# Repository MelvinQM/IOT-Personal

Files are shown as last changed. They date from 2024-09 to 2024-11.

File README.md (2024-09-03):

# IoT Start Project

This is your IoT Gitlab project. You can use it to store your code and documentation. 

## Getting Started

This project contains a setup using Docker. This will help you setup all the necessary tools to start developing your IoT project.
Before you run the docker-compose command, make sure you have to make changes to the configuration. You can find these in
the `.env` file.

Now, to install and start your project; run the following command in the root of your project:

```bash
docker-compose up -d
```

If everything runs correctly, you should be able to visit your website at [http://localhost/](http://localhost/).

## Structure

There is a specific structure that you should follow when developing your project. This will help you to keep your project organized and easy to understand.

**Documentation**

All the documentation of your project should be placed in the `docs/` folder. This will be used for your portfolio-website.

```bash
├── docs/
```

**Embedded**

Everything you need to run your embedded application should be placed in the `embedded/` folder. This includes the source code like .ino-files from Arduino.

```bash
├── embedded/
```

**Web**

Everything you need to run your web application should be placed in the `web/` folder. This includes the source code like PHP, HTML, CSS, Javascript and images.

```bash
├── web/
```

You can visit your website by going to [http://localhost/](http://localhost/) in your browser. And you can find your IoT dashboard at [http://localhost/dashboard](http://localhost/dashboard).

## Database details

The database is a MySQL database using MariaDB. You can connect to it using the following details:

| Parameter | Value |
| --- | --- |
| Host | `mariadb` (from PHP) `localhost` (from your laptop) |
| Port | `3306` |
| Username | `root` |
| Password | You can find this in your .env-file. |
| Database | You need to create the database yourself. |

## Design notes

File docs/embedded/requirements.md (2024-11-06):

# Requirements

## Contents
1. **[Embedded Requirements](#1-embedded-requirements)**
2. **[HTTP Client (EMBRQ#01)](#2-http-client-embrq01)**
3. **[HTTP Server (EMBRQ#02)](#3-http-server-embrq02)**
4. **[Inputs (EMBRQ#03)](#4-inputs-embrq03)**
5. **[Outputs (EMBRQ#04)](#5-outputs-embrq04)**
6. **[WiFiManager (EMBRQ#05)](#6-wifimanager-embrq05)**

## 1. Embedded Requirements
One of the given assignments for the minor IoT was to create an Embedde device. This device has to fulfill these 5 embedded requirements (EMBRQ):

| Requirement ID | Requirement | MoSCoW | Compliant |
|---|---|---|---|
| EMBRQ#01 | The embedded device acts as a client and sends measured sensor data to the application backend over HTTP or HTTPS. | MUST | YES |
| EMBRQ#02 | The embedded device also acts as a server and receives status messages from the application backend over HTTP or HTTPS. | MUST | YES |
| EMBRQ#03 | The embedded device contains at least two types of input sensors (e.g., LDR, buttons, joystick, capacitive touch, etc.). | MUST | YES |
| EMBRQ#04 | The embedded device contains at least two types of visual and/or sensory outputs (e.g., LED, LED Matrix, 7-segment display, motor, servo, actuator, LCD-screen, buzzer, etc.). | MUST | YES |
| EMBRQ#05 | The embedded device uses the WiFiManager for configuration of SSID and password (PWD) for connecting to the network. | MUST | YES |

## 2. Accomplishments

### 2.1 HTTP Client (EMBRQ#01)
[Code Documentation](code#221-api-connection-through-wifimanager)

To fulfill the requirement of having the Embedded device serve as an HTTP client a connection with the API was established. The class defined in the Game Console `Connections.cpp` has functionality to `POST`, `PATCH` and `GET` various data. 

Methods Utilized in `Connections.cpp`:

- `fetchPlayers()`: Sends a GET request to retrieve a list of players from the API. This method returns player data that can be used to verify player existence or retrieve player statistics.
- `getSessionById()`: Sends a GET request with a specific session ID to retrieve the session details. The response includes session information, such as the session ID, associated player ID, and any other relevant session data. This method is crucial for polling until a session is associated with a player.
- `getHighscores()`: Sends a GET request to fetch the list of high scores. This method retrieves the top scores across all sessions and players, displaying leaderboard data on the game console's screen.
- `createScore()`: Sends a POST request to submit a new score to the API. This method takes the player’s score and session ID as inputs, creating a score record in the database for tracking gameplay performance.
- `createSession()`: Sends a POST request to start a new session for the game. The API responds with a session ID, which is polled until the game can confirm a valid session setup.
- `endSession()`: Sends a PATCH request to mark a session as ended. This method updates the session status, ensuring no further game actions can be recorded for that session.

createPlayer(): Sends a POST request to add a new player to the database. This method is called when a new player registers for the game, ensuring that the player data is stored for future sessions and scores.

### 2.2 HTTP Server (EMBRQ#02)
[Code Documentation](code#221-api-connection-through-wifimanager)

The requirement is achieved through continuous polling mechanisms for session and player creation.

**Session Creation**:
The device repeatedly invokes createSession() until a valid session ID is returned. This polling mechanism ensures that the game initializes with a unique session for each player.

**Session and Player Binding**:
After obtaining a session ID, the game console polls getSessionById() until the session object contains a player_id. This ensures that the game session only starts when a player has been connected through the frontend form.

Methods Utilized in `Connections.cpp`:

- `createSession()`: Initializes a new game session by sending a POST request to the API. This method is polled until a session ID is retrieved.
- `getSessionById()`: Retrieves session details, checking if a player_id has been linked to the session. Polling continues until this association is confirmed.

### 2.3 Inputs (EMBRQ#03)
To fullfill the requirement of having at least two types of input sensors (e.g. LDR, buttons, joystick, capacitive touch, etc.). I established functionality for various inputs:

- Gyroscope (MPU6050): For the use of player movement controls.
- Joystick: For the use of player movement controls.
- Button: For the use of player trigger/fire controls.

[MPU6050 code](code#23-gyroscope)

[Joystick code](code#24-joystick)

[Button code](code#25-button)

### 2.4 Outputs (EMBRQ#04)
To fullfill the requirement of having at least two types of visual and/or sensory outputs (e.g. LED, LED Matrix, 7-segment display, motor, servo, actuator, LCD-screen, etc.). I established functionality for various outputs:

- Display: For the use of a all game visuals and gameplay.
- RGB LED indicator: For the use of notifying the user and developers of the console state.
- Vibration Motor/Rumble Pack: For the use in the controller for feedback upon firing.

[Display code](code#27-sprite-rendering)

[RGB LED code](code#28-rgb-led)

[Vibration Motor code](code#26-vibration-motor)

### 2.5 WifiManager (EMBRQ#05)
[Code Documentation](code#221-api-connection-through-wifimanager)

To fulfull the requirement of having a connection to wifi through the use of WiFiManager in favor of just using `WiFi.begin()`. The use of the library WiFiManager was added. Through the use of its autoconnect feature the device will now connect automatically to any network that it remembers. If no network could be found instead of the device not functioning at all instead it will open a portal on its own accesspoint that you can join through your phone or computer. On this portal you can then add the accesspoint of your choosing.

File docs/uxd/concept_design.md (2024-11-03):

# Concept & Design

## Contents
- **[1. Concept](#1-concept)**
    - **[1.1 User Needs](#11-user-needs)**
    - **[1.2 Product Requirements](#12-product-requirements)**
    - **[1.3 Controller Concepts](#13-controller-concepts)**
    - **[1.4 Console Concepts](#14-console-concepts)**
- **[2. Design](#2-design)**
    - **[2.1 Software Decisions](#21-software-decisions)**
    - **[2.2 Controller Prototypes](#22-controller-prototyping)**
    - **[2.3 Console Prototypes](#23-console-prototyping)**

## 1. Concept
The concept for my project is to make a game similair to Duck Hunt. Where the player will be provided a controller and a display. Instead of using the traditional way I will be trying to put my own spin on it. The traditional way is by using an optical sensor in the gun/controller that when pressed will see if it is pointing at a portion of the screen that's white. This is made possible by making the screen go dark except for the duck's hitbox when pressing the trigger. The moment the screen flickers and the sensor sees a white spot on the screen it has hit a duck. 
<div align="center">
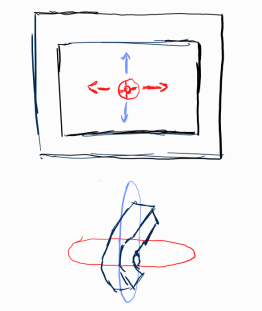
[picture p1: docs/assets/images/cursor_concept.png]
  
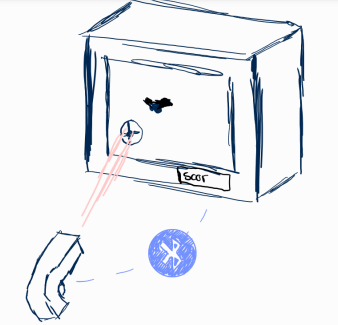
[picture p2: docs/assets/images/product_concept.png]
productconcept
  
</div>

I wanted to put my own spin on it. The controller will have a gyroscope in it allowing it to serve as a motion controller. Similair to the Wii but not exactly as the wii uses a different technique. I wish to emulate the ease of use of the Wii controller but using a different technique.

Additionally the controller will be wireless and communicate with the display through an UDP connection. This will allow the controller to tell the display where to move the cursor.

### 1.1 User Needs
- **Inclusive Age Range**: The system should cater to users of all ages, from retro game enjoyers of old to young kids. This allows more people to enjoy the product and increase the amount of possible users.
- **Ease of Use**: The system must be simple to operate for users of different experience levels. Allowing an ease of access will allow more people to have fun playing the game which is the most important goal.
- **Fun Factor**: The primary goal is to ensure that the gaming experience is enjoyable for everyone. If the game is fun to play more people will be interested in attempting to play the game.
- **Non-Violent Design**: The controller design should avoid looking violent. It must not resemble a traditional gun. Since guns have a negative conotation it is essential to keep away from these kind of topics.
- **Comfortable Grip**: The handle of the controller must be appropriately sized to accommodate users of all ages and hand sizes. Allowing more people to be able to hold the controller allows for more possible players.

### 1.2 Product requirements
1. Setup Time
    - **Specific**: Users must be able to set up the game console with clear, step-by-step instructions.
    - **Measurable**: Setup should take no longer than 10 minutes from off to operational state.
    - **Achievable**: Instructions will include visual aids and step-by-step instructions.
    - **Relevant**: This ensures user satisfaction and a positive first experience.
    - **Time-bound**: The setup process should be tested and validated within the ten weeks of development.

2. Controller Design
    - **Specific**: The controller design must be non-violent and visually appealing to a broad demographic.
    - **Measurable**: Conduct surveys with at least 5 potential users to get opinions on appeal and ensure it resonates with all ages.
    - **Achievable**: There will be multiple iterations on concepts based on feedback within the 10 week development time.
    - **Relevant**: This is crucial for players across age groups.
    - **Time-bound**: Final design will be completed within 10 weeks.

3. Ergonomic Comfort
    - **Specific**: The wireless controller should be easy to hold for both children and adults.
    - **Measurable**: User testing with a sample size of at least 5 individuals across different age groups to assess comfort levels on a 1-10 scale.
    - **Achievable**: Feedback will be collected and incorporated into the design in two iterations over a four-month period.
    - **Relevant**: Comfort is important for user satisfaction and prolonged playtime.
    - **Time-bound**: Assessments will be conducted within the initial 10 weeks of development.

4. WiFi Connection Stability
    - **Specific**: The controller must maintain a stable connection to the display.
    - **Measurable**: The connection must not drop within a 10-meter range during continuous gameplay for at least 95% of the time.
    - **Achievable**: Testing in various environments to ensure reliability.
    - **Relevant**: A stable connection is essential for a smooth gaming experience.
    - **Time-bound**: Connection stability testing should be completed by the end of the development within 10 weeks.

### 1.3 Controller concepts
The controller is one of the most important elements of this entire projects. Having a solid concept is essential for the project to feel complete.
Below some concepts can be seen.
<div align="center">
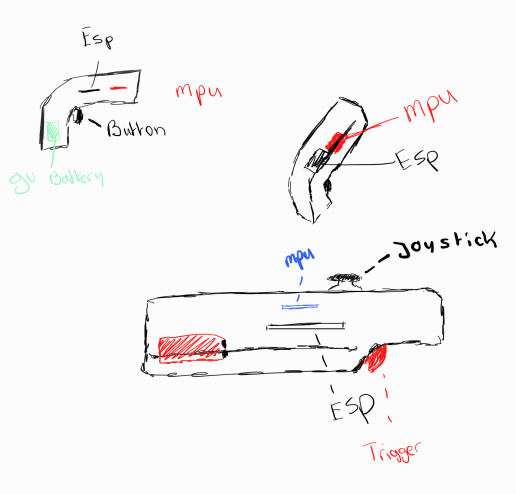
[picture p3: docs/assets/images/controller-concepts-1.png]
  
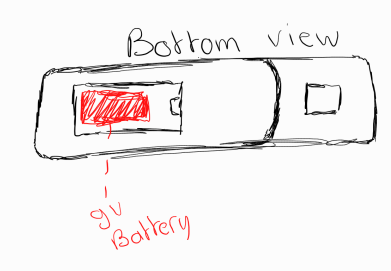
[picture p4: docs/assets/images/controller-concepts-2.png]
  
</div>
<br>
<div style="display: flex; align-items: center;">
  <div style="flex: 1;">
    An additional idea is to allow the controller to be plugged into an attachment to give it more of a gun feel. This allows the controller to be more multi purpose incase of additional games, but still allow it to be fitting for the main game being worked on.
  </div>
  <div style="flex: 1; text-align: right;">
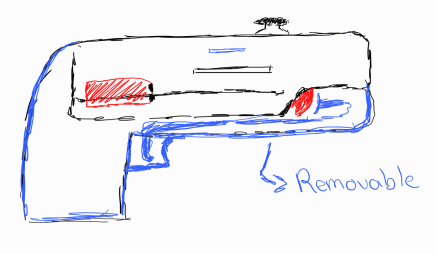
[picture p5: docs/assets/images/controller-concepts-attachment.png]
    
  </div>
</div>
<br>

### 1.4 Console concepts

One of the inspirations for designing the console was from looking at existing 3d models. I came across the following model which seemed like a good fit. [Link]("https://cults3d.com/en/3d-model/gadget/fix-it-felix-jr-cabinet-with-lithophane")
<div align="center">
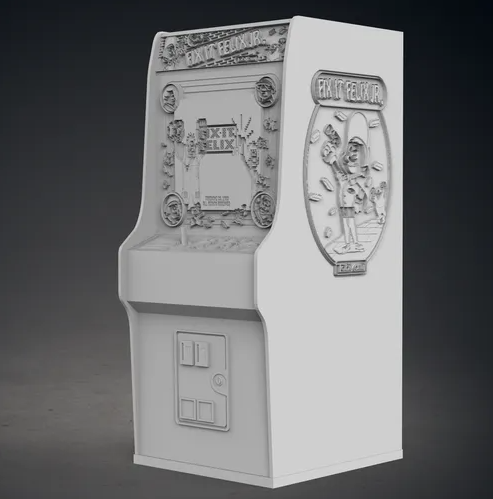
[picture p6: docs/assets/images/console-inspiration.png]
console-inspiration
  
</div>

The console is modeled after a classic arcade cabinet. This cabinet is modeled around the ESP32 display more about this display can be found in the [Embedded Technical Documentation](../embedded/technical_documentation.md#431-esp32-2432s024-esp-display)

### 1.5 Materials
For the purpose of designing and manufacturing a controller and console. The most important factor was being able to make a creative and functional product. This is why a 3D printed design was the most logical option. The controller can be made to have any kind of shape using 3D printing while techniques such as laser cutting would be a lot harder to make work for this purpose. 

## 2. Design

### 2.1 Software decisions

#### 2.1.1 Fusion360
- **Purpose:** Fusion360 is a cloud-based 3D CAD, CAM, and CAE tool for product design and manufacturing, enabling users to create and simulate complex models.
- **Decision for Choosing:** Chosen for its vast amount of features and prior experiences with this program.

#### 2.1.2 Fritzing
- **Purpose:** an open-source software that allows users to design and document electronic circuits, providing a platform for creating schematic diagrams and PCB layouts.
- **Decision for Choosing:** Selected for its user-friendly interface and accessibility for beginners in electronics. This software might be replaced to Fusion Electronics if designing a PCB is in the future plans as I've used Fusion for this in the past.

#### 2.1.3 Aseprite
- **Purpose:** Aseprite is a pixel art program that allows users to create 2D graphics and animations, focusing on pixel art.
- **Decision for Choosing:** A program was required to make low pixel count graphics that low memory for storing on an embedded device.

#### 2.1.4 Bambu Studio
- **Purpose:** Bambu studio is the slicer for the Bambu X1 Carbon 3d printer used in this project.
- **Decision for Choosing:** Bambu studio is the best way to interface with the X1C printer as it is the company's own 3D printing slicer specifically made to use for their printers.

### 2.2 Controller Prototyping
#### 2.2.1 Basic shape
To create the basic shape of the controller a fusion360 tutorial was used. Although this tutorial was in spanish I muted the audio and was still able to follow along quite nicely using the automatically generated subtitles. [Wii controller fusion tutorial](https://www.youtube.com/watch?v=6r9C27qcxtE&ab_channel=LuisAmaya)

This model was to create a basic shape for the controller. 
<div align="center">
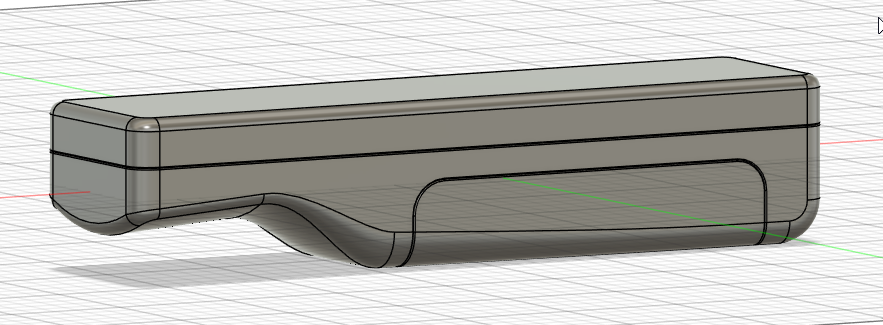
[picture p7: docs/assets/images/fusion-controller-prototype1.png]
fusion-controller-prototype
  
</div>
I then moved around all components around to see if everything would fit. *(This did not include the trigger yet so the spacing might not be correct here)*
<div align="center">
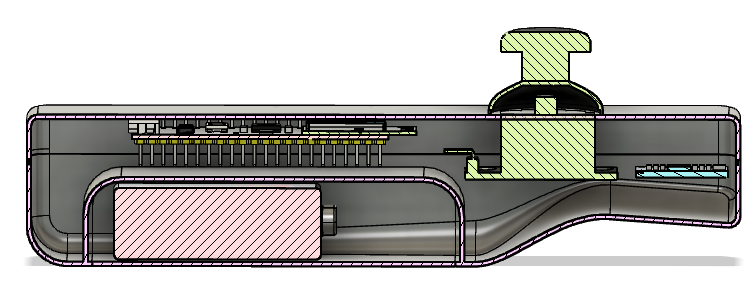
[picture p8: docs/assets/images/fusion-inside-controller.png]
inside-controller
  
</div>

#### 2.2.2 Trigger mechanism

<div style="display: flex; align-items: center;">
  <div style="flex: 1;">
    One of the most important elements of the design was the trigger button. I opened up a wii controller to see how this was handled. I noticed that the button was loose and was connected using a T join see picture below.
  </div>
  <div style="flex: 1; text-align: right;">
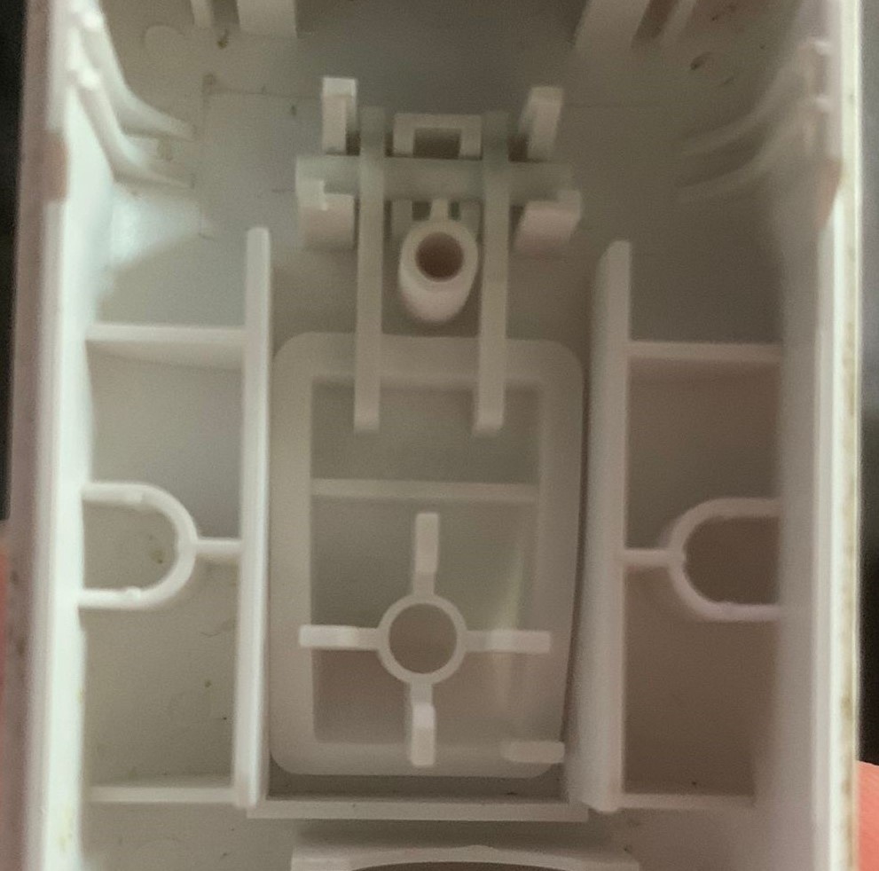
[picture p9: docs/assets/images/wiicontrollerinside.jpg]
wiicontrollerinside
    
  </div>
</div>
<br>
<div style="display: flex; align-items: center;">
  <div style="flex: 1;">
    This joint allows the button to move up and down to press a button. I worked on making a system similair to this. I changed the button to have a sharper edge to allow for easier shooting. The wii controller has a softer edge which could lead to your finger sliding off easier when rapid firing.
  </div>
  <div style="flex: 1; text-align: right;">
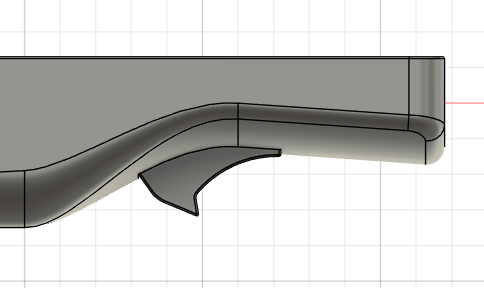
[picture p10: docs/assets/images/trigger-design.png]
trigger-design
    
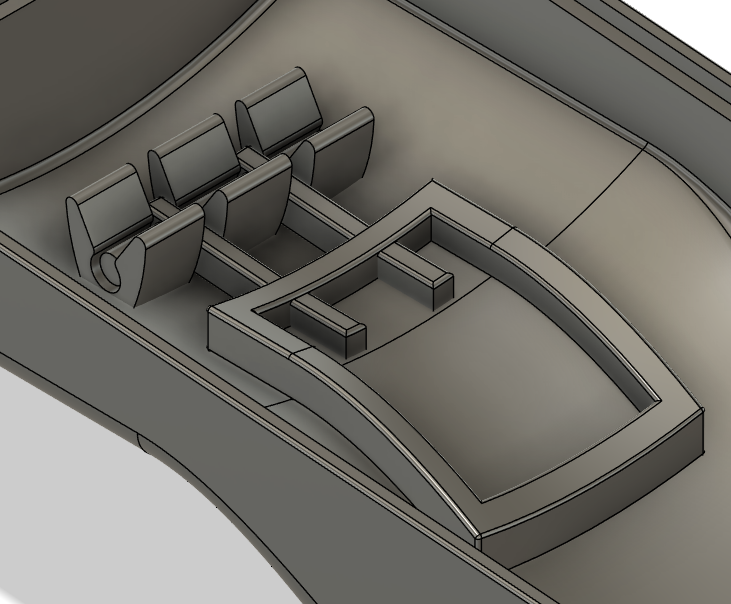
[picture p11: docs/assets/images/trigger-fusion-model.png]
trigger-fusion-model
    
  </div>
</div>
<br>
<div style="display: flex; align-items: center;">
  <div style="flex: 1;">
    After testing with this design through a few iterations a satisfying result was created to allow the trigger to press a switch. 
  </div>
  <div style="flex: 1; text-align: right;">
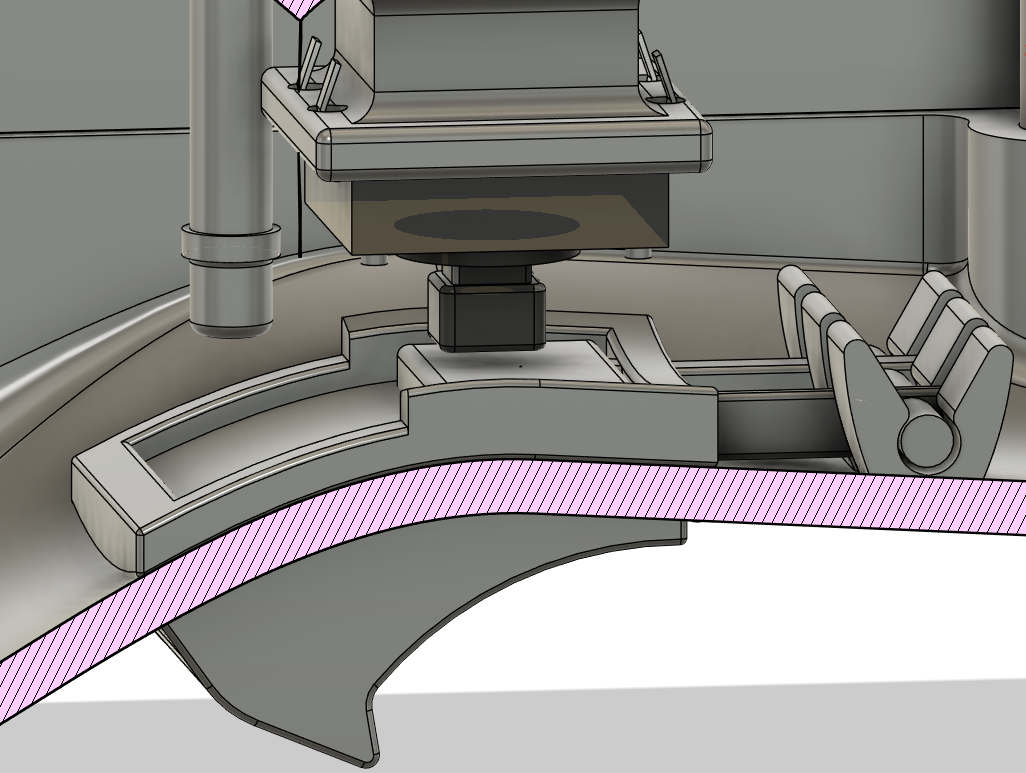
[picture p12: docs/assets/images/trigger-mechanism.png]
trigger-mechanism
    
  </div>
</div>

[Trigger prints can be found here](create_test.md#222-trigger-mechanism)

#### 2.2.3 Joystick Holder
The controller will also have a joystick on the top. To fasten this component a very simple push fit mechanism was used.
<div style="display: flex; justify-content: center; align-items: center;">
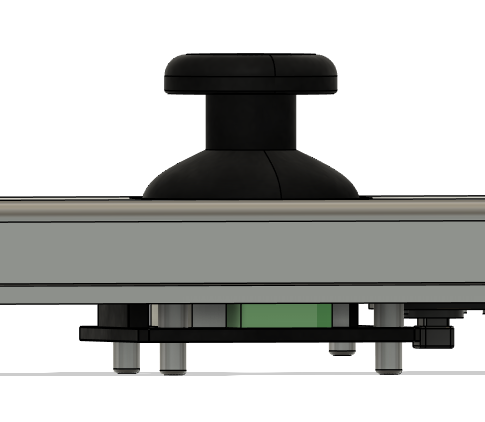
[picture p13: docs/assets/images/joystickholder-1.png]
joystickholder-1
  
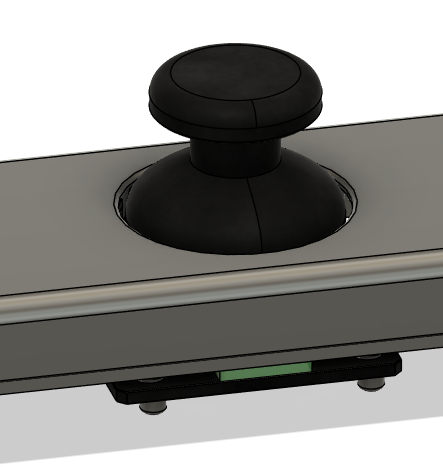
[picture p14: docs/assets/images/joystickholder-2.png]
joystickholder-2
  
</div>

#### 2.2.4 Vibration Motor Holder
The vibration motor had an interesting requirement. The vibrating part had to be against a wall of the print to allow the vibrations to better travel through the plastic and to the player holding it. For that reason the motor was placed at the back facing a wall. The motor is fastened using a slide push fit mechanism.
<div style="display: flex; justify-content: center; align-items: center;">
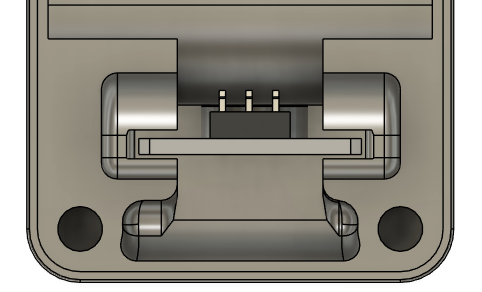
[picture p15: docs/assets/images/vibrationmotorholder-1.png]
  
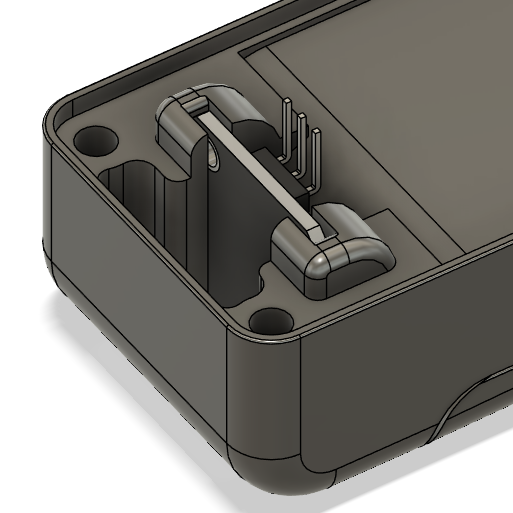
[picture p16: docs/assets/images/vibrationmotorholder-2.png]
  
</div>

#### 2.2.5 MPU6050 Holder
<div style="display: flex; align-items: center;">
  <div style="flex: 1;">
    The holder for the MPU6050 was fixed to the top half of the controller and is fairly simple. The MPU has 2 holes meant for screwing it into constructions since the design did not allow for screws unless the print would be made significantly larger. This is why simple push fit "nubs" were used.
  </div>
  <div style="flex: 1; text-align: right;">
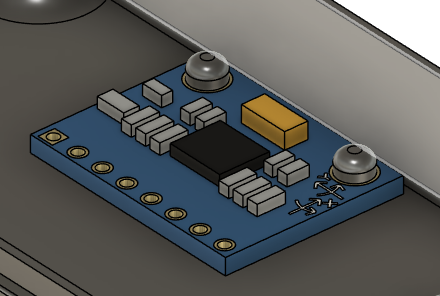
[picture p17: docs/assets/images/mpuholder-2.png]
mpuholder-2
    
  </div>
</div>

#### 2.2.6 DC-DC Converter Holder

<div style="display: flex; align-items: center;">
  <div style="flex: 1;">
    The DC-DC converter is fastened the same way the MPU is. This similarily is fastened to the top half of the controller. Considerations were made to ensure the input of this converter was facing towards the battery cables to reduce the distance between them.
  </div>
  <div style="flex: 1; text-align: right; margin-left: 4px;">
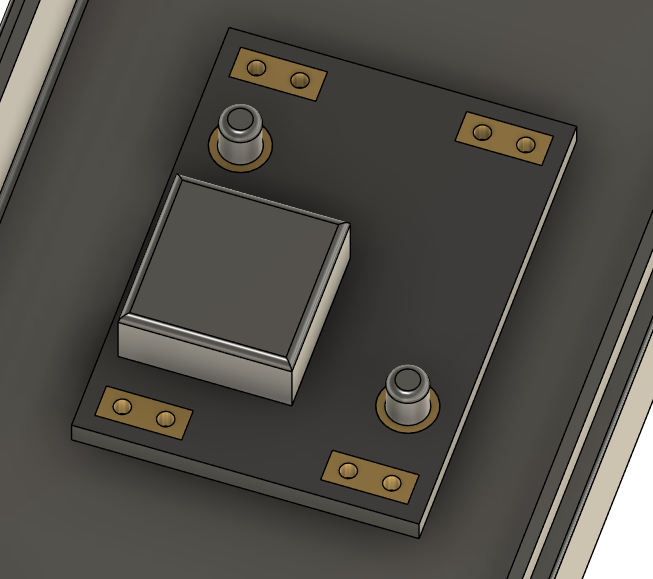
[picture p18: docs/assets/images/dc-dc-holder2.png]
dc-dc-holder2
    
  </div>
</div>

#### 2.2.7 Battery Holder

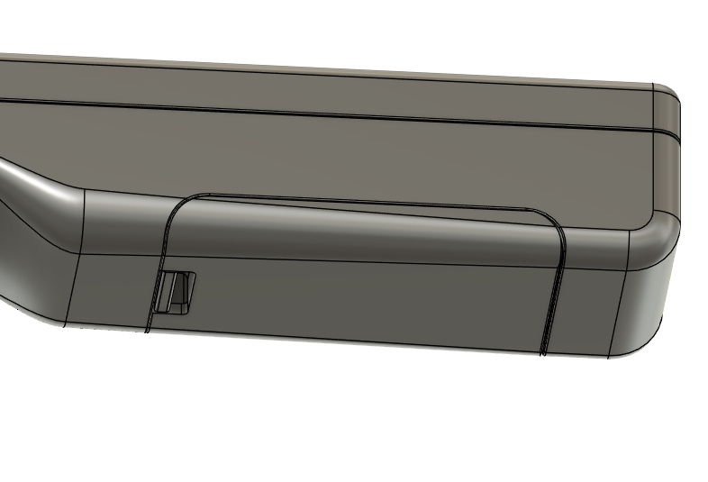
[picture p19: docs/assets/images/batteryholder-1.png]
batteryholder-1


<div style="display: flex; align-items: center;">
  <div style="flex: 1;">
    To hold in a battery in the battery compartment, a battery lid mechanism was designed. By looking at the Wii controller as inspiration a similair mechanism was designed. This mechanism is also used in many television remotes. The basic idea is to use 2 nubs at the back to fast the lid into position first then to close it the front lid bends slightly to fit into place. Once into place it can be removed by bending this same front lid back and then pull it out.
  </div>
  <div style="flex: 1; text-align: right;">
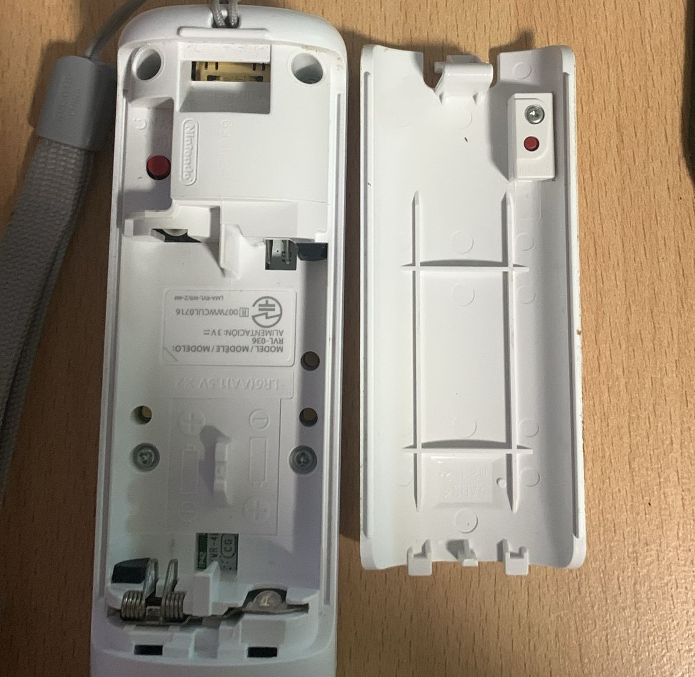
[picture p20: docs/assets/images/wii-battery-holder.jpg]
wii-battery-holder
    
  </div>
</div>
<br>
<div style="display: flex; align-items: center;">
  <div style="flex: 1;">
    It allows for a small latch that can be openend with the use of a finger nail or a flat head screw driver or something similair. (The plastic used PLA was quite tough and doesn't bend like the traditional remote material. Using a screwdriver is reccomended because of this.)
  </div>
  <div style="flex: 1; text-align: right;">
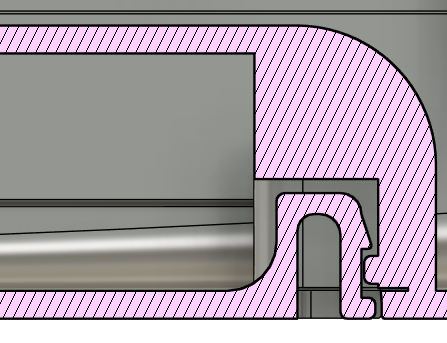
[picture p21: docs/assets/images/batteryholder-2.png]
batteryholder-2
    
  </div>
</div>
<br>
<div style="display: flex; align-items: center;">
  <div style="flex: 1;">
    The battery holder is fit into place using three mechanisms the latch in the front specified earlier. 2 nubs on the back to fit the lid into position.
    And a railing on the side to make sure the battery lid is positioned correctly and doesn't shift.
  </div>
  <div style="flex: 1; text-align: right;">
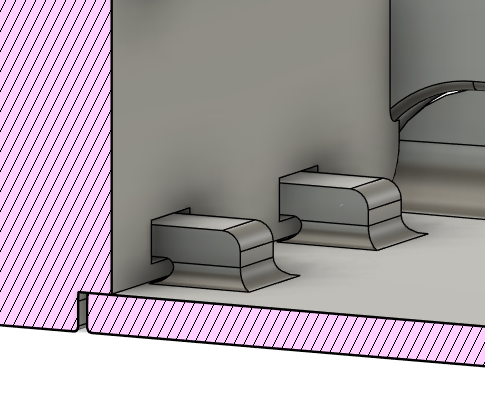
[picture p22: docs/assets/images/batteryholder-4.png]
batteryholder-4
    
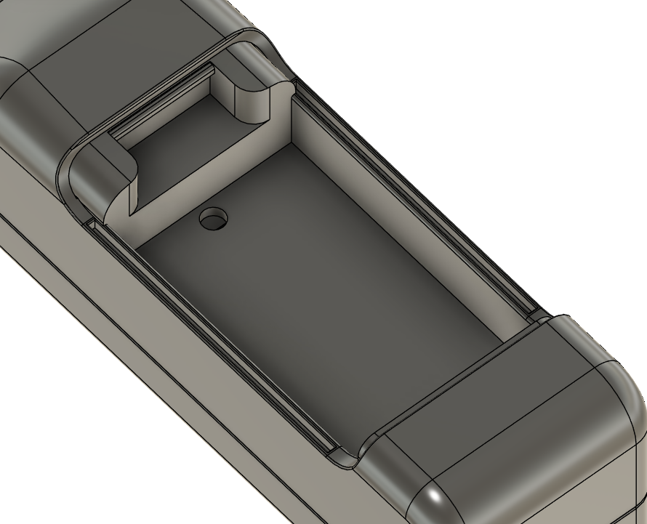
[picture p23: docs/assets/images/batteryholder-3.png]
batteryholder-3
    
  </div>
</div>

#### 2.2.8 Current Controller Design
<div style="display: flex; flex-direction: column;justify-content: center; align-items: center;">
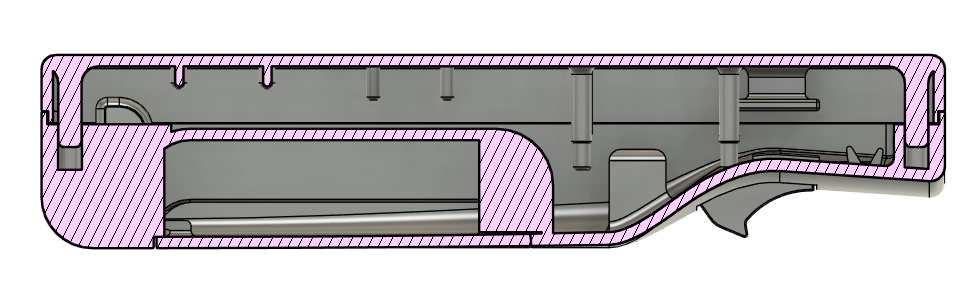
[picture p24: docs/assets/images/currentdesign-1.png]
currentdesign-1
  
  currentdesign-2
</div>

#### 2.2.9 Prototype Breadboard Controller Design
To perform functionality testing the motion controller design above isn't quite optimal. As all the components take up quite a bit of space with wiring reliably testing with components can be quite the challenge. That's why the following controller design was made. It is designed to be a simpler version which can be easily open and closed. By allowing a breadboard to fit experimenting is quite a bit easier.

<div style="display: flex;">
  breadboard-controller-design-1
  breadboard-controller-design-2
</div>

The top and bottom are fitted using 4 push fit holes on the 4 corners and by using the same design for the joystick holder used for the previous motion controller 

### 2.3 Console Prototyping
I started off modeling the chosen display in Fusion360 with accurate measurements to make it easier to design a container around it.
<div align="center">
  espdisplaymodel
</div>

#### 2.3.1 Basic shape
<div style="display: flex; align-items: center;">
  <div style="flex: 1;">
    The basic shape of the console was created using the previous mentioned model as reference. The display has been tilted 10 degrees to allow for easier viewing from a top angle as the console will be quite small.
  </div>
  <div style="flex: 1; text-align: right;">
    consolemodel-1
  </div>
</div>

#### 2.3.2 RGB Led
<div style="display: flex; align-items: center;">
  <div style="flex: 1;">
    To allow the RGB led which is used as an indicator light to provide the user or developer to see the status of the system. A hole was made to allow the light to shine through the enclosure.
  </div>
  <div style="flex: 1; text-align: right;">
    consolemodel-2
  </div>
</div>

#### 2.3.3 USB-C 
<div style="display: flex; align-items: center;">
  <div style="flex: 1;">
    To power the system the use of a usb-c cable is required. To allow for a seamless way to plug this cable in a hole was added with enough tolerance to fit most usb-c cables.
  </div>
  <div style="flex: 1; text-align: right;">
    consolemodel-3
  </div>
</div>

#### 2.3.4 Enclosure assembly
<div style="display: flex; align-items: center;">
  <div style="flex: 1;">
    The enclosure is divided in two halfs. These halves connect through the use of 4 push fit nubs. By allowing for a small amount of tolerance these will allow for opening and closing of the console.
  </div>
  <div style="flex: 1; text-align: right;">
    
    
  </div>
</div>

#### 2.3.5 Banner
<div style="display: flex; align-items: center;">
  <div style="flex: 1;">
    To add some final bit of creativity to the console I added these banners. The banners are printed on its own and slides into the console. This also allows for modularity with the banners to hotswap if needed for example if a new game is able to created one day.
  </div>
  <div style="flex: 1; text-align: right;">
    
  </div>
</div>

#### 2.2.8 Current Console Design
<div style="display: flex; justify-content: center; align-items: center;">
  currentdesign-console-1
  currentdesign-consolen-2
  currentdesign-console-3
</div>

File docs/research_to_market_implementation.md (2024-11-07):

# Implementations & Results

From researching various methods for communicating between an ESP32 Controller and a ESP32 Display various implementations were achieved. Some of these implementations can be found in the [research](research_to_market#4-implementations-and-results) itself.

The main implementation drawn from the research is that using ESP-NOW works quite well for this project. You can also find more about this implementation in the [Code](/embedded/code#222-esp-now) documentation.

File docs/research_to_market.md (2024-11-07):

# Research to market

- **[1. Introduction](#1-intro)**
- **[2. Research Question](#2-research-question)**
- **[3. Research Method](#3-research-method)**
- **[4. Implementations and Results](#4-implementations-and-results)**
- **[5. Conclusion](#5-conclusion)**
- **[6. Recommendations](#6-recommendations)**
- **[7. References](#7-references)**

## 1. Intro
During my Minor in Internet of Things I was tasked with making an IoT device. There were some "blueprints" that I could choose from. I ended up choosing the game console blueprint. This blueprint involved creating an Embedded device which would serve as the game. This device needed to connect to an API which handled storing data from sensors and possibly from the game itself into a database. This data has to than be shown on a frontend website. This was the bare minimum required for the project. 

One of my first ideas was to make some sort of motion controller. This idea seemed like a fun project as I could easily introduce new games and functionalities to the controller later on. This controller primarily revolves around a trigger/button that could invoke a reaction on screen and a gyroscope to handle the movement of a digital cursor on screen. The basic idea of having a controllers gyroscopic angles being able to control a cursor on screen is a very expandable idea and made for a perfect route to take my project. The game that fits this gameplay the best is Duck Hunt.

## 2. Research question
A question that arose during the development was how to ensure the communication between the controller and the console. This was crucical for the game's feel and reliability. The following question arose from this thought:

**What is the best method for establishing efficient and reliable communication between an ESP32 display and an ESP32-S3 controller to enable smooth data transmission for a motion-controlled game?**

Subquestions:

- What are some techniques used in existing controllers?
- What techniques are available for wireless communication between two ESP32 devices?
- How can these techniques be implemented in an Arduino environment?

## 3 Research method
To answer the questions a few research methods will be used:

- Literature Review: Investigated existing motion controllers and communication methods.
- Experimental Testing: Conducted trials with different techniques to determine which was best suited for the project.
- Prototype Development: Developed a prototype for each communication method, documenting successes and challenges.

## 4. Implementations and results
### 4.1 Existing motion controllers on the market.
In hopes to answer the sub question "What are some techniques used in existing controllers?" I looked into some products that already exists.
<div style="display: flex; align-items: center;">
    <div style="flex: 1;">
        duckhuntbox
    </div>
    <div style="flex: 1;">
        <h4>Duck Hunt Light Gun</h4>
        <p>Duck hunt was a game for the NES which made use of a so called light gun to shoot flying by ducks on screen. The game was released back in April of 1984 in Japan and later in October 1985 in America. Duck hunt's gameplay involved shooting ducks and clay pigeons. The player got 3 attempts per round to get a certain number of hits or get a gameover. </p>
        <p><span style="font-weight: bold;">Technical Details:</span>The game worked by leveraging the CRT tv technology of the time. The gun consists of a trigger and a photodiode(light sensor). When the trigger is pressed the screen will go black for one frame except for the duck. The duck would light up white causing the light sensor "if aimed correctly" to sense the duck and register it as a hit.</p>
        <p style="font-weight: bold;">Keypoints: Screen flicker, Light sensor</p>
    </div>
</div>

<br>
<hr>

<div style="display: flex; align-items: center;">
  <div style="display: flex; flex-direction: column; justify-content: center; align-items: left; width: 50%;">
      wii-controller
      wiimotionplus
  </div>
  <div style="flex: 1;">
    <h4>Wii Motion Controller</h4>
    <p>The wii motion controller is the signature controller for the Nintendo Wii which released worldwide in 2006. The Wii controller was used for motion control games such as Wii Sports and other wii games. It allowed a digital cursor to be shown on screen based on the angle you pointed the controller at a sensor bar. It also allowed for motion controls such as registering movements such as; shaking, swinging and more.</p>
    <p><span style="font-weight: bold;">Technical Details:</span> Using 2 different systems make motion controls possible; the linear accelerometer and infrared sensor. The linear accelerometer measures the acceleration of gravity when tilted it doesnt receive the full force of gravity onto the sensor allowing to measure the tilt of the controller. It does this in 3 axis to sense the orientation of the wii remote. Later in the lifespan of the Wii the wii motion plus was introduced. This was an optional addition that cold be plugged into the wii controller. This device has a gyroscope that accomplishes a similair result as the accelerometer that is more accurate. The position of the controller relative to the screen is done using the infrared sensors. The Wii is fitted with a infrared light source known at the sensor bar. This bar has 5 infrared lights on both sides. Measuring the position of the two sources on the sensor allows the controller to be able to determine the angle the light is coming from. All of this data would then be transfered to the console through the use of Bluetooth. </p>
    <p style="font-weight: bold;">Keypoints: Accelerometer, Gyroscope, Infrared Sensor, Bluetooth</p>
  </div>
</div>

### 4.2 Techniques for wireless communication between two ESP32 devices.
In hopes to answer the sub question "What techniques are available for wireless communication between two ESP32 devices?" I looked into some products that already exists.
#### 4.2.1 Bluetooth (BLE)
BLE is suited for data transfers that are more bursty and don't require high bandwith. The range of Bluetooth varies on the configuration used. From a few meters to over a kilometer. Using the FEC (Forward Error Correction) the range of a kilometer is made possible. Something to keep in mind is that range and data throughput are not mutually exclusive. For example if you go for a higher range you are reducing the max data throughput.

##### 4.2.1.1 Peripherals and Centrals
A peripheral is the device that sents out "advertisement" data to other devices to discover it. Central is the device that discovers "advertisements" and if the advertisement allows it connects to it.

##### 4.2.1.2 Advertisements and Scanning
When a peripheral sends data called advertisement packets for other devices to discover it. This could lead to discovery or simply just to let the other device read the advertisement data. The central is continously scanning advertisement channels for new advertisement packets from other devices. Some advertisement packets allow connections some are only meant to send out advertisement data.

You can expect to receive the following data from an advertisement packet (Not in all cases):

- Device name
- TX Power level (Transmit power standard BLE: 0dBm)
- Service supported by device
- Appearance ID (Identifies the type of device)

##### 4.2.1.3 Connection
To connect a device to a BLE device a few things need to happen:

- Peripheral starts advertising
- Central scanning for advertisements
- Central needs to send a connection request
- Peripheral responds
- Connection established!

##### 4.2.1.4 Services and Characteristics (Attributes)
How a BLE device organizes and structures the data that it exposes to other devices to discover it. A characteristic represents a piece of information or data that a BLE device wants to expose to other devices. An example of this is sensor data. Another example is a characteristic for allowing another device to control the behaviour of the BLE device.

A service is a grouping of one or more characteristics. Example of this having environmental data like air quality humidity and temperature all represented by a characteristic but grouped into one service called "Environmental Service".

#### 4.2.2 UDP & TCP
Another way of sending data between two ESP32's is by using a wifi connection. Through the use of of wifi many options are available the once looked at were UDP & TCP.

##### 4.2.2.1 UDP
Like all networking protocols UDP is a standaridzed method for transferring data between two devices in a network. UDP is comparatively a lot simpler than most protocols it sends packets (data) directly to the target device without needing a connection. The packets can arrive at a high speed but since there is no connection between the devices you are limited to a one way communication method using UDP. UDP is most used in time sensitive technologies where losing some packets is better than having to wait for the data to arrive. Some common uses for UDP consist of Video streaming, and VoIP (voice over ip) which is a internet based telephone service.

##### 4.2.2.2 TCP
Another way of sending data through a wifi connection is through the use of  TCP or Transmission Control Protocol. TCP together with another protocol namely IP internet protocol is able to send data to a sender while keeping a conneciton between the sender and receiver. The TCP/IP relationship is like sending someone a message that is written on a puzzel through the mail. The puzzle is broken into pieces and each piece then travels through a different route, some of which take longer than others. When the puzzel arrives after traveling through all these routes the packets might be out of order. TCP is then responsible for assembling the puzzle on the other side it will then make sure the order is correct, if there are any missing packets that they get resent and it lets the sender know the puzzle was received. The TCP connection cosists from the moment the first packet is sent to after the final piece is sent.

##### 4.2.2.3 UDP v TCP
The difference between UDP and TCP lies primarily in the handshake the TCP has to do. UDP packets are sent continuously without the need of this. UDP is faster but less reliable because of this. The speed of UDP also has some tradeoffs if a packet is lost in transit it will not be re-sent so for example for messages that are critical to be received this created some risk of losing that data. In the case of the data being crucial the use of TCP would be preferred.

<div align="center">
  TCPvUDP
</div>

#### 4.2.3 ESP-NOW
##### 4.2.3.1 What is it?
ESP-NOW is a communication protocol based on the data-link layer. This reduces the layers of the OSI model from 5 to only one. This allow for data to be transmitted through through the network, transport, session, presentation, and the application layer. There is also no need for packet headers or unpackers on each layer. All of this allows for a quick response reducing the delay caused by packet loss on busy networks.

<div align="center">
  TCPvUDP
</div>

##### 4.2.3.2 Limitations

Althought ESP-NOW sounds perfect for the situation at hand it is important to also look at the limitations provided with using this protocol.

- **Limited Range**: The range is stated by Espressif to reach around **220 meters** under ideal conditions. However, the actual range can vary based on various interferences..
- **Interference**: ESP-NOW operates in the **2.4 GHz band**. This can cause it to experience interferences from other wireless devices and Wi-Fi networks.
- **No Message Acknowledgment**: There is no built-in acknowledgment mechanisms for confirming message delivery. If message reliability is essential, custom acknowledgements will have to be implemented.
- **Limited Data Payload**: ESP-NOW is optimized for small data transmissions, with a **maximum payload of around 250 bytes**. For applications that need high-bandwidth data transfer or larger file exchanges, services like **Arduino Cloud** might be better suited.
- **No Network Infrastructure**: ESP-NOW supports **point-to-point** and **point-to-multipoint** communication but lacks the infrastructure for building complex network topologies. If your application requires a multi-device network or Internet connectivity, consider using additional networking solutions alongside ESP-NOW.
- **Security Considerations**: While ESP-NOW offers basic data security and privacy, it is not as secure as protocols like **HTTPS** or **MQTT** with strong encryption. For projects involving sensitive data, custom security measures will need to be developed to guard against data eavesdropping and unauthorized access.
- **Compatibility**: ESP-NOW is primarily designed for **ESP8266** and **ESP32** microcontrollers. While it can be used with other ESP32-based devices, compatibility with non-ESP platforms may vary.

### 4.3 Implementing techniques in an Arduino environment
In hopes to answer the sub question "How can these techniques be implemented in an Arduino environment?" I looked into some products that already exists.
#### 4.3.1 Bluetooth
To implement a bluetooth connection on the project first off a library to manage all the bluetooth connection was used. The library that can be used for this is is the BLE library that's in the arduino core for esp32 devices. This library allows for both client and server functionality. A bluetooth server is established on the console which a bluetooth client can connect to. This client would be in this case the controller. The controller then sends data through a characteristic allowing for data transmission.

This method seemed to work well at first but quickly issues arose when trying to use it together with a Wifi connecting. The console's screen refused to turn on when both bluetooth and wifi were running at the same time. A workaround should exist allowing for the antenna used to be shared between wifi and bluetooth but further research is required to get this functioning. The code used for this implementation can be found in `embedded/ESP32-Controller/Deprecated` for the client code and `embedded/ESP32-Display-Board/Deprecated` for the server code.

#### 4.3.2 UDP
The client code for this can be found in `embedded/ESP32-Controller/include/udp_connection.h` and `embedded/ESP32-Controller/src/udp_connection.cpp`. The server code can be found in `embedded/ESP32-Display-Board/include/connections.h` and `embedded/ESP32-Display-Board/src/connections.cpp`. The UDP method can be implemented through the use of the arduino core `Wifi.h` header and the `WiFiUdp.h` header. The console established a SoftAP which is an accesspoint with a static ip allowing for the controller to be able to connect to it without having to change any settings. The connection is able to be succesfully established the console will listen for UDP packets using. This listener listens in a fixed rate continuously. 

The controller upon connecting to the SoftAP will start sending packets containing the controller data to the console. This works decently well with some delay. A big problem that does arrise is that when sending a message such as a button click this message can get lost in the high traffic of the joystick and gyroscope data which needs to be sent at a high frequency.

#### 4.3.3 ESP-NOW
Setting up ESP-NOW is possible through the use of the `esp_now.h` header. A ESP-NOW connection is setup by storing the MAC address of the device on the sender's side of the project. This allowst the sender to find the server and send it data. 

Through testing the ESP-NOW connection is a lot more stable than the UDP connection from earlier.

## 5. Conclusion
This research explored communication methods for a motion-controlled game using ESP32 devices. Various wireless communication options, including BLE, Wi-Fi (UDP/TCP), and ESP-NOW, were considered. While BLE and Wi-Fi are common in existing motion controllers, ESP-NOW emerged as the most promising for this project due to its low latency, efficiency, and minimal overhead.

Despite challenges like range and lack of message acknowledgment, ESP-NOW offers the best balance for the game’s requirements. Future work will focus on optimizing its use and managing interference to improve communication reliability.

## 6. Reccomendations
Future research could focus on optimizing the ESP-NOW architecture even further. Several improvements can still be researched. Subjects like auto pairing and message acknowledgement.

## 7. References
1. Simon Whistler. *How the Gun on the Original Duck Hunt Worked*. Channel: Today I Found Out, Year. [Link](https://www.youtube.com/watch?v=cu83tZIAzlA&t=72s&ab_channel=TodayIFoundOut).
2. TheChiptide. *How did the Wii Remote Actually Work?*. Channel: TheChipTide. [Link](https://www.youtube.com/watch?v=WZUibjOXMqI&ab_channel=TheChiptide).
3. Wikipedia contributors. *Duck Hunt*. Wikipedia, [Link](https://en.wikipedia.org/wiki/Duck_Hunt).
4. Wikipedia contributors. *Wii controller*. Wikipedia, [Link](https://en.wikipedia.org/wiki/Wii_Remote).
5. Cloudflare. *What is UDP?* [Link](https://www.cloudflare.com/learning/ddos/glossary/user-datagram-protocol-udp/)
6. Cloudflare. *What is TCP/IP?* [Link](https://www.cloudflare.com/learning/ddos/glossary/tcp-ip/)
7. NovelBits. *Master BLE Basics in Just 10 Minutes: The Ultimate Guide!* [Link](https://www.youtube.com/watch?v=JSQhRyTKnW4&ab_channel=NovelBits)
8. Espressif. *ESP-NOW* [Link](https://www.espressif.com/en/solutions/low-power-solutions/esp-now#:~:text=ESP%2DNOW%20is%20a%20wireless,ESP32%2DC%20series%20of%20SoCs.)
9. Arduino. *Device to Device Communication with ESP-NOW* [Link](https://docs.arduino.cc/tutorials/nano-esp32/esp-now/)
10. Espressif. *arduino-esp32*. GitHub [Link](https://github.com/espressif/arduino-esp32/tree/master/libraries/BLE)

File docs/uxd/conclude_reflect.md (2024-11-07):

# Conclude & Reflect

## 1. Product Evaluation Report

### 1.1 **Usability Assessment**

- **Product Usability**: The product is functional for the intended use, meeting most of the selected requirements defined in [Product Requirements](../concept_design#12-product-requirements). The controller and console work as expected, with reliable data transmission between the controller and the console. The interface is intuitive, allowing players to quickly engage with the game, with minimal setup needed. These results were gathered through the use of [User Tests](../create_test#1-user-testing)
- **Aesthetic and Durability Assessment**: The product appears well-designed and durable, showing potential for extended use without significant wear. The controller has a comfortable design with sufficient feedback from buttons and joystick, and the console offers clear visuals. Design considerations were made for user experience, with attention to aesthetics and robustness. The materials used for the housing are solid, though further testing on impact resistance is recommended.

### 1.2 **Visual Documentation**

**Controller**:

<div align="center">
    game-controller-1
    game-controller-2
</div>

<div align="center">
    game-controller-3
    game-controller-4
</div>

**Controller Breadboard Variant**:
<div align="center">
    breadboard-controller-conclude-1
    breadboard-controller-conclude-2
</div>

**Console**:

<div align="center">
    game-console-1
    game-console-2
</div>

**Gameplay**:

<div align="center">
    <video src="/../assets/videos/gameplay.mp4" controls alt="game-console-1">
</div>

### 1.3 **Requirements Reflection and Recommendations**
The following requirements were thought of at the start of the designing process:

1. Users must be able to set up the game console with clear, step-by-step instructions.
2. The controller design must be non-violent and visually appealing to a broad demographic.
3. The wireless controller should be easy to hold for both children and adults.
4. The controller must maintain a stable connection to the display.

All requirements were met some of these were tested through the use of [User Tests](../create_test#1-user-testing). WHile the connectivity requirement was researched through the [research to market](/../research_to_market) and experimentation. 

The only requirement which was met but also not met is "The wireless controller should be easy to hold for both children and adults.". The reason this requirement is hard to gauge is because the Wii like Controller was designed to be for this purpose but the final breadboard controller that is used at this moment was not designed with this in mind.

### 1.4 **Failure Documentation**
There were a ton of failures that were not documented but here are some that could be documented with visuals:

**Motion Controller Housing**:

**Objective**: Initial design used walls that were 1mm thick, which proved too fragile. Increasing the thickness to 2mm provided better durability.

**Issue**: The thin walls of the housing were not durable enough, leading to it feeling quite fragile.

**Solution Attempt**: The housing was redesigned with 2mm-thick walls for added strength. The layout of the internal components was adjusted to distribute stress more evenly.

**Future Approach**: If future 3D print design considerations will be done before hand on the outside wall.

**Visuals**: 
<div align="center">
    basic-shape          
</div>

**Trigger mechanism**:

**Objective**: Initial print of the trigger had the T-Shape joint printed using 0.2 mm layer height.

**Issue**: This print had a T-Shape where the cylinder meant to hold onto the holder was not round causing it to be hard to work with.

**Solution Attempt**: The layer height was changed to 0.1 mm allowing for a more detailed circle.

**Future Approach**: For future prints the layer height will be in consideration before printing to prevent such mistakes.

**Visuals**: 
<div align="center">
    basic-shape          
</div>

**Battery Lid Clip**:

**Objective**: The objective was to print a batterylid which would be able to push into the controller and have a small clip bend to fit the lid into place. 

**Issue**: The clip used was too weak and would break if the lid was attempted to be put into the controller, also the railings on the lid which would fit into 2 slots on the controller did not fit.

**Solution Attempt**: The slots on the controller were enlarged a lot since they were only used for placement and not as a push fit. And the battery clip was made thicker and was made to curve less allowing it to be more resistent to snapping when bending.

**Future Approach**: For future prints research should be done to see if there is a better 3D print filament to use for a situation where the material needs to bend slightly as PLA was kind of hard to work with. The battery lid now does work but you cannot open it easily with your finger nail like you would a tv controller. By using a flathead screwdriver it is easy removed but this kind of defeats the purpose.

**Visuals**: 
<div align="center">
    batterylid          
</div>

**Controller Assembly**:

**Objective**: The final design of the controller was done. It was now time to solder all components together and fit them in the controller.

**Issue**: Due to the lack of flexibiliy in the available wires this became quite a problem. Although carefull considerations was done to allow for enough room for components and still have room for wires. The room left for the wires was not nearly enough. 

**Solution Attempt**: Attempts were made to print the controller bigger but it quickly seemed like this wouldn't be so easy as some components were height dependent  and some components like the button didn't have enough room even with a higher lid. The final solution was to remake the whole controller and make a new one. This is where the Breadboard controller comes in. 

**Future Approach**: Although the breadboard controller fullfills the requirements of being a controller for the game. It is not the design that was preferable both based on size and looks. If more time presents itself a PCB would make a great addition as there is plenty of room to add this in the controller. This would also simplify some mechanics such as the button mechanism. A button could soldered to the bottom of the pcb instead of having to make a mechanism to hover the bottom above the trigger.

**Visuals**: 
<div align="center">
    basic-shape          
</div>

## 2. Conclusion
The development of the game console and controller has mostly met the set goals, providing an easy-to-use, reliable system. User tests confirmed the product works well with minimal setup. However, the breadboard controller, while functional, is not optimal in terms of ergonomics and cosmetic design. Future work in getting the original Wii like design working with the use of a PCB is preferred over using the breadboard controller.

Some challenges, such as issues with the housing, trigger mechanism, and battery lid clip, were addressed through design changes. These lessons will help improve future versions.

Overall, the work on this project was very informative and usefull.

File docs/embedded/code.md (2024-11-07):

# Embedded code

## Contents
- **[1. Project Structure](#1-project-structure)**
    - **[1.1 Code conventions](#11-code-conventions)**
    - **[1.2 Platform.io](#12-platformio)**
    - **[1.3 Used Libraries](#13-used-libraries)**
- **[2. Features](#2-features)**
    - **[2.1 Game State Machine](#21-game-statemachine)**
    - **[2.2 Communication](#22-communication)**
    - **[2.3 Gyroscope](#22-gyroscope)**
    - **[2.4 Joystick](#24-joystick)**
    - **[2.5 Button](#25-button)**
    - **[2.6 Vibration Motor](#26-vibration-motor)**
    - **[2.7 Sprite Rendering](#27-sprite-rendering)**
    - **[2.8 RGB LED](#28-rgb-led)**

## 1. Project Structure
### 1.1 Code conventions
The project is written in C++ and to format this code the use of the standard Arduino/C++ conventions were used. These conventions were used to ensure the readability and maintainability of the code. Another benefit is that most libraries follow this format so the code can be consistent.

These conventions consist of most importantly but not exclusively:

- Classes are written in `Camelcase`.
- The use of **guards** in header files is **mandatory** to prevent multiple inclusions.
- Functions and variable names are written using `camelCase`.
- Filenames should be `lowercase` and can include `dashes` or `underscores`.
- Variables declared as a const, and whose value is fixed for the duration of the program, are named with a leading "k" followed by mixed case `kUpdateSpeed` *(not mandatory)*.
- Constants defined using `#define` are written in `SCREAMING_SNAKE_CASE`.

### 1.2 Platform.io
The development environment for this project will be PlatformIO, a platform for embedded systems development. Integrated into Visual Studio Code, it simplifies building, uploading, and monitoring/debugging microcontrollers. PlatformIO supports various board types, including for example the ESP32-S3 and standard ESP32, and provides package management for libraries. The most important benefit of using Platform.io is that I found it easier to work in Object oriented program which arduino doesn't support by default.

### 1.3 Used libraries
|**Library** | **Description** | **Version** |**Environment**|**Creator** | **Link** |
|---|---|---|---|---|---|
|**Arduino** |The Core framework for Arduino projects. |arduino-esp32|All |Arduino |[GitHub](https://github.com/espressif/arduino-esp32) |
|**ArduinoJSON**|Library allowing for easy JSON parsing and creation. |7.2.0 |All |blanchon |[GitHub](https://github.com/bblanchon/ArduinoJson) |
|**WiFiManager**|WiFi Configuration manager with a configuration portal.|2.0.17 |Display |tzapu |[GitHub](https://github.com/tzapu/WiFiManager) |
|**XPT2046** |*Optional* library to use touchscreen functionalities. |0.0.0 |Display |paulstoffregen |[GitHub](https://github.com/PaulStoffregen/XPT2046_Touchscreen)|
|**MPU6050** |MPU-6050 6-axis accelerometer/gyroscope Library. |1.3.1 |Controller |Electronic Cats|[GitHub](https://github.com/ElectronicCats/mpu6050)  |
|**I2Cdev** |I2C device library used in MPU6050 lib |0.0.0 |Controller |jrowberg |[GitHub](https://github.com/jrowberg/i2cdevlib) |

## 2. Features
Features means the diverse capabilities of the system some topics will go over the implementation on both the console and controller while other topics are device specific. This is specified at the start of each topic.

### 2.1. Game statemachine
***--Display logic--***

[game_controller.cpp](https://gitlab.fdmci.hva.nl/IoT/2024-2025-semester-1/individual-project/nuufoowaamee68/-/blob/main/embedded/ESP32-Display-Board/src/game_controller.cpp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)
[game_controller.h](https://gitlab.fdmci.hva.nl/IoT/2024-2025-semester-1/individual-project/nuufoowaamee68/-/blob/main/embedded/ESP32-Display-Board/include/game_controller.h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)

The game that will be run on the game console. Makes use of the following state diagram as a reference for the code structure:
<div align="center">
  game-statemachine.drawio
</div>
As seen in the diagram the game can only go the next state and no differing routes are possible according to this design.

The state is saved by creating an instance of the enum GameState as seen below it starts in the Intro state.
```cpp
enum GameState
{
    Intro,
    Playing,
    EndGame,
    ShowingHighScores,
};
GameState state = Intro;
```

### 2.2 Communication

Controller: [connections.cpp](https://gitlab.fdmci.hva.nl/IoT/2024-2025-semester-1/individual-project/nuufoowaamee68/-/blob/main/embedded/ESP32-Controller/src/connections.cpp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)
Controller: [connections.h](https://gitlab.fdmci.hva.nl/IoT/2024-2025-semester-1/individual-project/nuufoowaamee68/-/blob/main/embedded/ESP32-Controller/include/connections.h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)

Console: [connections.cpp](https://gitlab.fdmci.hva.nl/IoT/2024-2025-semester-1/individual-project/nuufoowaamee68/-/blob/main/embedded/ESP32-Display-Board/src/Connections.cpp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)
Console: [connections.h](https://gitlab.fdmci.hva.nl/IoT/2024-2025-semester-1/individual-project/nuufoowaamee68/-/blob/main/embedded/ESP32-Display-Board/include/Connections.h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)

The `Connections` class provides an interface for initializing and managing the connection for both the controller and console.
The communication between the controller console and the api is handled through WiFi. The connection from the console to the API is handled through a WiFi connection and the connection between the console and the controller is handled through the use of an Access Point and a ESP-NOW connection.

#### 2.2.1 API Connection through WiFiManager
***--Display logic--***

Using the library WiFiManager setting up a connection to a Access Point is relatively simple. 
By calling:
```cpp 
wm.autoConnect(kWifiManagerPortalName, kWifiManagerPortalPassword);
```
The system will first try to connect to any wifi connections already saved in memory. If no connection was found a portal will open. To connect to this portal you will have to connect to the hotspot created named based on `kWifiManagerPortalName`. To connect to this portal you will also need to insert `kWifiManagerPortalPassword`. In this portal you can then select the WiFi accespoint the device should connect to.

Api calls can be made by using the `makeApiCall()` function of the `connections` class.

Various methods are available to perform api calls:

- `fetchPlayers()`: Sends a GET request to retrieve a list of players from the API. This method returns player JSON data that can be used to verify player existence or retrieve player statistics.
- `getSessionById()`: Sends a GET request with a specific session ID to retrieve the session details. The response includes session information, such as the session ID, associated player ID, and any other relevant session data. This method is crucial for polling until a session is associated with a player.
- `getHighscores()`: Sends a GET request to fetch the JSON list of high scores. This method retrieves the top 10 scores across all sessions and players as a JsonDocument.
- `createScore()`: Sends a POST request to submit a new score to the API. This method takes the player’s score and session id as parameters to make this call.
- `createSession()`: Sends a POST request to start a new session for the game. The API responds with a session ID which is returned by the function.
- `endSession()`: Sends a PATCH request to mark a session as ended. This method updates the session status, ensuring no further game actions can be recorded for that session.

#### 2.2.2 ESP-NOW
***--Display and Controller logic--***

***Server Side (Console)***:

The **server side** (console) handles communication with other ESP32 devices over **ESP-NOW**. It initializes the ESP-NOW protocol, registers a peer device, and processes incoming data.

*Initialization*:

- **Wi-Fi Mode**: Set the controller to **Station mode (WIFI_AP_STA)** to send data over ESP-NOW but also be able to connect to a wifi access point.
- **Channel Setting**: Use `esp_wifi_set_channel` to set the Wi-Fi channel to ensure communication between devices on the same channel.
- **ESP-NOW Initialization**: Call `esp_now_init()` to initialize the ESP-NOW communication protocol.
- **Callback Registration**: Register a callback function (`OnDataRecv`) using `esp_now_register_recv_cb` to handle incoming data from peers.
- **Peer Registration**: Use `esp_now_add_peer()` to register the peer (motion controller) by providing the MAC address. Encryption is disabled for simplicity.

*Receiving Data*:

- The callback function `OnDataRecv` is triggered when the server receives data from the peer.
- Incoming data is parsed as JSON. Based on the method in the JSON payload (e.g., `CONTROLLER_AXIS_DATA_METHOD`, `TRIGGER_METHOD`), the server updates its state (e.g., setting gyro data, trigger state, etc.).

***Client Side (Motion Controller)***:

The **client side** (motion controller) communicates with the console using **ESP-NOW** to send data, such as gyroscope, joystick and button data.

*Initialization*:

- **Wi-Fi Mode**: Set the controller to **Station mode (WIFI_STA)**.
- **Channel Setting**: Configure the communication channel using `esp_wifi_set_channel` to match the server’s channel.
- **ESP-NOW Initialization**: Call `esp_now_init()` to initialize the ESP-NOW protocol.
- **Callback Registration**: Register a callback (`OnDataSent`) to handle the status of sent messages.
- **Peer Registration**: Provide the MAC address of the console and add the peer with `esp_now_add_peer()`.

*Sending Data*:

- The `sendData()` method is responsible for sending JSON data to the console.
- Serialize the data into a string and send it using `esp_now_send()` to the console’s MAC address.
- The controller sends different types of data (e.g., gyroscope, joystick values, trigger presses) as JSON payloads. Each method or input type is identified in the JSON payload (e.g., `CONTROLLER_AXIS_DATA_METHOD`, `TRIGGER_METHOD`).

*Example of received data*:
```json
{
    "method": "axisData",
    "data": {
        "gX": 0.0,
        "gY": 0.0,
        "jX": 0.0,
        "gX": 0.0
    }
}
```

### 2.3 Gyroscope
***--Controller logic--***

[gyroscope.cpp](https://gitlab.fdmci.hva.nl/IoT/2024-2025-semester-1/individual-project/nuufoowaamee68/-/blob/main/embedded/ESP32-Controller/src/Gyroscope.cpp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)
[gyroscope.h](https://gitlab.fdmci.hva.nl/IoT/2024-2025-semester-1/individual-project/nuufoowaamee68/-/blob/main/embedded/ESP32-Controller/include/Gyroscope.h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)

The `Gyroscope` class provides an interface for initializing and managing the MPU6050 sensor, which includes a gyroscope and accelerometer. It handles the collection and processing of gyroscope data, including orientation in Euler angles and other sensor readings. 

- **Initialization**: The class sets up the I2C communication with the MPU6050 sensor, checks the connection, and initializes the DMP (Digital Motion Processor).
- **Data Collection**: The class collects sensor data from the MPU6050, including quaternion values, Euler angles, real and world-frame acceleration, and linear acceleration.
- **Data Processing**: It processes raw sensor data to compute screen coordinates based on gyroscope movement.
- **Interrupt Handling**: The class uses an interrupt-based system to trigger data collection when new sensor data is available.

### 2.4 Joystick
***--Controller logic--***

[joystick.cpp](https://gitlab.fdmci.hva.nl/IoT/2024-2025-semester-1/individual-project/nuufoowaamee68/-/blob/main/embedded/ESP32-Controller/src/Joystick.cpp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)
[joystick.h](https://gitlab.fdmci.hva.nl/IoT/2024-2025-semester-1/individual-project/nuufoowaamee68/-/blob/main/embedded/ESP32-Controller/include/Joystick.h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)

The `Joystick` class provides an interface for handling joystick input, including initialization, reading joystick axis values, and detecting button presses. It also includes methods to normalize joystick axis values to a specific range and filter out minor joystick movements (dead zone).

- **Initialization**: Sets up the joystick pins for reading input.
- **Button Detection**: Detects whether the joystick button has been pressed.
- **Axis Reading**: Reads the joystick axis values (X and Y) and normalizes them to a specific range.
- **Dead Zone Handling**: Filters out small joystick movements by applying a dead zone to the normalized axis values.

### 2.5 Button
***--Controller logic--***

[game_controller.cpp](https://gitlab.fdmci.hva.nl/IoT/2024-2025-semester-1/individual-project/nuufoowaamee68/-/blob/main/embedded/ESP32-Display-Board/src/game_controller.cpp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)
[game_controller.h](https://gitlab.fdmci.hva.nl/IoT/2024-2025-semester-1/individual-project/nuufoowaamee68/-/blob/main/embedded/ESP32-Display-Board/include/game_controller.h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)

The button handling logic in the `MotionController` class is responsible for detecting button presses, managing debounce and cooldown times, and triggering vibration feedback when the button is pressed. The button press also sends data to the console via the `sendTriggerInput()` method.

- **Button Press Detection**: Detects when the button is pressed, with debounce to prevent multiple triggers from a single press.
- **Cooldown Mechanism**: Prevents multiple button presses from being registered in quick succession by enforcing a cooldown period.
- **Vibration Feedback**: Activates the vibration motor when the button is pressed, and stops it after a predefined duration.

### 2.6 Vibration motor
***--Controller logic--***

[game_controller.cpp](https://gitlab.fdmci.hva.nl/IoT/2024-2025-semester-1/individual-project/nuufoowaamee68/-/blob/main/embedded/ESP32-Display-Board/src/game_controller.cpp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)
[game_controller.h](https://gitlab.fdmci.hva.nl/IoT/2024-2025-semester-1/individual-project/nuufoowaamee68/-/blob/main/embedded/ESP32-Display-Board/include/game_controller.h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)

The vibration motor logic in the `MotionController` class is responsible for providing feedback to the user when certain actions occur, such as pressing a button. The motor is controlled by activating it at full intensity (PWM) when a button is pressed and deactivating it after a set duration.

- **Vibration Activation**: The vibration motor is activated when a button is pressed, providing feedback to the user.
- **Vibration Duration**: The vibration motor remains active for a specified period, after which it is deactivated automatically.
- **Cooldown Handling**: The vibration motor logic ensures that the motor is not triggered multiple times too quickly, and it is controlled independently of the button press handling logic.

### 2.7 Sprite Rendering
***--Display logic--***

[sprite_renderer.cpp](https://gitlab.fdmci.hva.nl/IoT/2024-2025-semester-1/individual-project/nuufoowaamee68/-/blob/main/embedded/ESP32-Display-Board/src/sprite_renderer.cpp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)
[sprite_renderer.h](https://gitlab.fdmci.hva.nl/IoT/2024-2025-semester-1/individual-project/nuufoowaamee68/-/blob/main/embedded/ESP32-Display-Board/include/sprite_renderer.h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)

The Sprite Rendering logic in the `SpriteRenderer` class is responsible for rendering sprites on the display using the `TFT_eSPI` library. It manages the initialization of the display, rendering of sprites for the cursor, background, owl (enemy) sprites, and UI elements such as score, bullets, and owls killed. The class includes logic for sprite movement, collision detection, user input handling (via joystick or gyro), and game flow management, including different difficulty settings and game state transitions.

- **Display Initialization**: The display is initialized using the `TFT_eSPI` library, and the screen is configured for optimal use with support for rotation and byte swapping.
- **Cursor Movement and Input**: The cursor is controlled via gyro or joystick input, and its position is dynamically updated on the display. It can be used to aim and interact with the game environment.
- **Sprite Animation and Logic**: The owl sprite is animated and moves across the screen, with collision detection to check for hits. If the owl moves offscreen or is missed, it resets to a starting position.
- **Intro and Highscore Screens**: The class renders an introductory screen displaying the session ID and game instructions, and it can also display high scores by fetching data from an external JSON source.
- **End Screen and Replay Option**: At the end of the game, an end screen is displayed with options to play again or end the session, with user interaction based on cursor input.

*Gameplay*:

- **Game Loop Handling**: The class implements a flexible game loop that adapts to the current game state, ensuring smooth sprite rendering and handling owl movement, player input, and collision detection. The loop is initialized based on session settings such as difficulty levels, affecting gameplay mechanics such as speed, score per kill, and the number of bullets available for the player.
- **UI Updates**: The class updates the display to show the player's score, remaining bullets, and other game statistics, keeping the player informed about their progress.
- **Collision Detection**: Detects collisions between the cursor and the owl sprite using bounding box checks to award points for successful hits.

### 2.7.1 Sprite Generation
In this project the use of Sprites is required. To do this sprites were made using Aseprite to make sprites with a small size `ex: 32x32`. After exporting these as pngs they were converted to byte arrays for use in code. 

An [online converter](http://www.rinkydinkelectronics.com/t_imageconverter565.php) was used for this.

### 2.8 RGB LED
***--Display logic--***

[game_controller.cpp](https://gitlab.fdmci.hva.nl/IoT/2024-2025-semester-1/individual-project/nuufoowaamee68/-/blob/main/embedded/ESP32-Display-Board/src/game_controller.cpp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)
[game_controller.h](https://gitlab.fdmci.hva.nl/IoT/2024-2025-semester-1/individual-project/nuufoowaamee68/-/blob/main/embedded/ESP32-Display-Board/include/game_controller.h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)

The RGB LED control logic in the `GameController` class is responsible for managing the RGB LED to provide visual feedback to the user based on the game state. The LED color changes to indicate different game phases such as wifi initialization, polling and gameplay.

- **LED Initialization**: The LED is initialized with a specific pins for the Red, Green and Blue channels, allowing it to control the LED.
- **Dynamic Color Changes**: The LED color is updated dynamically to provide feedback, such as:
    - **Red** during startup.
    - **Blue** during wifi initialization.
    - **Yellow** when the game is waiting for a player to connect.
    - **Green** when the player has successfully connected and the game is in progress.
- **Brightness Control**: The LED brightness can be adjusted by modifying the intensity of the color channels.

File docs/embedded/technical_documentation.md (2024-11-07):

# Technical documentation

## Contents
- **[1. Basic Concept](#1-basic-concept)**
    - **[1.1 Outputs](#11-outputs)**
    - **[1.2 Inputs](#12-inputs)**
    - **[1.3 Extra Components](#13-extra-components)**
    - **[1.4 Component List](#14-component-list)**
- **[2. Bill of Materials](#2-bill-of-materials)**
- **[3. Project Wiring Diagram](#3-project-wiring-diagram)**
- **[4. Components](#4-components)**
    - **[4.1 MPU6050](#41-mpu6050)**
    - **[4.2 ESP32-2432S024 (Display & Led)](#42-esp32-2432s024)**
        - **[4.2.1 ESP32-2432S024 (ESP Display)](#421-esp32-2432s024-esp-display)**
        - **[4.2.2 RGB LED](#422-rgb-led)**
    - **[4.3 Joystick](#43-joystick)**
    - **[4.4 Button](#44-button)**
    - **[4.5 Vibration Motor](#45-vibration-motor)**
    - **[4.6 DC-DC Multi-Output Buck-converter](#46-dc-dc-multi-output-buck-converter-33v5v9v12v)**

## 1. Basic Concept
This project will be an Embedded system take on the game Duck Hunt. This project has as requirement 3 outputs and 3 inputs. The goal is to make a wireless controller capable of moving a digital cursor on a screen.

### 1.1 Outputs
- A ESP32 powered Display
- RGB Led which will display the status through color.
- A Rumble pack in the controller for extra satisfying game feedback.

### 1.2 Inputs
- Gyroscope that will serve as the means of calculating where the cursor on screen should be pointing
- Fire button (This will be a button on the controller which will trigger the fire function of the game).
- Joystick to function as a secondary input for controlling the cursor on screen.

### 1.3 Component list
Below all components are specified for both the console and the controller. The components marked extra are only added if enough time is presented as they are not as important.

- Console
    - External power source (Extra)
        - Power switch (Extra)
    - Display
        - Onboard RGB Led
    - Speaker / Buzzer (Extra)

- Controller
    - External power source / 9v Battery
        - Power Switch (Extra)
        - DC - DC Converter
    - Gyroscope
    - Joystick
    - Trigger button
    - Vibration Motor

## 2. Bill of materials

A Bill of Materials (BOM) is a all encompassing list of parts, materials, and components required to build or assemble a product. It serves as a blueprint/shopping list for all the necessary materials and allows potential builders of this project to ensure all components are available before starting the project.

Below is the table that outlines the necessary parts for this project:

|**Part**|**Manufacturer**|**Description**|**Quantity**|**Price (incl VAT)**|**Subtotal (incl VAT)**|**URL**|
|-|-|-|-|-|-|-|
|MPU6050|Invensense|6 Axis gyroscope & Accelerometer|1|€8,50|€8,50| [Tinytronics](https://www.tinytronics.nl/nl/sensoren/acceleratie-rotatie/mpu-6050-accelerometer-en-gyroscope-3-axis-module-3.3v-5v)|
|ESP32-2432S024 Display |Guition |ESP32 Lvgl/Tft Lcd Display Development Board 240*320 2.4Inch|1|€17,99|€17,99| [Aliexpress](https://nl.aliexpress.com/item/1005005865107357.html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)|
|ESP32-S3|Top Tech Store|ESP32-S3 Development Kit Module|1|€6,39|€6,39| [Aliexpress](https://nl.aliexpress.com/item/1005007310769585.html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)|
|Vibration Motor|DIY Victor|Pwm Vibration Motor, Dc Motor|1|€1,28|€1,28|[Aliexpress](https://nl.aliexpress.com/item/1005006296840332.html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)|
|DC-DC Converter 9v-5v |DFRobot|DFRobot DC-DC Multi-uitgang Buck-converter (3.3V/5V/9V/12V)|1|€5,99|€5,99|[Robotshop](https://eu.robotshop.com/nl/products/dfrobot-dc-dc-multi-uitgang-buck-converter-33v-5v-9v-12v)|
|Joystick Module|DIY TZT|Dual-Axis X/Y Joystick Module|1|€3,65|€3,65|[Aliexpress](https://nl.aliexpress.com/item/1005005985509291.html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)|
|9V Battery|Varta|Long life max power 9V battery Alkaline|1|€3,79|€3,79|[Amazon](https://www.amazon.nl/Varta-4722-Batterijenideaal-brandmelder-stemapparaat/dp/B004WYN62O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)|

## 3 Project wiring diagram
The wiring diagram was created using Fusion360 Electronics. The components were created using a mix of custom made symbols in Fusion360 and some edited versions taken from [SnapEDA](https://www.snapeda.com). All fusion electronics files can be found in docs/assets/diagrams/FusionElectronics/...

A wiring diagram is a visual representation of an electrical circuit, showing the connections between different components. It uses standardized symbols to represent elements like power sources, switches, resistors, and wires. This diagram is useful for understanding how electricity flows through the circuit.

ControllerWiringDiagram

***As the console has no wiring involved no wiring diagram is needed. The console only needs to be connected to power using a USB-C cable.***

## 4. Components
### 4.1 MPU6050 

<div style="display: flex; align-items: center;">
  <div style="flex: 1;">
    <div>
      The MPU is a 6 axis gyroscope and accelerometer. It retrieves data from rotating and moving the component.
      This data can be quite fluctuating and not very precise. The MPU has a built in way of dealing with this called the DMP "Digital Motion Processor".
      This processor runs so called fusion algorithms internally allowing the ESP to receive clean and reliable "fused" motion information. More about this can be read in <a href="https://techexplorations.com/guides/arduino/peripherals/mpu6050/">this article</a>
    </div>
    <br>
    <div>
      The angles of the MPU can be defined using YAW PITCH and ROLL. A visual respresentation of this can be seen in the image shown.
    </div>
  </div>
  <div style="flex: 1; text-align: right;">
    MPU6050
    MPU6050
  </div>
</div>

### 4.2 ESP32-2432S024
#### 4.2.1 ESP32-2432S024 (ESP Display)
<div style="display: flex; align-items: center;">
  <div style="flex: 1;">
    The ESP32-2432S024 or how it will be called for ease of reading the ESP Display is a 2.4 inch display with a resolution of 320x240. This display allows for full color display and touchscreen support. This display has an ESP32 onboard which allows the user to not have to wire anything to communicate from the esp to the display. This board also exposes some extra GPIO pins.

    To use the display a library is required called TFT_eSPI a important fact for using this library is that the library needs to configured before use. This is done by changing the User_Setup.h to use the correct pins and settings. This was all found in the user manual. Provided from the store page which can be found in the [BOM](#2-bill-of-materials)
  </div>
  <div style="flex: 1; text-align: right;">
    rawmpudata
  </div>
</div>

#### 4.2.2 RGB LED
<div style="display: flex; align-items: center;">
  <div style="flex: 1;">
  	The ESP32-2432S024 besides a display also has a RGB led allowing a broad range of colored light to be displayed. This allows the system to display a certain condition through a color indication.

    This Led is used to show certain conditions of the system.
  </div>
  <div style="flex: 1; text-align: right;">
    rawmpudata
  </div>
</div>

### 4.3 Joystick
<div style="display: flex; align-items: center;">
  <div style="flex: 1;">
    The joystick consists of 2 potentiometers one for the x axis and one for the y axis. This allows for 2d coordinate to be determined which in turn can be used for the cursor on screen. The joystick serves as an alternative to using gyro data. The joystick also has a click function so it also serves as a button.
  </div>
  <div style="flex: 1; text-align: right;">
    rawmpudata
  </div>
</div>

### 4.4 Button
<div style="display: flex; align-items: center;">
  <div style="flex: 1;">
    A simple button is also used to be used as the "fire" button and as a general action button. This button simply gives a signal to a connected GPIO pin.
  </div>
  <div style="flex: 1; text-align: right;">
    rawmpudata
  </div>
</div>

### 4.5 Vibration Motor
<div style="display: flex; align-items: center;">
  <div style="flex: 1;">
    The vibration motor serves as a way to provide a feedback to the player when pressing the trigger button. This motor is controlled through the use of a PWM signal. This allows differing levels of vibration to be achieved. The motor must be placed in a way where it is against a wall of the controller to allow for more vibrations to pass through.
  </div>
  <div style="flex: 1; text-align: right;">
    rawmpudata
  </div>
</div>

### 4.6 DC-DC Multi-Output Buck-converter (3.3V/5V/9V/12V)
<div style="display: flex; align-items: center;">
  <div style="flex: 1;">
    This DC-DC stepdown converter serves as the power management for the controller. This component allows the controller to be powered through the use of a 9v battery. The 9 volts is brought down to 5 volts which is able to power an ESP32-S3.
  </div>
  <div style="flex: 1; text-align: right;">
    rawmpudata
  </div>
</div>

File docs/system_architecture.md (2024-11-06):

# System Architecture

## Introduction
A system architecture is essential for building effective, scalable, and maintainable systems. It serves as a blueprint that explains the structure of the components, and interactions within a system stimulating a smooth development. A clear architecture concept enables teams to manage complexity and reduces the risk of critical flaws. By establishing a clear architecture early on in the development process, future problems can be caught early and any adjustments to the infrastructure will be easier to maintain.

## System Architecture Diagram

<div align="center">
  TCPvUDP
</div>

The above diagram shows the communications between a website, api and 2 embedded devices which together create a system abling a person to start a game through a frontend and play this game on an embedded device.

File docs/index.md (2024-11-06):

{{ mdocotion_header('https://images.unsplash.com/photo-1550745165-9bc0b252726f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') }}
# Game console
<div align="center">
  gameconsole
</div>
The project is based on the IoT Minor blueprint Gameconsole
<br>
<br>

# Hoot Pursuit
<div style="display: flex; align-items: center;">
  <div style="flex: 1;">
    <p>The system developed involves the following main components:</p>
    <ul>
      <li>ESP32 - Game Controller</li>
      <li>ESP32 Display - Game Console</li>
      <li>API</li>
      <li>Database</li>
      <li>Website</li>
    </ul>
    <p>
      Together, these components make the game <strong>Hoot Pursuit</strong> a reality! This game is inspired by the classic retro game Duck Hunt but uses joystick and gyroscope controls instead of the LDR mechanism found in Duck Hunt.
    </p>
  </div>
  <div style="flex: 1; text-align: right;">
    project
  </div>
</div>

For more details of the system first see the [System Architecture](system_architecture)

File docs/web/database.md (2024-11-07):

# Database

## Contents
- **[1. Database Overview](#1-database-overview)**
   - **[1.1 Entity-Relationship Diagram (ERD)](#11-entity-relationship-diagram-erd)**
   - **[1.2 EER Diagram](#12-eer-diagram)**
- **[2. Database Setup](#2-database-setup)**
   - **[2.1 MySQL Workbench](#21-mysql-workbench)**
- **[3. Database Design](#3-database-design)**
   - **[3.1 Tables](#31-tables)**
     - **[3.1.1 Player Table](#311-player-table)**
     - **[3.1.2 Score Table](#312-score-table)**
     - **[3.1.3 Session Table](#313-session-table)**
     - **[3.1.4 Difficulty Table](#314-difficulty-table)**
   - **[3.2 Relationships](#32-relationships)**

## 1. Database overview
### 1.1 Entity-Relationship Diagram Diagram (ERD)
Below the ERD is shown. This concept allows the system to be able to store player data through sessions. A session is the time a single player is playing with the game console. A session can contain more than one score. A player can also have more than one session if the same username is used to start a new session this session will be linked to the same player id.

<div align="center">
  ERD
</div>

The player starts the embedded device then is prompted with a session id. The player then goes to the website and fills in their name and session id. This creates the player if the name didnt already exist and binds the session to this player. The device is polling until a player is added to the current session. Only then can the game start

### 1.2 EER Diagram
To realise the previous established ERD this EER diagram was generated from the made tables this shows the different types of data that will be stored and the relation between the tables.
<div align="center">
  EER
</div>

## 2. Database setup
### 2.1 MYSQLWorkbench
To interface with the SQL Database MYSQLWorkbench was used. To connect to the database through this program you need to fill in the sql login details.
<div align="center">
  sqlworkbench
</div>

### 2.2 Initializing database
- Copy the sql script from [databaseInit.sql.](https://gitlab.fdmci.hva.nl/IoT/2024-2025-semester-1/individual-project/nuufoowaamee68/-/blob/main/web/database/databaseInit.sql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)
- Make a new query to an empty database (this can be done through MYSQLWorkbench).
- Paste the script and edit "databasename" to your database name.
- Run the script.

## 3.1 Database Design
### 3.1 Tables
#### 3.1.1 Player table
The player table consists of 2 columns:

- *ID*: the identifier
- name: the players name (Unique)

player-table

#### 3.1.2 Score table
The score table consists of 3 columns:

- *ID*: the identifier.
- session_id: the id of the session the score occured in.
- score: used to store the score count.

score-table

#### 3.1.3 Session table
The session table consists of 6 columns:

- *ID*: the identifier.
- completed: if the session has ended.
- start_time: the start time of the session.
- end_time: the end time of the session.
- player_id: the id of the player which started the session.
- difficulty_id: indicates the selected difficulty of the session.

session-table

#### 3.1.4 Difficulty table
The difficulty table consists of 2 columns:

- *ID*: the identifier.
- name: the name of the difficulty.

difficulty-table

### 3.2 Relationships
Between the mentioned tables some relationships are of note:

- A difficulty can be used in multiple sessions.
- A session can only have one difficulty.
- Player can have multiple sessions.
- A session can only have one player.
- A session can have multiple scores.
- A score can only have one session.

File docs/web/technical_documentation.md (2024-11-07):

# Technical Documentation

## 1. Introduction
The goal of the webapplication for the Hoot Shooter project was to create a retro 'feel' website. The website had as purpose to be the the controller for the game console. The website will have a button allowing to start the game, also through the use of the web portal various game settings will be able to be changed and selected. During gameplay the website will show various usefull information such as the current game session settings and the scores acquired during the session. Besides the website for the user a simple website that shows varous tables filled with data retrieved from the API will also be present. This will allow a direct monitor for the database containing the session and game data. 

To allow for all the communications required with the database an API will also have to be developed to allow for the connectivity through a safe intermediate preventing security risks.

## 2. Technologies Used

### 2.1 Code editor
---
<div style="display: flex; align-items: center;">
  <div style="flex: 1;">
    Visual studio code was my code editor for the development of the web application. I chose VScode as it's a lightweight multi purpose code editor allowing for an easy workflow between front and backend development. VScode also has a enormous library of extensions which allowed for coding language specific syntax highlighting and intellisense. All of this greatly improves the workflow efficiency and effectiveness.
  </div>
  <div style="flex: 1; text-align: right;">
    vscode
  </div>
</div>

### 2.2 Frontend
---
The frontend is built with HTML, CSS, and JavaScript to keep the application lightweight and easy to maintain. This approach was chosen for simplicity and to avoid the overhead of complex frameworks, as the requirements for interactivity and styling are straightforward.
<br>
<div style="display: flex; align-items: center; gap: 10px; ">
    html
    css
    javascript
</div>
<br>

#### 2.2.1 Bootstrap
For the styling Bootstrap was used. Bootstrap is a styling component library allowing for quick good looking html elements without much need to write CSS. This allows for a quick work flow promoting producitivity a great deal. 

### 2.3 Backend
---
#### 2.3.1 PHP
<div style="display: flex; align-items: center;">
  <div style="flex: 1;">
    The backend is developed using PHP, a widely-used scripting language suited for server-side logic. PHP was chosen due to its compatibility with a variety of servers and ease of integration with relational databases, as well as its efficient handling of RESTful API requests.
  </div>
  <div style="flex: 1; text-align: right;">
    php
  </div>
</div>

### 2.4 Database
#### 2.4.1 MariaDB
<div style="display: flex; align-items: center;">
  <div style="flex: 1;">
    The database is a **mariadb** based SQL database. MariaDB is an open-source relational database management system (RDBMS) that is a fork of MySQL. The database can be viewed, monitored and maintained through the use of MySQLWorkbech. More about this can be found on the [Database](/web/database#21-mysqlworkbench) page.
  </div>
  <div style="flex: 1; text-align: right;">
    mariadb
  </div>
</div>

### 2.5 Deployment
---
#### 2.5.1 Docker
<div style="display: flex; align-items: center;">
  <div style="flex: 1;">
    The application is containerized using Docker, ensuring that the environment remains consistent across development, testing, and production. This simplifies dependency management and makes the deployment process more robust and repeatable.
  </div>
  <div style="flex: 1; text-align: right;">
    docker
  </div>
</div>
<br>

#### 2.5.2 Nginx
<div style="display: flex; align-items: center;">
  <div style="flex: 1;">
    Nginx, a high-performance web server and reverse proxy. Nginx is efficienct in handling HTTP requests, its lightweight footprint, and its strong support for concurrent connections allows it to efficiently handle the web server.
  </div>
  <div style="flex: 1; text-align: right;">
    nginx
  </div>
</div>

#### 2.5.3 Testing
To make sure the deployment process was properly tested for use on multiple devices. I've deployed the project on multiple desktops to ensure the project is able to setup without any glaring issues. Tests were also done to ensure the efficiency and effectiveness of the web application. These can be seen in the [Create & Test](../uxd/create_test.md) page.

## 3. Design Decisions

### 3.1 Frontend Structure
#### 3.1.1 Index Page
The frontend is structured with an index page that displays a form for users to initiate the game. Upon submission, the form triggers the game start process, allowing users to interact directly with the game environment.
indexpage

#### 3.1.2 Admin Page
An admin page is included to provide a view of the backend data in a structured format. This page displays tables populated with data retrieved from the API endpoints, allowing developers or system maintainers to manage or review game data effectively. This keeps player interactions and administrative separate, ensuring a more concise user experience and improved maintainability.
adminpage

### 3.2 Backend Structure
#### 3.2.1 API Routing
The backend directs requests to `/api/`, with `api.php` serving as the main entry point. Incoming requests are routed to specific controllers based on URL parameters. For instance, requests to `/api/player/` are routed to the player controller, which handles player-related operations. This allows for an easy to understanding routing pattern for the endpoints.

#### 3.2.1 Controller and Gateway Structure
Each controller has a corresponding gateway class that contains the direct CRUD (Create, Read, Update, Delete) functions with SQL statements. These gateway classes isolate database interactions, allowing controllers to focus on handling the logic and responses. This separation of roles improves code  readability, and maintainability.

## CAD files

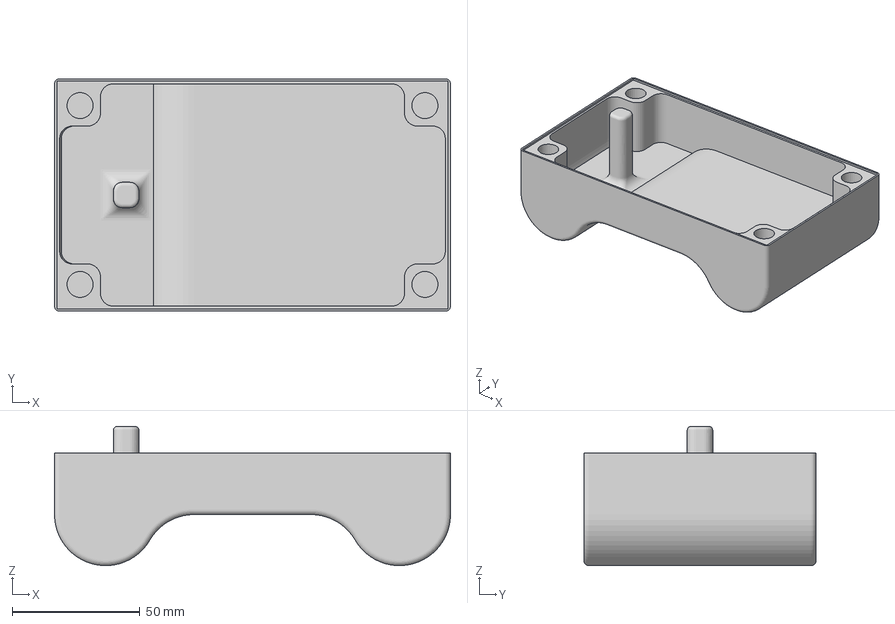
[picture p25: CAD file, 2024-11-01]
docs/assets/3d-files/Breadboard-Controller-Bottom-v5.3mf
155.0 x 91.0 x 54.5 mm

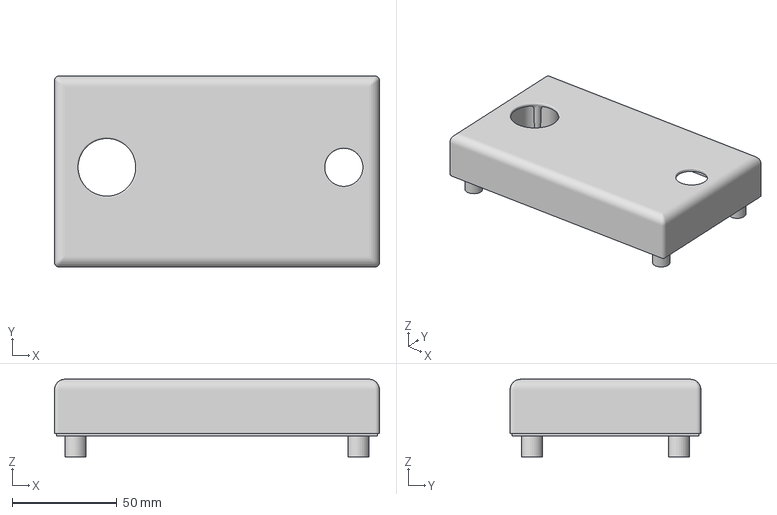
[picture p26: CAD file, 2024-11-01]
docs/assets/3d-files/Breadboard-Controller-Top-v5.3mf
155.0 x 91.0 x 37.0 mm

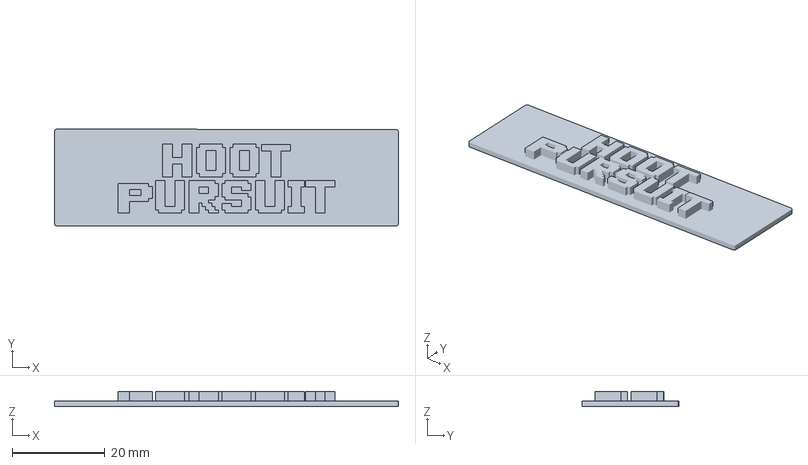
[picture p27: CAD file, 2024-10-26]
docs/assets/3d-files/Console-Banner-v14.3mf
74.2 x 20.9 x 3.15 mm

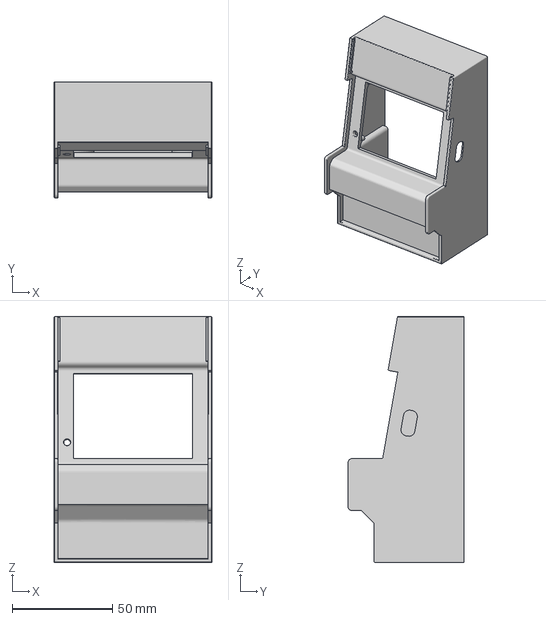
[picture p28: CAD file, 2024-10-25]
docs/assets/3d-files/Console-Front-v8.3mf
78.8 x 58.0 x 123.0 mm

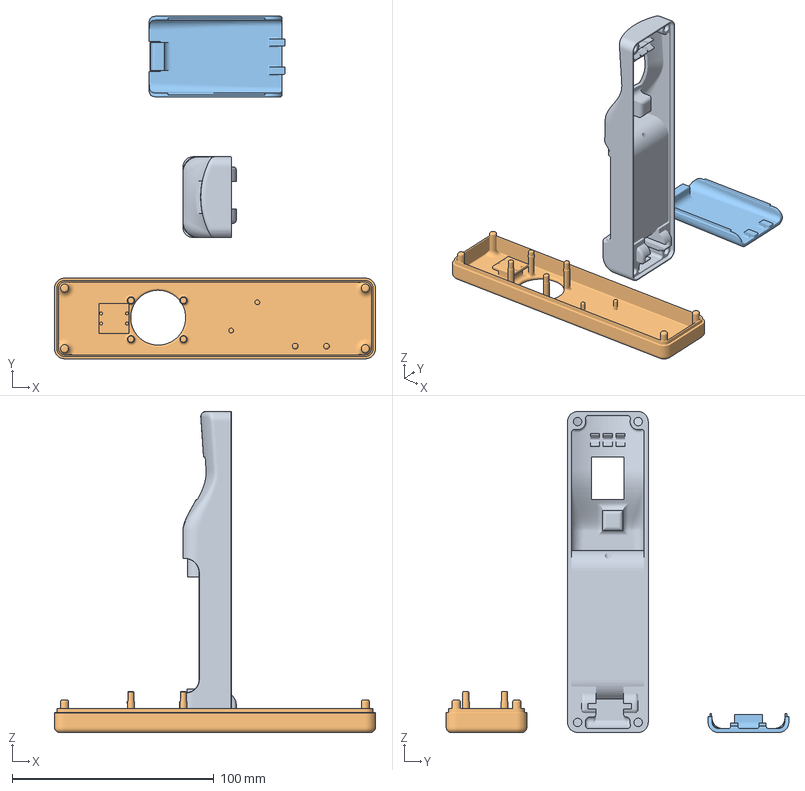
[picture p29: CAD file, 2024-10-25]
docs/assets/3d-files/Bottom-v55.3mf
159.0 x 169.7 x 159.0 mm
Bottom
Top
BatteryLid

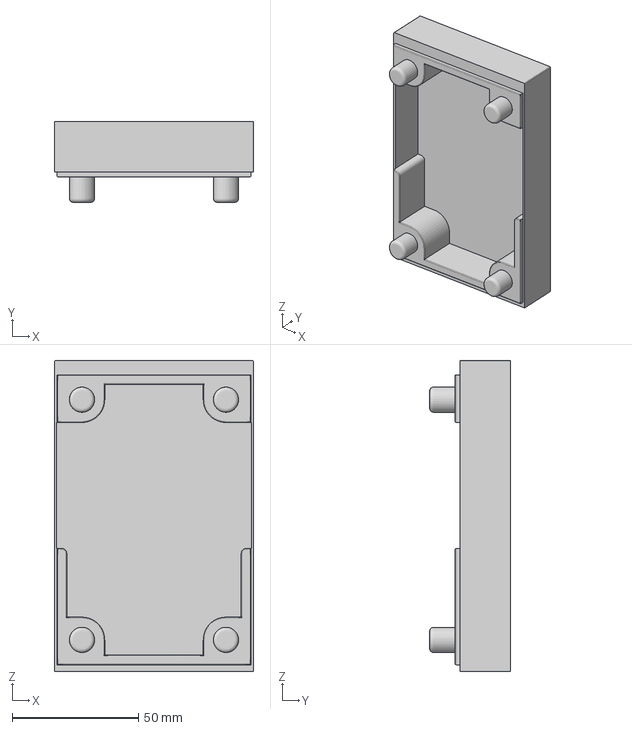
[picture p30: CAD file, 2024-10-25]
docs/assets/3d-files/Console-Back-v8.3mf
78.8 x 31.9 x 123.0 mm

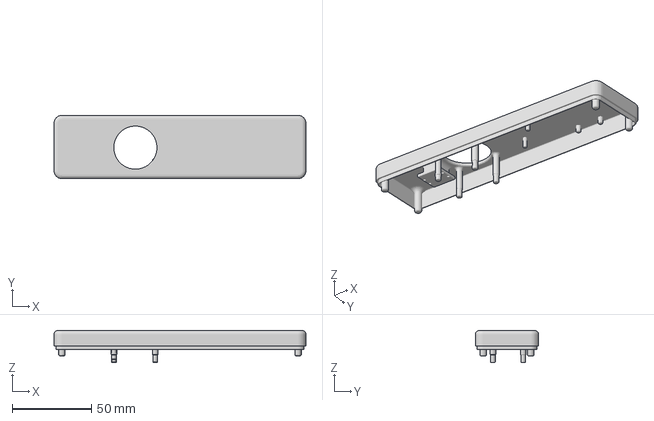
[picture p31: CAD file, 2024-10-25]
docs/assets/3d-files/Top-v55.3mf
159.0 x 40.0 x 20.3 mm

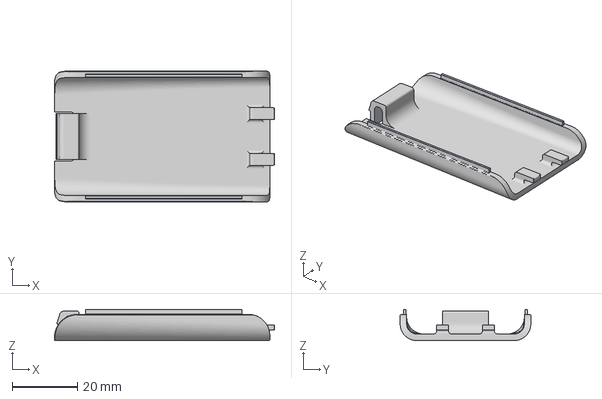
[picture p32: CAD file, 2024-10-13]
docs/assets/3d-files/BatteryLid-v53.3mf
67.3 x 40.0 x 9.50 mm

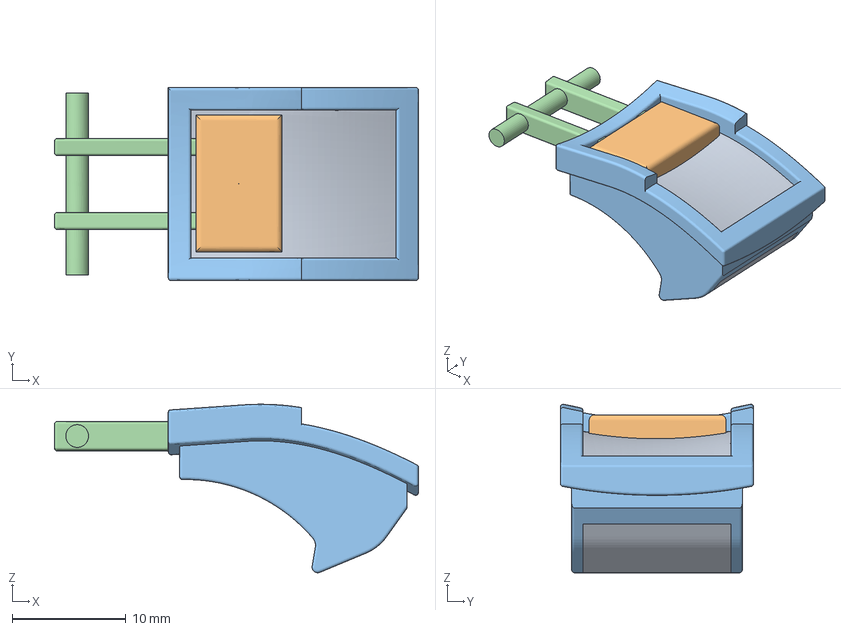
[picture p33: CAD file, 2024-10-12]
docs/assets/3d-files/Trigger-v48.3mf
32.0 x 17.0 x 14.8 mm
Brim
Nub

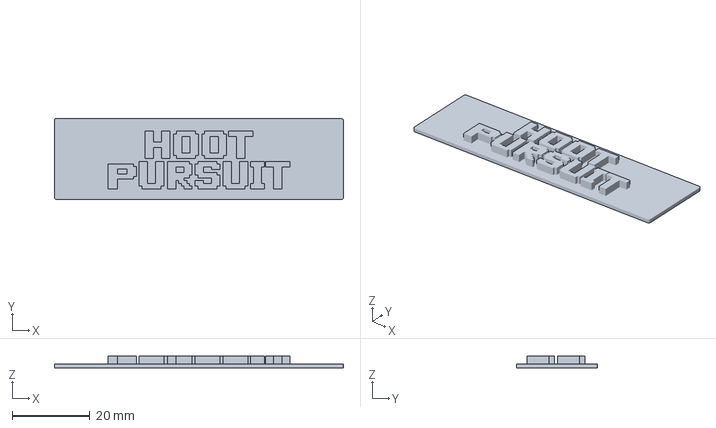
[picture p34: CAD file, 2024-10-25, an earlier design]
docs/assets/3d-files/Console-Banner-v11.3mf
74.2 x 20.9 x 3.00 mm

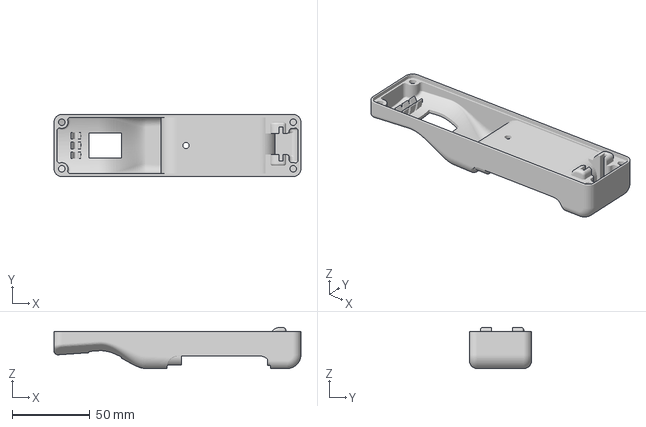
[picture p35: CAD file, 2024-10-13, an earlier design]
docs/assets/3d-files/Bottom-v53.3mf
159.0 x 40.0 x 26.4 mm

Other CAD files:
docs/assets/3d-files/Bambu Studio/BannerProject.gcode.3mf
docs/assets/3d-files/Bambu Studio/ControllerProject.gcode.3mf
docs/assets/3d-files/Bambu Studio/ConsoleProject.gcode.3mf
docs/assets/3d-files/Top-v53.3mf
docs/assets/3d-files/Fusion Design Files/Components/9V.Battery v1.f3d
docs/assets/3d-files/Fusion Design Files/Components/DC-DC Stepdown (Unfinished) v3.f3d
docs/assets/3d-files/Fusion Design Files/Components/DC-DC Stepdown v4.f3d
docs/assets/3d-files/Fusion Design Files/Components/ESP32-2432S024 Display v4.f3d
docs/assets/3d-files/Fusion Design Files/Components/ESP32-2432S024 Display v5.f3d
docs/assets/3d-files/Fusion Design Files/Components/Joystick PCB v3.f3d
docs/assets/3d-files/Fusion Design Files/Components/MPU_6050 v1.f3d
docs/assets/3d-files/Fusion Design Files/Components/Simple-Embedded-Button v4.f3d
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

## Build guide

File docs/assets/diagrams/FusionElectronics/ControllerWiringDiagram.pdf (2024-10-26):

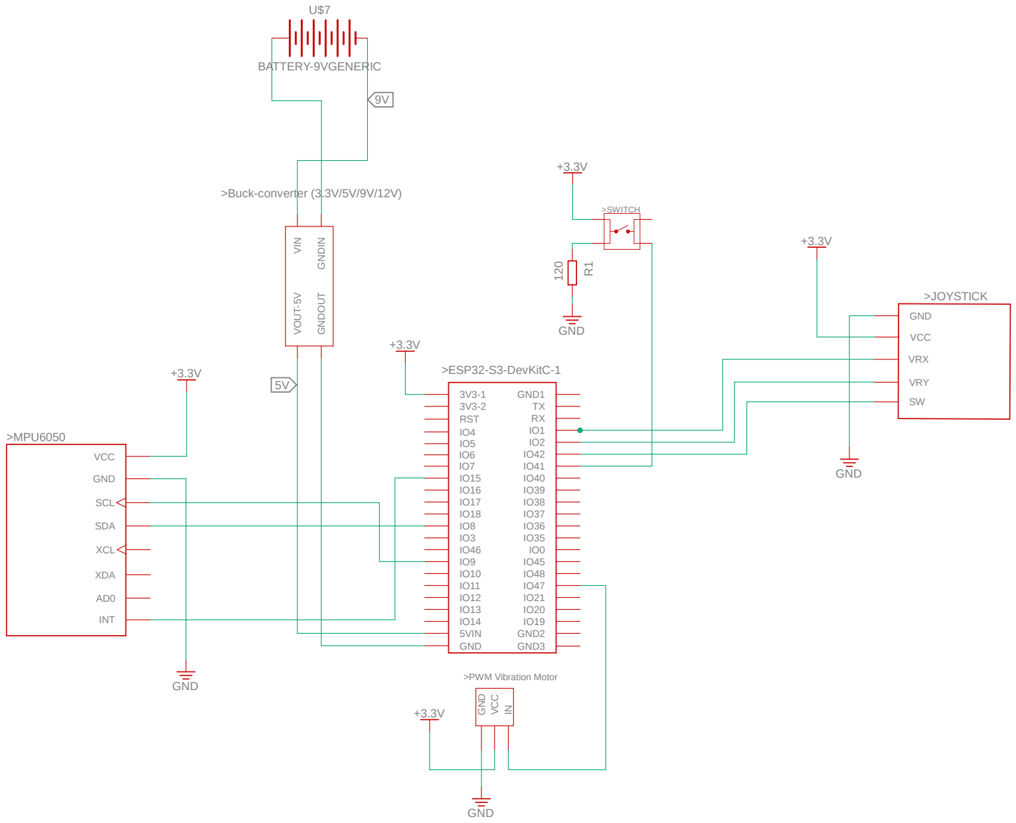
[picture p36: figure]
GND; BATTERY-9VGENERIC; >JOYSTICK GND; VRX; VRY; VCC VIN; GNDIN VOUT⁻5V; GNDOUT; >Buck-converter (3.3V/5V/9V/12V); >ESP32-S3-DevKitC-1; IO19 GND2; GND1; 5VIN; TX GND3; RST IO5 GND; IO6 >MPU6050; XDA; XCL AD0; INT VCC GND; SCL SDA; >SWITCH; >PWM Vibration Motor GND VCC IN

## 26/10/2024 23:08 (Sheet: 1/1)

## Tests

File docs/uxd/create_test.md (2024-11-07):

# Create & Test

- **[1. User Testing](#1-basic-concept)**
    - **[1.1 Effectiveness Test](#11-effectiveness-test)**
    - **[1.2 Efficiency Test](#12-efficiency-test)**
    - **[1.3 Satisfaction Test](#13-satisfaction-test)**
    - **[1.4 Test conclusions](#14-test-conclusions)**
- **[2. Manufacturing](#2-manufacturing)**
    - **[2.1 Print details](#21-print-details-slicer-printer)**
    - **[2.2 Prints](#22-prints)**

## 1. User testing

### 1.1 Effectiveness test
#### 1.1.1 Test case

***Hyptohesis***: My assumption is that the user will not encounter any errors and is able to start the game.

***Metrics***: Missclicks, Clicks, Completion rate.

***Criteria***: The test is considered a failure if the user is unable to figure out how to enter data or if the user thinks it is unclear where session information is located.

***Task 1: Enter Session ID and player name and click play***

- *Goal*: Find where to enter a console ID on the homepage and proceed to the console page.
- *Questions*: 
    - Was it clear where to enter the session ID and name?
    - Did you encounter any errors?

**Task 2: Check session details***

- *Goal*: View the session details on screen.
- *Questions*:
    - Are the details easy to read and understand?
    - Did you instantly know what this page shows?

***Task 3: Check the score table***

- *Goal*: View the session details on screen.
- *Questions*:
    - Is the score table easily found?
    - Is it clear what the score info means?

#### 1.1.2 Test results
**Task 1**:

| Participant | Was it clear where to enter the player name? | Did you encounter any errors? | Clicks | Missclicks |
|---|---|---|---|---|
| Lucas |  Yes | No | 7 | 0 |
| Nick |  Yes very clear | No | 4 | 0 |
| Lars |  Yes | No | 5 | 0 |
| Simon |  Yes | No | 6 | 0 |

**Task 2**:

| Participant | Are the details easy to read and understand? | Did you instantly know what this page shows? |
|---|---|---|
| Lucas | No, text is close together | Yes |
| Nick | Yes except because of the font the session id is hard to read | Yes it was clear right away |
| Lars | Yes maybe make the glow a bit less strong on the table header | Yes |
| Simon | Yes | No, too focused on the game console |
| Giorgio | Yes | Yes |
| Ferdi | Yes | Yes |
| Margot | Yes | Yes |

**Task 3**:

| Participant | Is the score table easily found? | Is it clear what the score info means?  |
|---|---|---|
| Lucas | Yes | Yes |
| Nick | Yes | Yes |
| Lars | Yes | Yes |
| Simon | Yes | Yes |
| Giorgio | Yes | Yes |
| Ferdi | Yes | Yes |
| Margot | Yes | Yes |

### 1.2 Efficiency test
#### 1.2.1 Test case

***Hypothesis***: My assumption is that the game can be started under 3 minutes.

***Metrics***: Time taken, amount of clicks to completion

***Criteria***: The test is considered a failure if the game can not be started within the allocated time or the game encounters a bug causing the game to either not be started within 3 min es or not start at all.

1. *Task 1: Startup the console and view the session id provided*
    - *Goal*: Find where to enter a console ID on the homepage and proceed to the console page.
2. *Task 2: Enter Session ID and player name*
    - *Goal*: Find where to enter a session ID on the homepage.
3. *Task 3: Start playing game*
    - *Goal*: View the console which will now start the game.

#### 1.2.2 Test results

| Participant | Time taken to start game | Clicks to completion |
|---|---|---|
| Lucas | 21 sec | 7 |
| Nick | 25 sec | 4 |
| Lars | 23 sec | 5 |
| Simon | 26 sec | 6 |
| Giorgio | 52 sec | 7 |
| Ferdi | 47 sec | 8 |
| Margot | 65 sec | 8 |

### 1.3 Satisfaction test
#### 1.3.1 Test case
***Hypothesis***: My assumption is that the Wii Controller will be liked but the breadboard controller will not.

***Criteria***: The test is considered a failure if both the controllers are considered not child friendly and not pleasant to look at.

***Questions***:

  - What is your opinion on the controller design (Both breadboard and wii controller)?
  - Do you have any additional feedback for the look of the controller?

#### 1.3.2 Test results

| Participant | Opinion on controller design (Both breadboard and wii controller) | Would you say the controller looks right for all ages | Additional Feedback | Notes |
|---|---|---|---|---|
| Giorgio | It would be nice if it was a little bit flatter but it was pretty comfortable. Wish the wii controller worked do I could  test it out because it feels great in my hand. | It does but it might be a little too big. The wii controller is perfect for all ages. | Less delay. Sounds would be nice. | |
| Ferdi | Sad that the Wii controller doesn’t work, it does look like a lot of fun. Breadboard worked good and was easy to start with. | Wii controller 100%, the breadboard aswell but could be a bit smaller for smaller hands. |  Fix delay, I would have definetly have the highscore if it wasn’t for the delay. | |
| Margot| It looks great! Looks very proffesional|  The controller looks well suited for all ages if we are talking about the wii controller the breadboard controller might be a bit too big for children| | Had trouble distinguishing the game and the website causing some confusions. |

## 1.4 Test conclusions
From all the tests some conclusions can be immediately drawn. The time taken for a game to start was a lot faster than expected. The 20+ range were a lot faster as expected but no person took longer than 70 seconds. This is a good result. Some problems did arise with the breadboard controller the size seems to be a bit too big for children, but since the original plan is still to make the Wii like controller the primary design this is not a big issue. 

The delay in the controller responsiveness was a big factor for most players. Because of this the research to market focussed on looking into better ways of communicating through the controller. The testers all used the UDP method as of the time of their test. After the tests were conclucded a new protocol was introduced called ESP-NOW this had as a result that the delay was eliminated and the delay is now no longer an issue. Because of the result of these tests more attention was given to this so this helped greatly in the end product.

## 2. Manufacturing

### 2.1 Print details (Slicer & Printer)

#### 2.1.1 X1 Carbon Printer
<div style="display: flex; align-items: center;">
  <div style="flex: 1;">
    The printer used in this project is the Bambu Lab's X1 Carbon. This printer together with the optional AMS system allows for multicolor high speed printing. This printer uses the Bambu studio slicer which will be talked about below.
  </div>
  <div style="flex: 1; text-align: right;">
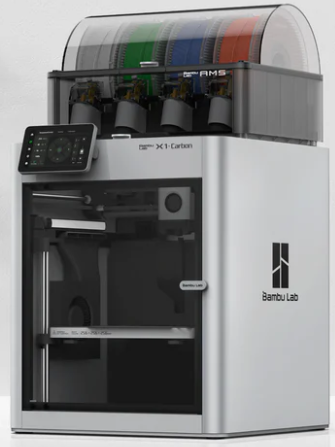
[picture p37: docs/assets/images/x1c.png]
    
  </div>
</div>

#### 2.1.2 Printing Material
<div style="display: flex; align-items: center;">
  <div style="flex: 1;">
    The material used is PLA "Bambu Green" from bambulabs. This material is easy to print with and great for prototyping. 
  </div>
  <div style="flex: 1; text-align: right;">
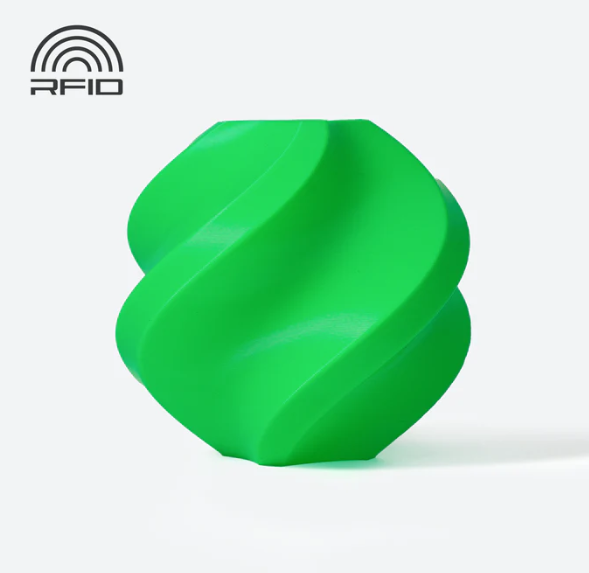
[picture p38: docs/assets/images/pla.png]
    
  </div>
</div>

#### 2.1.3 Slicer layout
The program used to create the gcode required for the printed is Bambu Studio the program looks like this:
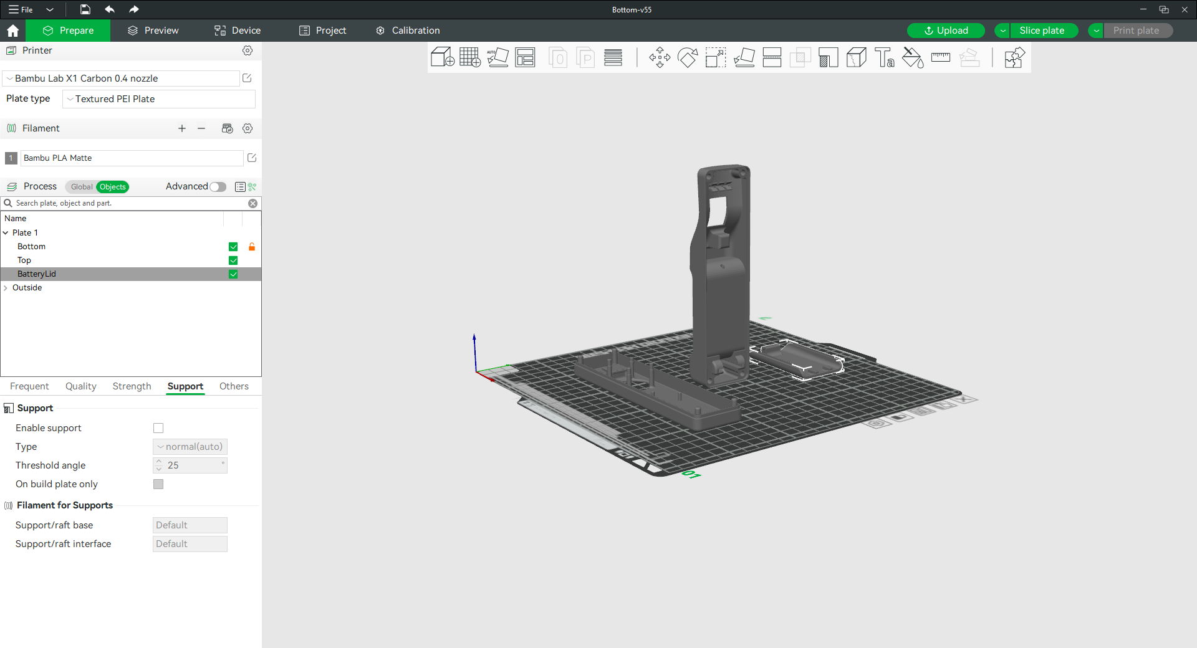
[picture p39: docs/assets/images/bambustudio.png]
bambustudio


#### 2.1.4 Slicer print settings
The bambustudio files can be found in this repo under assets/3d-files/bambustudio/.. These files come with the settings already setup.

The controller was printed using the following settings:

| **Part** | **Support Type** | **Details** |
|---|---|---|
| **Top** | No Support | Default settings for printer. |
| **Batterylid** | Tree Support (Manual) | Support painting function used; only overhanging parts have tree support. |
| **Bottom** | Tree Support (Automatic)  | Threshold angle: 15°. Uses more filament to ensure controller quality. |
| **Trigger** | Tree Support (Automatic)  | Threshold angle: 20°. |
| **Console Front** | No Support | Default settings for printer. |
| **Console Back** | No Support | Default settings for printer. |
| **Console Banner** | No Support | Default settings for printer. (uses multicolor) |
| **Breadboard Controller Top** | No Support | Default settings for printer. |
| **Breadboard Controller Bottom** | Tree support (Automatic)  | Threshold angle: 20°. Print on side and use default settings for |

The banner uses multicolor to do this the color for each body in the stl can be assigned:
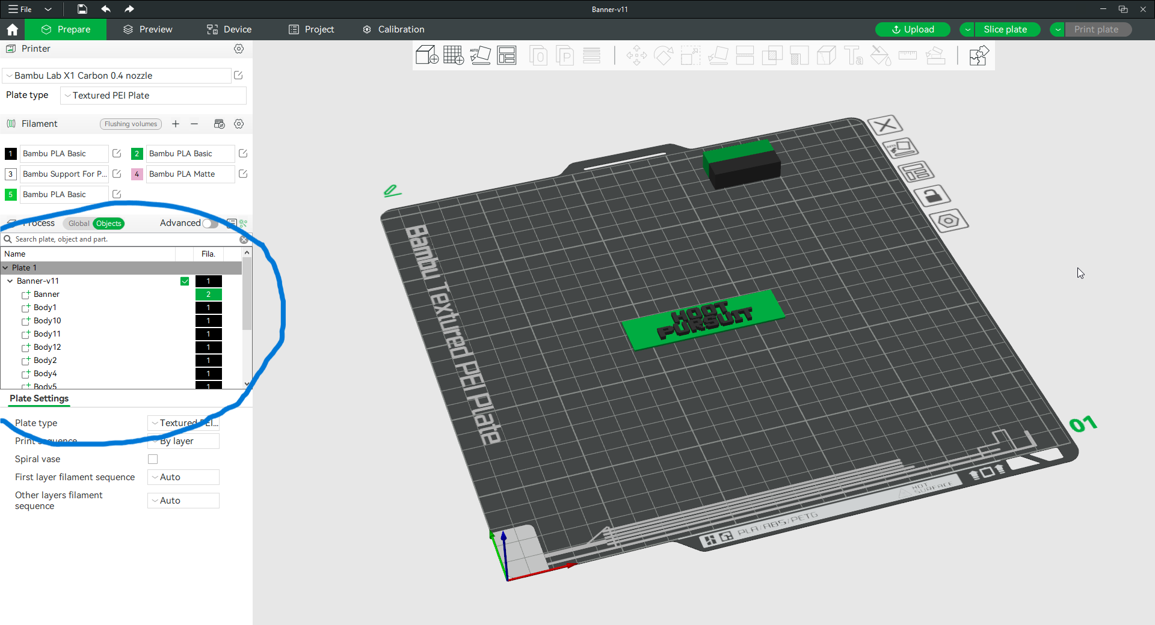
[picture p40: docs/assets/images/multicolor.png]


With support the sliced file looks like this:
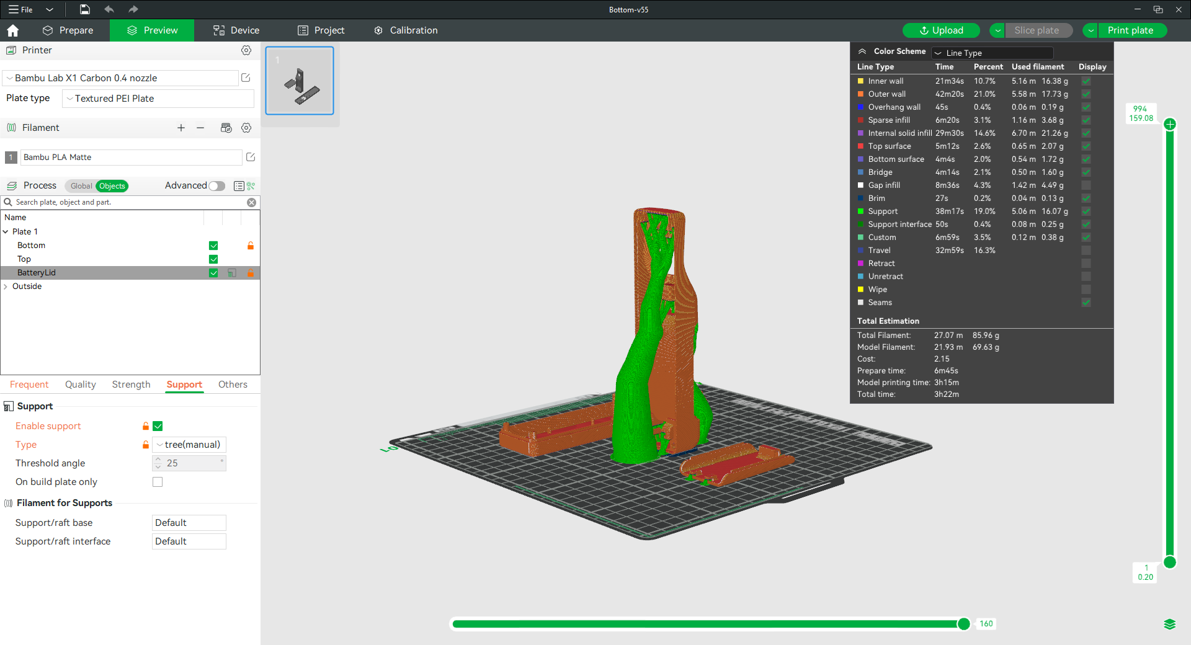
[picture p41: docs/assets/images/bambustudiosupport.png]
bambustudiosupport


### 2.2 Prints

#### 2.2.1 Basic Shape Controller

The first print was mostly to get a feeling of the size of the controller to see if everything would fit the way I expected from inspecting it in the CAD.
<div align="center" style="display: flex; justify-content: space-between;">
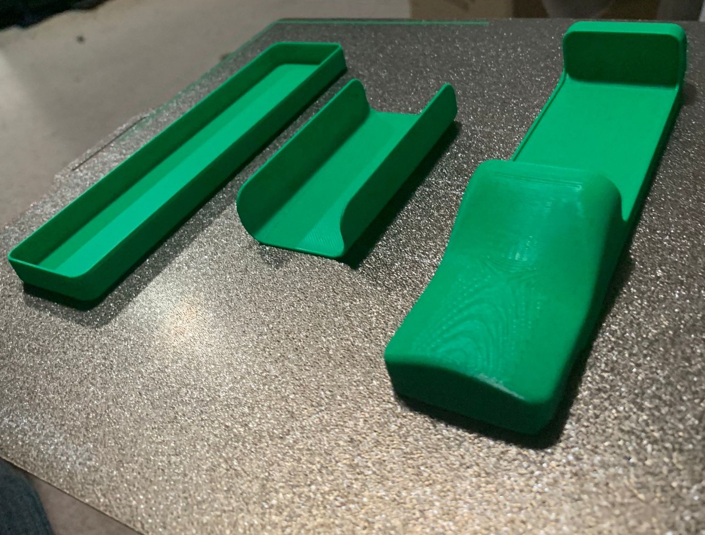
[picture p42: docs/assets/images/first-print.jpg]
first-print
  
  <video src="/../assets/videos/BasicShapePrint.mp4" controls width=49%></video>
</div>
Some adjustments that were quite obvious right away was the thickness of the model. 1mm was quite thin and fragile. Increasing the shell of the model to 2mm makes it a lot more robust. This does take some space away from the components inside the model.

#### 2.2.2 Trigger mechanism

One of the most important mechanics of the controller was the trigger to test this a small print was made. More about the inspiration for this mechanism can be found in [concept & design](concept_design.md#222-trigger-mechanism).
To test this design the trigger was printed with a seperate holder:

<div style="display: flex; justify-content: space-between;">
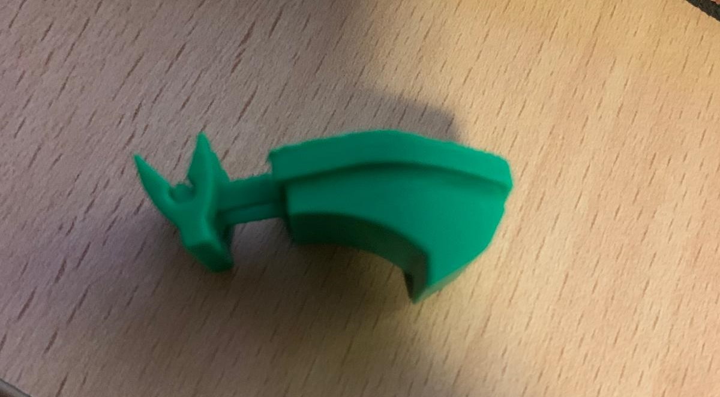
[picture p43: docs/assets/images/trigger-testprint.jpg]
trigger-testprint
  
  <video src="/../assets/videos/TriggerTestPrint.mp4" width=49% controls></video>
</div>

#### 2.2.3 Controller
After some iterations the whole controller was printed. The trigger can be inserted into the holder at the top of the controllers inside. Allowing it to move up and down without detaching from the controller. 
<div align="center" style="display: flex; justify-content: space-between;">
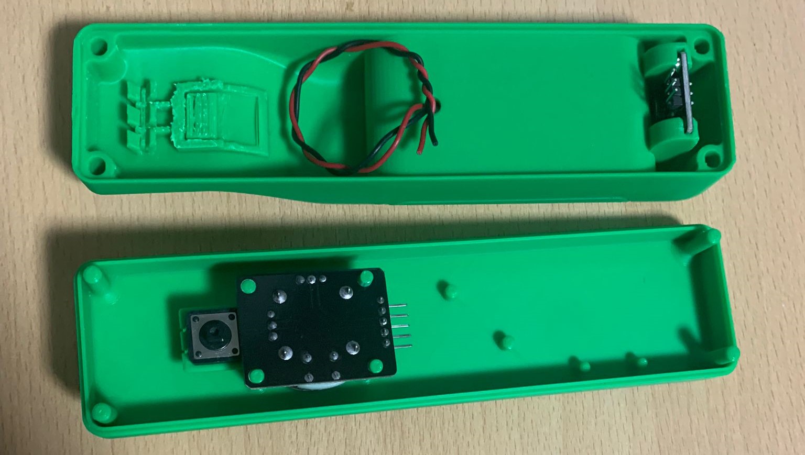
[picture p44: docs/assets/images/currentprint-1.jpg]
currentprint-1
  
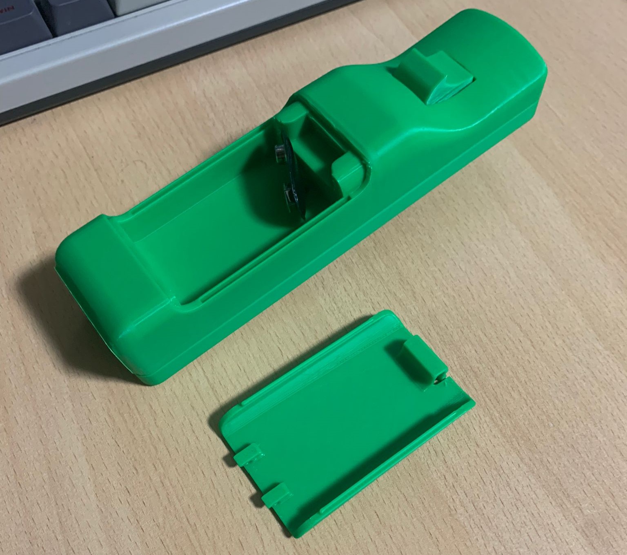
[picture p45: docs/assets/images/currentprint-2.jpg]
currentprint-2
  
</div>

<div align="center" style="display: flex; justify-content: space-between;">
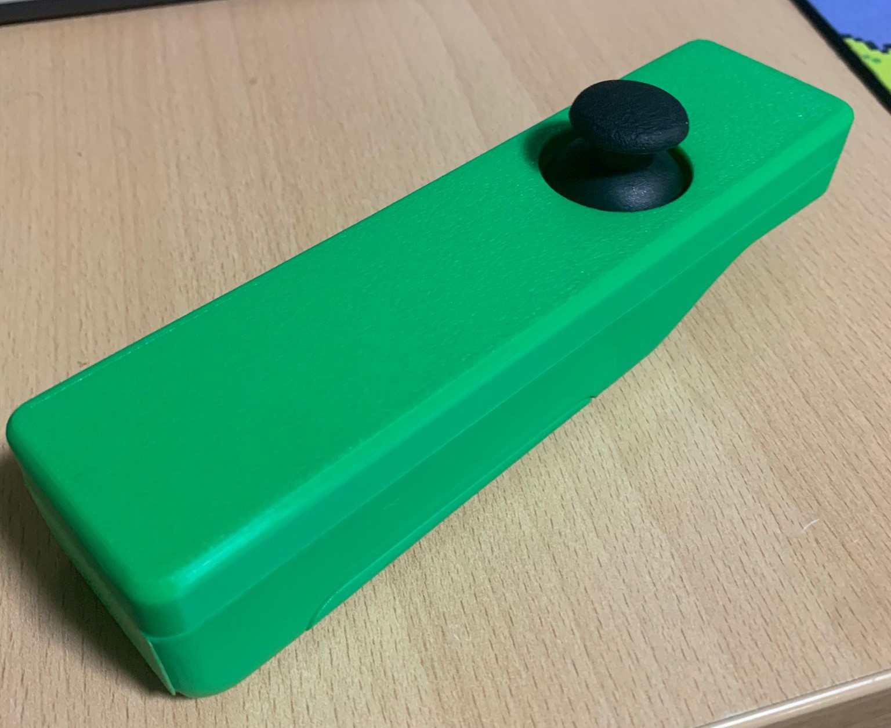
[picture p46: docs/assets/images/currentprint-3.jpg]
currentprint-2
  
  <video src="/../assets/videos/PrintingAll.mp4" width=49% controls></video>
</div>

To assemble the controller follow the placement of components specified in [concept & design](concept_design.md#228-current-controller-design)

#### 2.2.4 Breadboard Controller
After having issues assembling the motion controllr with all the components properly soldered and wired. An easier design was made for the purpose of testing the project.

<div align="center" style="display: flex; justify-content: space-between;">
  currentprint-1
  currentprint-2
</div>

<div align="center" style="display: flex; justify-content: space-between;">
  currentprint-2
  <video src="/../assets/videos/BreadboardControllerPrint.mp4" width=49% controls></video>
</div>

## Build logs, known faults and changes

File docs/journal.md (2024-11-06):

# Learning journal

## Contents
1. **[Week 1](#week-1)**
1. **[Week 2](#week-2)**
1. **[Week 3](#week-3)**
1. **[Week 4](#week-4)**
1. **[Week 5](#week-5)**
1. **[Week 6](#week-6)**
1. **[Week 7](#week-7)**
1. **[Week 8](#week-8)**
1. **[Week 9](#week-9)**
1. **[Week 10](#week-10)**

<br>

## Week 1
<hr>

Monday I was unfortunately not able to attend the lesson. In my own time I spent some time looking through all the online files about the lectures I also asked a few fellow students about the information i missed. 

I started the course setting up all seperate parts of the project and seeing if they would run. I installed all necessary programs and setup the template project. After this I started working on an ERD for a Database design.

<br>

<div align="center">
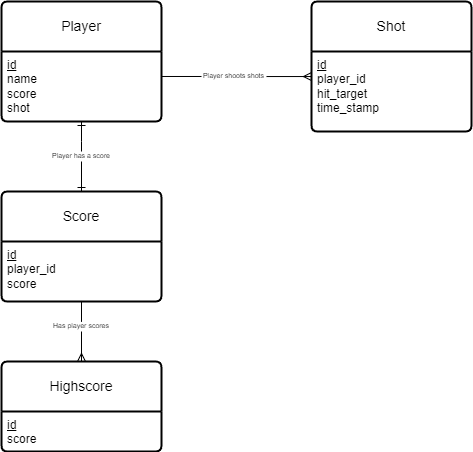
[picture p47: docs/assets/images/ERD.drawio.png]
ERD
  
</div>

<br>

### Feedback
**🌐 Database**

**Reviewer: Nick Schokker**

**Feedback:** looks good but in the highscore field you should add the player because you would like to know who has the highest score.

**Takeaway:** Although I ended up not using this feedback as I instead completely removed the highscore table as it was redundant due to the existence of a score table that could just be sorted.

<br>

### Feedback
**🌐 Database**

**Reviewer: Mats Otten**

**Feedback:** Without context, it's hard to say if your ERD (Entity-Relationship Diagram) is suitable for your application. However, it seems that you might not need a 'Highscore' entity if you already have a 'Score' entity. Additionally, you also have a score in the Player entity? And you also have a Shot which might also contain a Score?

**Takeaway:** Coincidentally I had already applied the above feedback but it was good to have a confirmation of the assumption that the highscore table was not needed.

<br>

### EER Diagram
After making my first draft of ERD I started designing the Database itself to show this I've made an EER Diagram.

<br>

<div align="center">
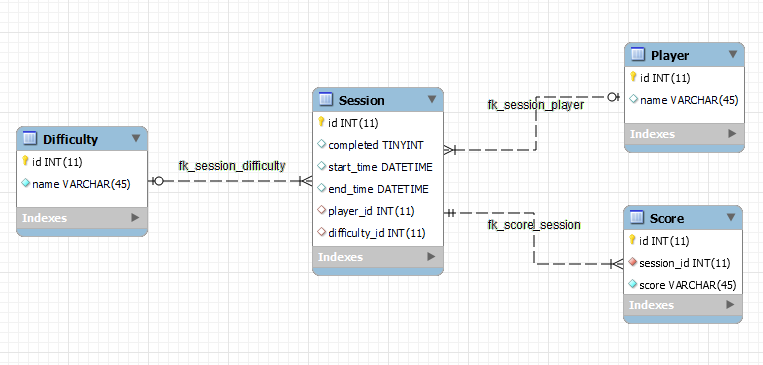
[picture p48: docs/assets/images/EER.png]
EER
  
</div>

<br>

### PHP Learning
I spent some time learning the basics of PHP and setting up some basic scripts. I followed this [tutorial](https://www.youtube.com/watch?v=OK_JCtrrv-c&ab_channel=freeCodeCamp.org). I was able to skip a big portion of it as it went over a lot of programming basics.

<br>

### Setting up platform.io project
For my embedded part I decided to not use the Arduino IDE and instead choose platform.io as this was more familiar for me. This also allows me to easily create multiple files and work in a more OOP fashion. Another benefit is that platform.io is an extension in vscode allowing me to work in vscode for all parts of the project.

<br>

### Environmental variabels
To run the project a file named .env is needed which includes all login details for connecting to the database. This information is something you don't want to upload to the repository that's why I worked on being able to load these in through code and exclude the .env file from being pushed to the repository.

<br>

### Documentation
This week I also worked on some documentation. I wrote documentation for my database and embedded requirements.

<br>

## Week 2
<hr>

### REST API
I worked on creating the first version of my API. I worked on this through a [tutorial](https://www.youtube.com/watch?v=X51KOJKrofU&ab_channel=DaveHollingworth) this tutorial taught me to make a simple rest API capable of performing CRUD operations with a single table. This doesn't allow for full communication with my database as of yet. It's a great start however, as it allows control over atleast the player table which is sufficient for now for testing purposes.

Additionally I added a custom http error code display using the http.cat API
<div align="center">
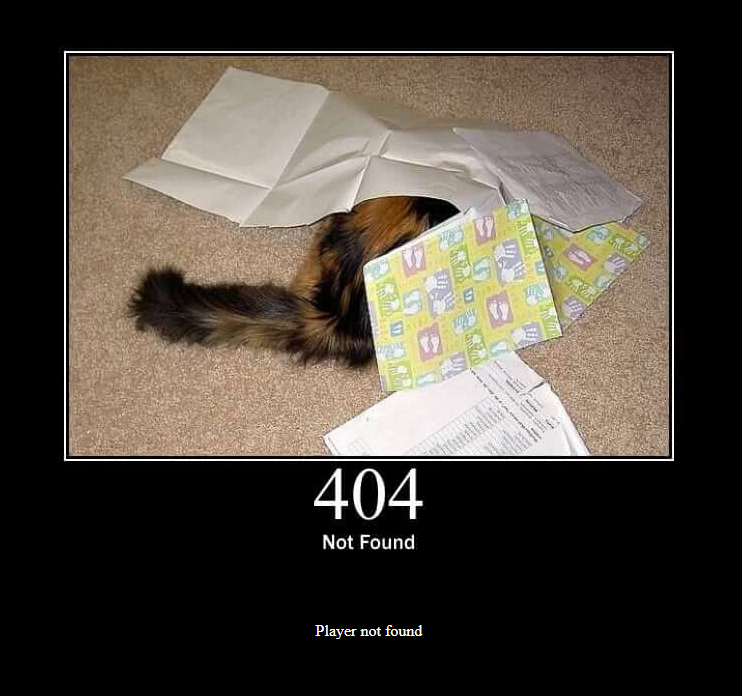
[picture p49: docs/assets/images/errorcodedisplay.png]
errorcodedisplay
  
</div>

<br>

### Frontend 
To visualise the data I worked on my frontend a bit. I added tailwindcss as i've already worked with bootstrap a lot and wanted to learn a bit more about tailwind.
<div align="center">
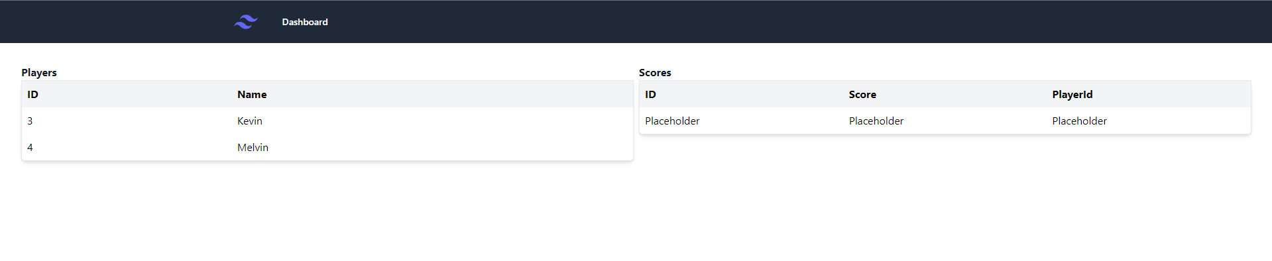
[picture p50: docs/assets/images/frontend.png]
frontendexample
  
</div>

I ended up improving the frontend by adding a scrollable table body allowing the page to not extend endlessly with the size of the tabe. Also cell border dividers were added to improve the readability.

<br>

### Feedback

**🌐 Application Code.**

**Reviewer: Lucas Hilgevoord**

**Feedback:** Please add a summary in your php code above your functions. The rest looks good! Nice to see the comments in your functions it self.

**Takeaway:** I've added comments above all functions in my API to explain more clearly what kind of parameters are expected, a summary about the function and what the function might return.

<br>

### Start of embedded device
After having a basic API up and running the start of the embedded device was next. The goal was to have a simple embedded device with a button that can trigger some API calls to test the connection between the different elements.

Result:

<div align="center">
  frontendexample
</div>

<div align="center">
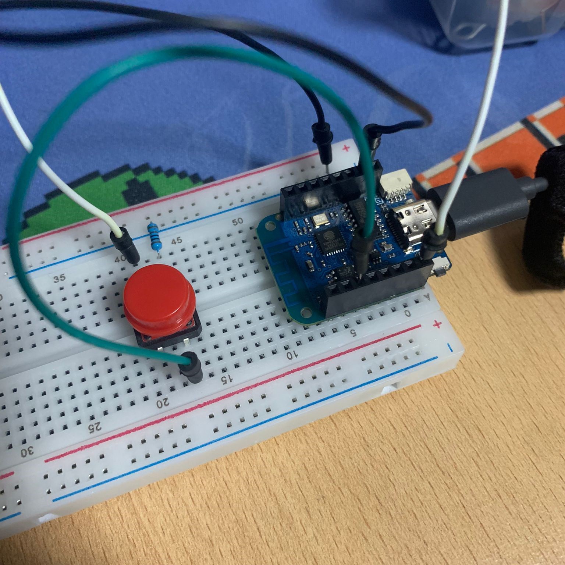
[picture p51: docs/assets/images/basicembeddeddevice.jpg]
basicembeddeddevice
  
</div>

<br>

<br>

### Wifi Manager
To connect the WeMos and any other embedded device that will be needed for my project I made use of the library WiFiManager. This allows the WeMos to connect to a wifi access point without needing to hard code the SSID and password inside the code. This is more user friendly.

<br>

<div align="center">
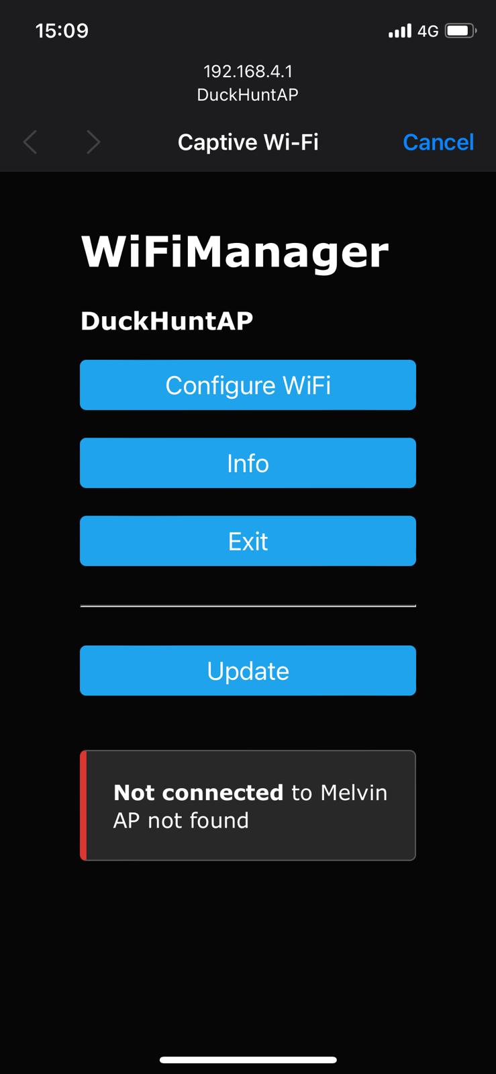
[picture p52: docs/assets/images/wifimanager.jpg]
wifimanager
  
</div>

<br>

### Gyroscope

I worked on getting data from the gyroscope. The gyroscope gives me 3 axis xyz data to see the tilt of the sensor. This will be used to determine the orientation of the controller.

<div align="center">
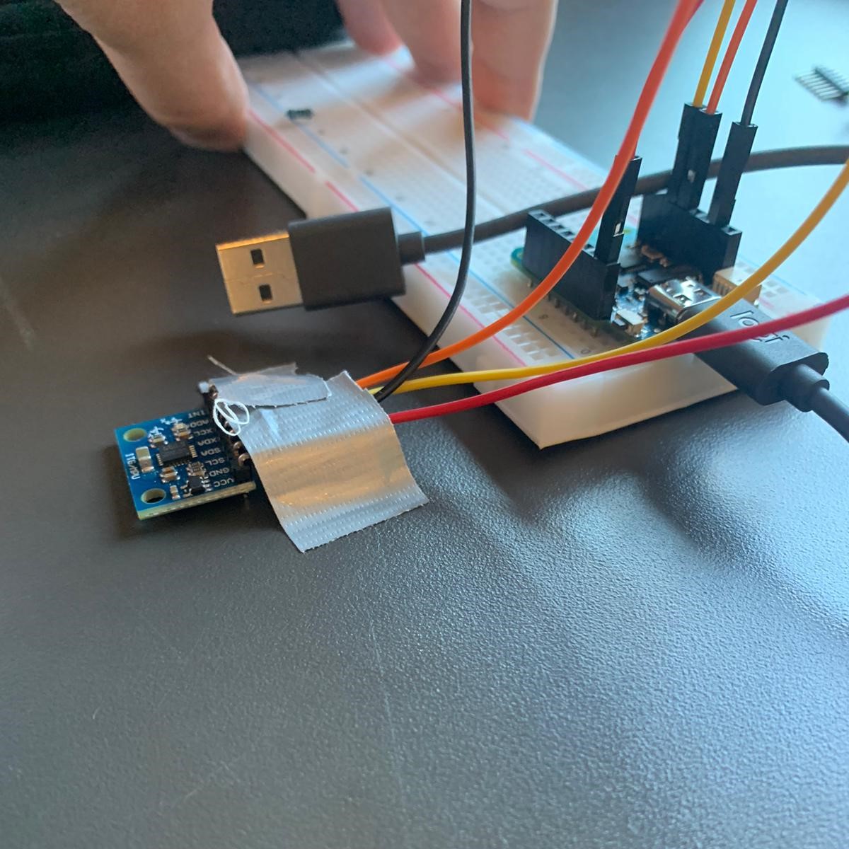
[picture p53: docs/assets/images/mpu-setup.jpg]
mpu-setup
  
</div>

<br>

<div align="center">
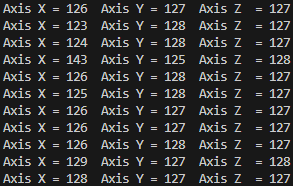
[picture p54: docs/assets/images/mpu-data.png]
mpu-data
  
</div>

<br>

### Documentation
During week 2 I worked on several portions of documentation. I started with fixing some images not correctly showing up in the documentation. After this I wrote documentation explaining my API. For now this only explains the endpoints for fetching, creating, deleting and updating players. I also went around all my documentatin to add some br tags to improve readability. Finally I worked throughout the week to keep my journal up to date to prevent having to write it all in one go.

In the weekend I additionally worked on writing some documentation about working with the MPU6050.

## Week 3
<hr>

### MPU6050
Improved mpu data collection by using the [DMP](embedded/technical_documentation.md#). The data collected is now processed before being retrieved from the sensor. 
<div align="center">
  mpu-data
</div>

<br>

### Concept sketches
To visualize the end product better I drew up some concept sketches.
<div align="center">
  product_concept
  cursor_concept
</div>

<br>

### Bluetooth

#### Bluetooth server
To connect the controller to the display in the future a form of communication was needed. I worked on setting up a bluetooth server that can receive data through a bluetooth connection.

I used the app: BluetoothLE (IOS)
<div align="center">
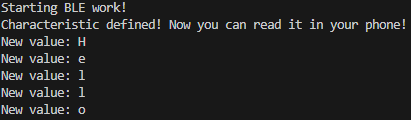
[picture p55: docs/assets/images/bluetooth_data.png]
bluetooth_data
  
</div>
<div align="center">
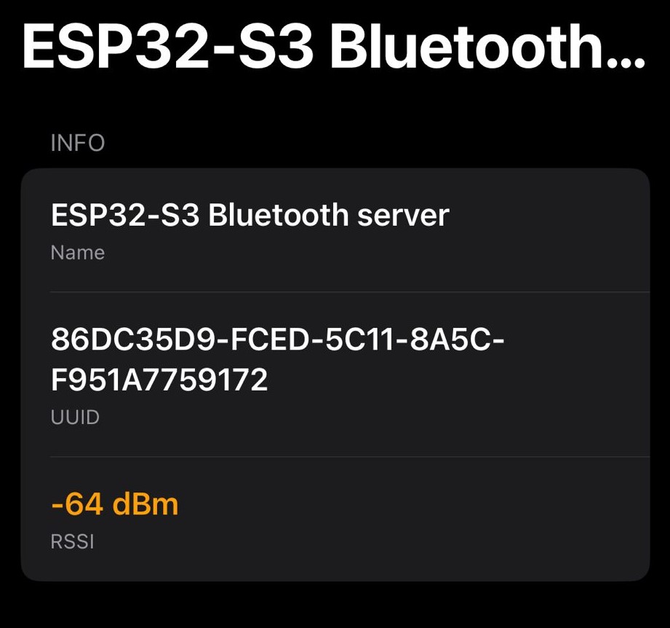
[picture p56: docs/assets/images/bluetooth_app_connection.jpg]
bluetooth_app_connection
  
</div>

#### Bluetooth client
To test the connectivity between the controller and the display. I established a Bluetooth client for the controller. This allows the controller to connect to the other ESP32

#### Reconnection
I also added an option to reconnect to the BT server when the device is disconnected. This wasn't working automatically before so I added this feature by making the server resume advertising after its device is disconnected.

#### Data communication
I worked on communicating between two ESP32's to send over the MPU data below is the result of this work:
<div align="center">
  bt-mpu-data
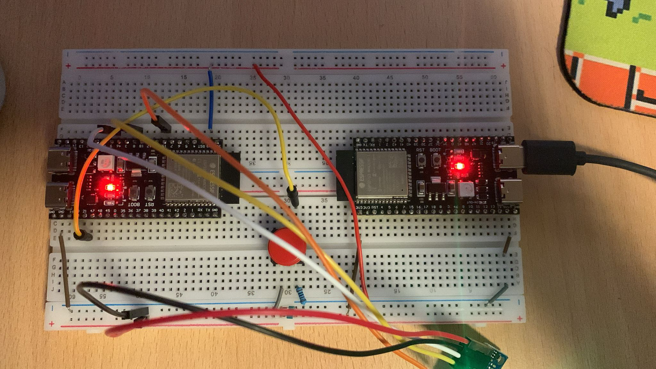
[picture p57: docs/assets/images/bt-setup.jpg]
bt-setup
  
</div>

<br>

### Switching WeMos to ESP32-S3
The WeMos allows for a wifi connection but not a bluetooth connection. Together with some other issues I encountered I decided to switch to the ESP32-S3. This not only allows me to use bluetooth but also opens some other options such as using 2 cores, better performance and ability to connect to 5Ghz wifi channels which the WeMos could not.

### Rubrics Frontend, Backend & Database
During the course of IoT we discussed the requirements of all 3 elements. From this I learned not much from the backend and frontend side of the discussion, but I did however get reminded to normalize my database. This is good information to get reminded of and I've added this to my todo list.

### Concept design for controller
I worked on drawing up some designs for my controller. This can be seen in the concept and design documentation.

I also started working on some prototype 3D models in fusion.
<div align="center">
  fusion-controller-prototype
</div>

<div align="center">
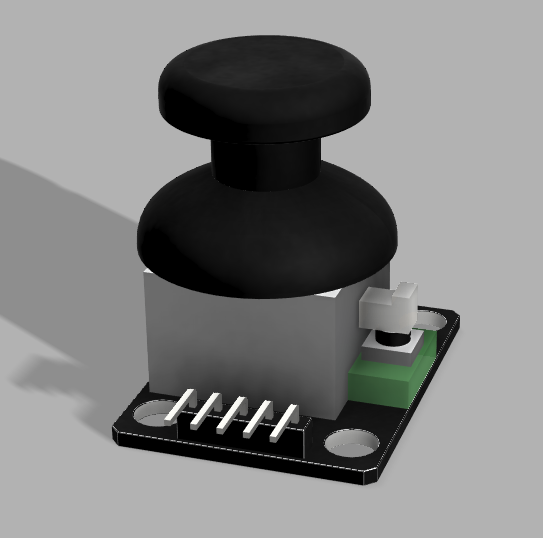
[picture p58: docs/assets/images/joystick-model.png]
joystick-model
  
</div>

## Week 4

### 3D printing
I worked on a fusion model for the controller. For this I used Fusion360.
<div align="center">
  bluetooth_app_connection
</div>
This model was mostly to get a feelig of the size of the controller to see if everything would fit the way I expted from inspecting it in the CAD.
<div align="center">
  bluetooth_app_connection
</div>
Some noticeable missing components in the CAD above are:

- Trigger button
- Hole for joystick
- DC DC Converter

After reviewing my print I changed the following properties:
- Changed the shell width from 1mm to 2mm
- Moved the battery holder cutting line down but keeping the size of the battery holder.

Next I worked on the design for the trigger button. I opened up a wii controller to see how this was done here. I noticed that the button was loose and was connected using a T join see picture below.

<div align="center">
  trigger-design
</div>

This joint allows the button to move up and down to press a button. I worked on making a system similair to this. For now I've only made the design of the button itself. I changed the button to have a sharper edge to allow for easier shooting. The wii controller has a softer edge which could lead to your finger sliding off easier when rapid firing.

<div align="center">
  wiicontrollerinside
</div>

### Display board
I worked on setting up the display board I ordered: [Link](https://nl.aliexpress.com/item/1005005865107357.html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) I encountered a lot of problems trying to get any example code to run. I looked into the most used resource for this screen through this repo: https://github.com/witnessmenow/ESP32-Cheap-Yellow-Display. None of the example seemed to work after some research I found out my screen used a slightly different model number than the repo. The display has an onboard ESP32-2432S024 while the repo used ESP32-2432S024. A repo with resources about this model: https://github.com/NoosaHydro/2.4inch_ESP32-2432S024/blob/main/6-User_Manual/Getting%20started%202.4%20Inch.pdf. 

I followed the [User manual](https://github.com/NoosaHydro/2.4inch_ESP32-2432S024/blob/main/6-User_Manual/Getting%20started%202.4%20Inch.pdf) in the Arduino IDE to see if I could get the display running. I plan on moving over to platform.io later but the documentation was written in Arduino.

To use the display a library is required called TFT_eSPI a important fact for using this library is that the library needs to configured before use. This is done by changing the User_Setup.h to use the correct pins and settings. This was all found in the user manual.

Setup a project using the right board in my case its the "esp32dev" in arduino in platformio this would be "Espressif ESP32 Dev Module"

#### Display board fusion model
In the future an enclosure needs to be made for the display. This is why I worked on making a fusion model of the display itself. I used the official dimensions provided by the official documentation from the store page.

<div align="center">
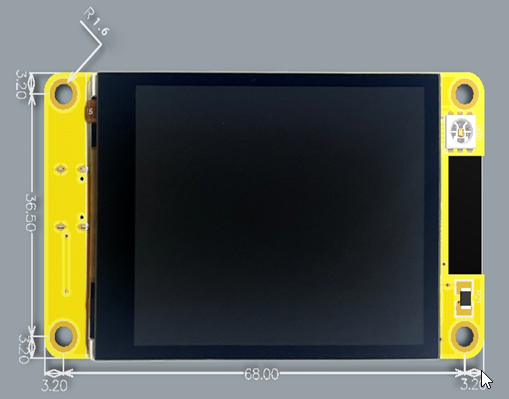
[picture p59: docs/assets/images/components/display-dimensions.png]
display-dimensions
  
</div>

<div align="center">
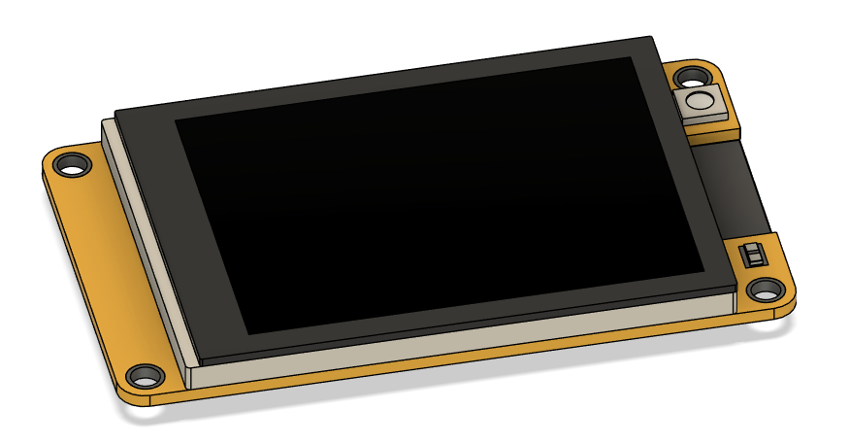
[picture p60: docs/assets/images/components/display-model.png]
display-model
  
</div>

### Additional additions to display code
Later in the week I worked on writing code for the display esp32. I moved over the bluetooth code from the esp32-s3 test project. I set up the TFTeSPI library with correct configurations. This involved looking up the specifics for the display as the UserSetup.h fil had to be edited to accomodate differing screens. I made some basic sprite renderings. I added a temporary background:
<div align="center">
  <img src="/assets/sprites/background.png" alt="display-model" style= image-rendering: pixelated;">
</div>

And a cursor:
<div align="center">
  display-model
</div>

The cursor is way too small on screen right now. I'm looking into currently if I can just resize the image in code otherwise I will just make my sprites bigger from now on.

## Week 5

### Reorganize embedded projects
Since the display arrived last week I still hadn't gotten around to moving all the code to the correct device. The WIFI/API connection was still in the controller project as this was done for testing purposes. I moved all the classes including Bluetooth and Wifi classes to the correct project.

### Removing bluetooth from project in favor for UDP
After having bluetooth and wifi running on the display I noticed that the screen wouldn't turn on anymore. I wasn't able to figure out the cause of this, but I think it's due to power consumption. Knowing this I had to make a decision since I didn't want to spend anymore time debugging this problem. I ended up ditching Bluetooth entirely in favor of using an UDP stream. The display now acts as a STA and AP which means it can connect to a wifi network but also host it's own access point. The controller connects to that access points and sends JSON formatted UDP packets which deliver any communication needed between the controller and display.

### Cursor moving
After establishing the UDP connection and parsing the data accordingly. I started working on translating the yaw, pitch and roll data from the gyroscope to logical values to move a cursor on screen. I was able to establish a satisfactory result allowing the user to now use the controller as a remote. Further improvements can be done as the gyroscope still seems to deviate slightly here and now. 

Additionally I added new sprites for the cursor to allow the user to see the sprite more easily and to allow the cursor to change to red. 

### Frontend Restyling
I worked on making a username input page. This will serve as the gateway for starting the game. A player will input their name into the page and this will be sent to the embedded devide to start the game. This allow the score to be stored with the provided name.

Also the admin page has been restyled to have a more retro game feel to it.

### 3D printing controller
I made some new adjustments to the base of the wii controller allowing the controller to hold the trigger button and be able to move it around a fixed access.

### API modifications
I worked on improving my API to allow future additions in new gateways to go smoothly. I added a routehandler that handles which controller should be created based on which route is being called.

### Database remodeling
I also remodeled the database so use a session based communication flow to allow a player to play more than one game in a session and to allow a game to be started from the frontend webpage

## Week 6

### API New Endpoints
I added endpoints for the new tables including the score, session and difficulty table. These can now all be viewed in the admin page located at localhost/admin. This allows for easier debugging of the database. It is also now possible to perform CRUD operations on these tables.

### 3D printing iterations
I worked on many iterations of the battery lid I added a clip at the front which can be used to open the battery lid. I also added 2 "nubs" on the other side. I also worked on designing the mechanisms for both the joystick and the trigger button press.
<div align="center">
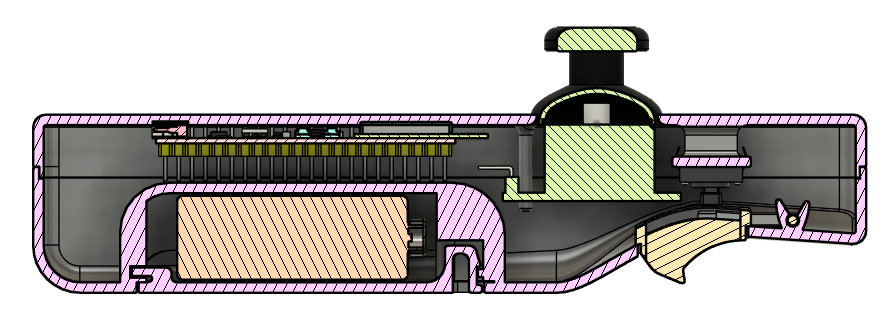
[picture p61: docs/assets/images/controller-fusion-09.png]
  
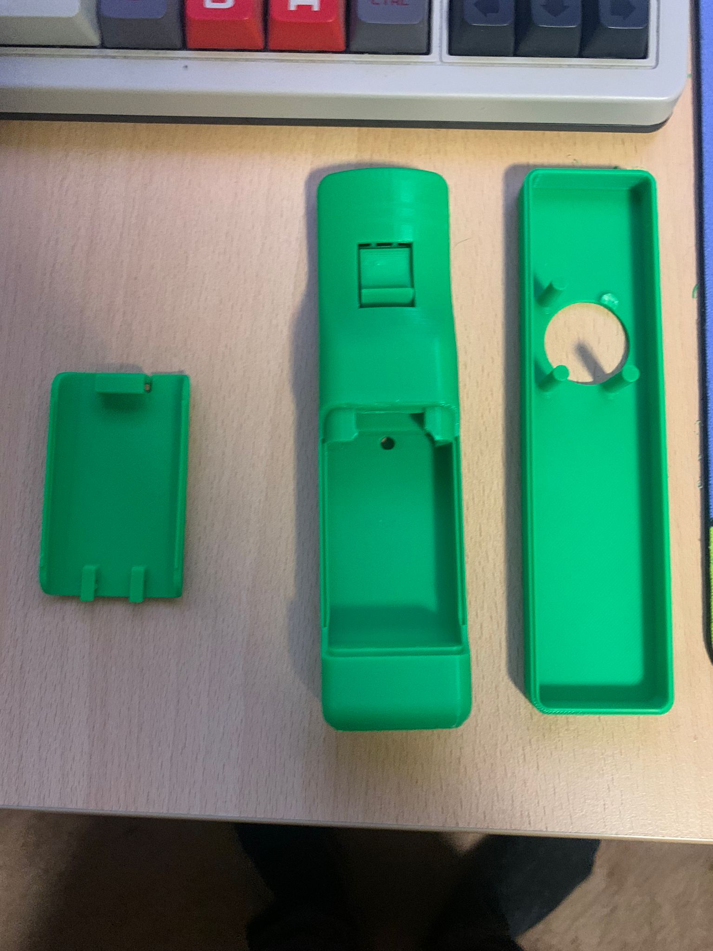
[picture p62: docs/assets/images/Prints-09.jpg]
prints
  
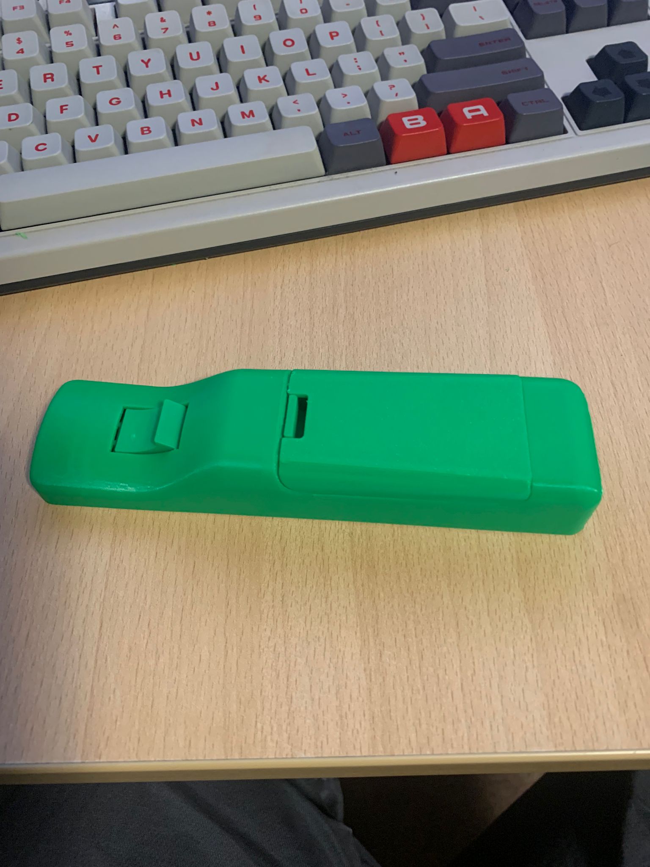
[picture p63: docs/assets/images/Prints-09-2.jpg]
prints
  
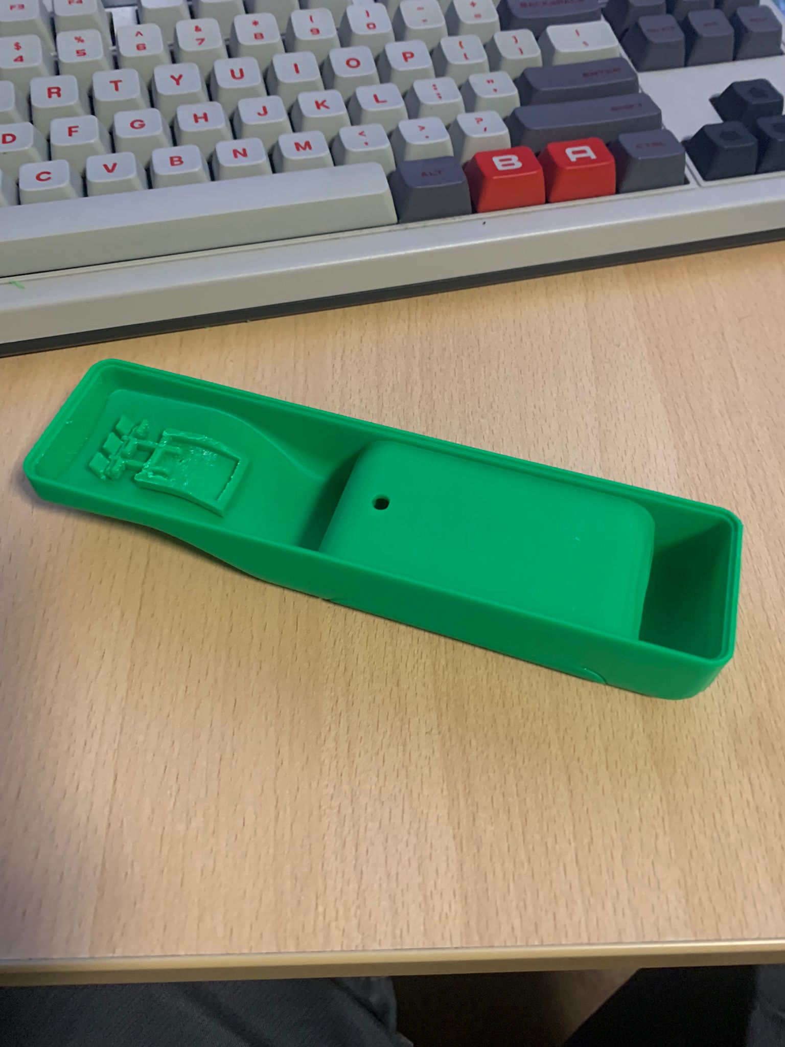
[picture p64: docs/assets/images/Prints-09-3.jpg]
prints
  
</div>

Some notes:

- PLA doesnt like bending so in a proffesional prototype the batterylid should be made from something else. It's prone to snapping right now.

After many.. MANY iterations a useable prototype was created that could hold the joystick, have a working trigger button, a batterylid and allows for the battery wires to go through to the inner part of the controller. There is also still room left to place the vibration motor and esp inside the controller.
<div align="center">
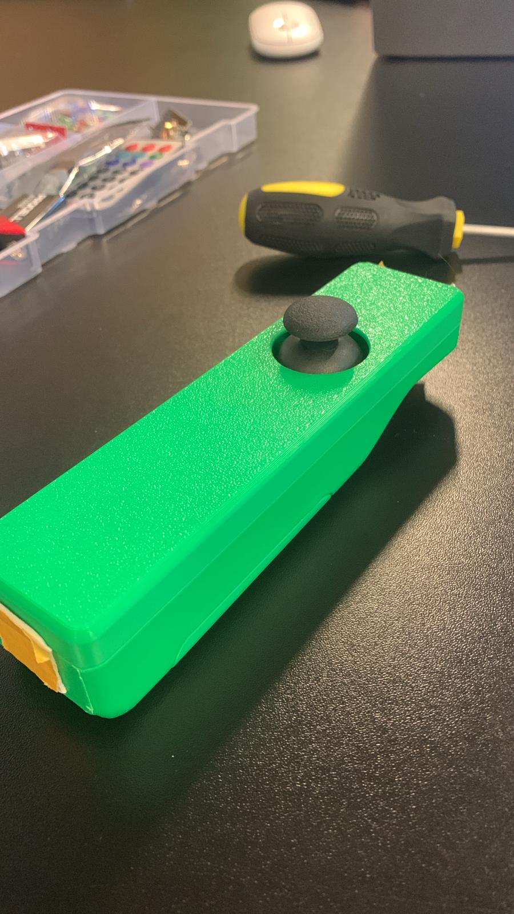
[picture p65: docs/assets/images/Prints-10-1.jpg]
prints
  
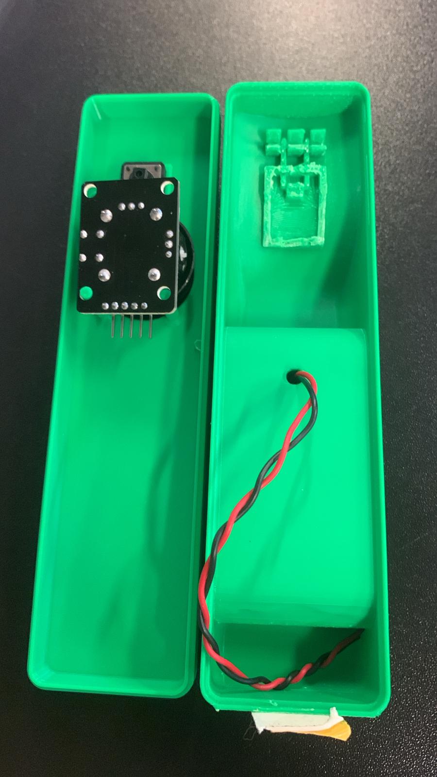
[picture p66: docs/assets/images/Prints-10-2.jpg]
prints
  
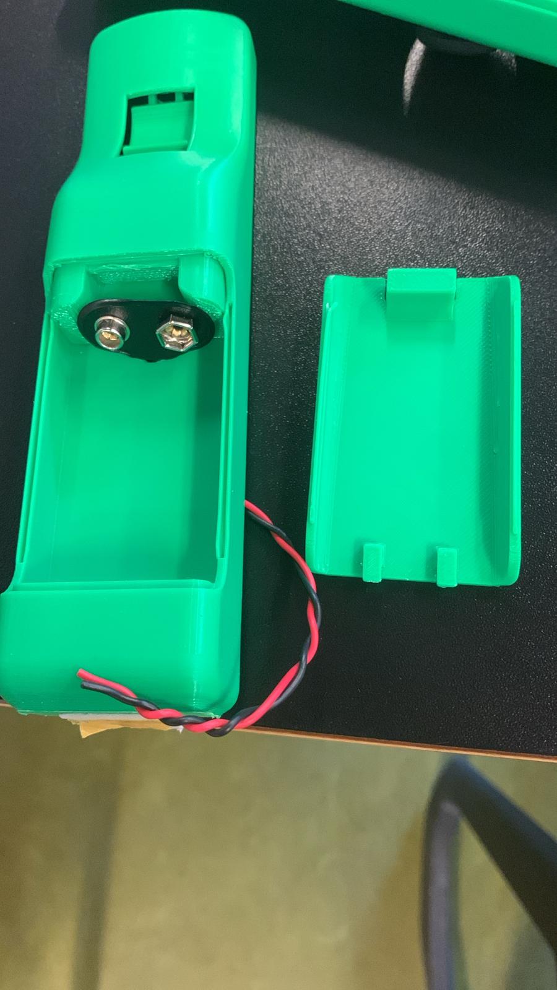
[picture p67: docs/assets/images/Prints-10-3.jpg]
prints
  

</div>

Only missing features now:

- Reliable way to store esp.
- Reliable way to store vibration motor.
- A way to convert 9v to 5v that can fit inside the controller.
- A reliable way to fasten the top of the controller to the bottom.

### Joystick code
After working on the print I started work on the joystick. The joystick consists of 2 potentiometers I worked on reading these values through the ADC pins. I then mapped the values received to a normalized range of -1.0 to 1.0 meaning top right is (1.0, 1.0) and top left is (-1.0, -1.0).

Then new code for the UDP connection was needed to send this data. I ended up just adding this data to the packet of the Gyro data this is the easiest way to do it for now as the console has no communication to the controller itself so telling the controller to send either the gyro or joystick is not possible yet. This is a possible improvement for the future.

## Week 7
I started of week 7 by finishing up some additions to the joystick code and in the weekend before week 7 I worked on a lot of iterations of 3d prints. A suitable prototype has been created that can hold all components. It's not perfect but using some tape or glue can make it perfect. Since the time is running out on the project this will suffice. 

### Feedback

**👩‍🎨 Concept and Design.**

**Reviewer: Lucas Hilgevoord**

**Feedback:** Maybe it is nice to add the tutorial you used in the beginning so others can follow that one is as well. I really like the prints and it looks pretty professional! Looks like you learned a lot. I would also explain a bit more why a user needs the things in the 'user needs' text.

**Takeaway:** I added a link to the tutorial used for the wii controller and updated my user needs. 

### Owl sprites and logic
I worked on adding the enemies to the game. For this I first had to add the sprites to the game. I did this by using aseprite to create a owl with 3 different animation sprites allowing for a good looking movement cycle.

Next I worked on the logic behind the owl allowing the sprite to cycle through the animation sprites and moving across the screen. I also worked on hit detection. The hit detection works but no firing has been implemented yet.

### Gameloop
As I'm nearing the end of my time I focused mostly on finishing up some loose ends like getting user input from frontend to insert into a session and fetching this data from the embedded device. This allows my embedded device to know the selected settings, player and the start time thats provided from javascript.

### Feedback

**🌐 Application Code.**

**Reviewer: Raymond Bookelman**

**Feedback:** This looks very good. You used REST methods, separated db from your logic.
small thingy for errors you added a single method/function add this also for your happy flow.
and I'm not sure why you add the $id id it's empty/null see comment in file.

**Takeaway:** I updated my api code to no longer use an id in the collection function. This was redundant code so this was good feedback to receive.

## Week 8

### API Updates
Added more endpoints namely the capability to add "Actions" actions are endpoints that don't strictly talk to just one table. The only action as of right now is the gethighscores action. This action communicates with both the player and score tables to retrieve a list of the highscores in descending order. An option is also present to specify the count of the highscores by adding the url paramater `?count={number}` you can specify the amount you want to receive.

### RGB Led control (Display)
To allow for more indication incases of the diplay not working properly or just to receive more information from the system. An RGB control was added to the Display project. The display has an onboard RGB Led that can be used for this task. The following statusses can now be shown:
Blue: System is starting
Yellow: Polling for session data
Green: Game is starting

### Frontend Session control
The capability was added to start a session from the frontend. The frontend now has input fields for the session id, username, difficulty and control mode. As soon as play is pressed these settings are saved in the session that was created before hand by the embedded device. The embedded device itself is polling the session with a fixed interval. As soon as the new data has been added to the session this is fetched by the embedded device and the game can then begin.

While the session is running the scores and settings can be viewed from the frontend which will upon clicking play switch views to a "playing" view. This also prevents any players from accidentally clicking play more than once.

## Week 9 

### Controller Assemble (Redesign)
I already worked on trying to assemble my controller today but I was unable to fit all the components inside the controller. 
Unfortunately this will most likely not be possible unless something like a PCB is used. Which is just not in scope at the moment. 
I will be trying to think of a new plan going forward and designing a simpler design which allows for a breadboard to be inside to allow for an easier assembling process.

The design I ended up settling on and printing was the following:
<div align="center">
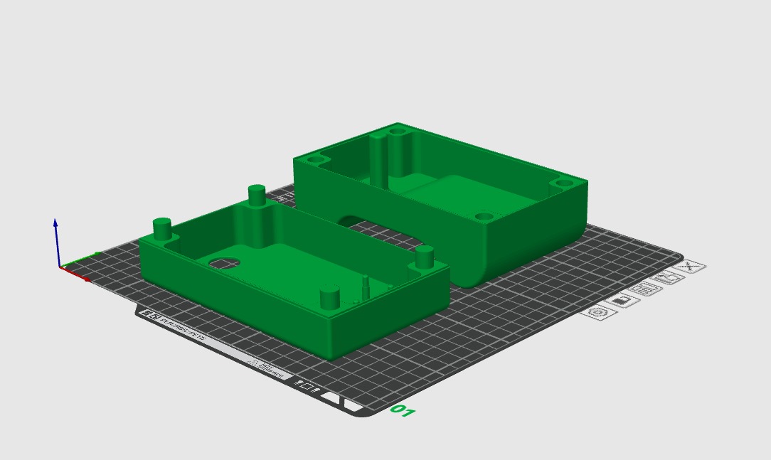
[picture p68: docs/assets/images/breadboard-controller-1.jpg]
  
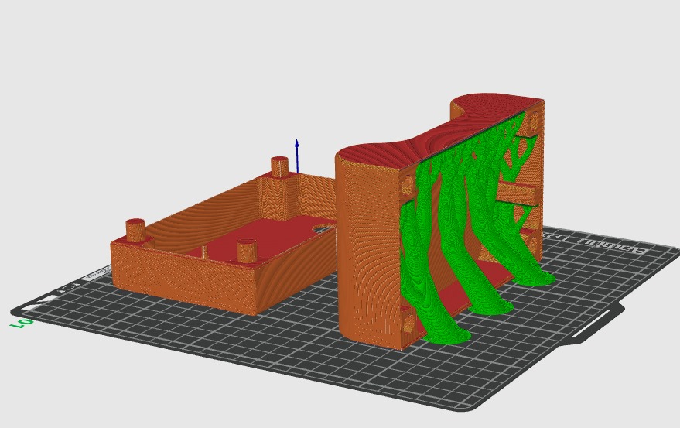
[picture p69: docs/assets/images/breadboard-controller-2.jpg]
  
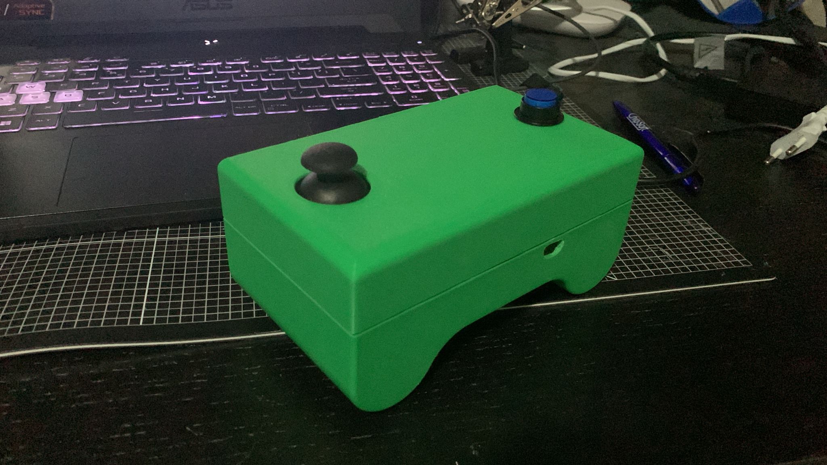
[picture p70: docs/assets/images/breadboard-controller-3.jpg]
  
</div>

The original design could still be used if a PCB was introduced since this would allow for no soldering being required for connecting most of the components.

### Display Highscores page and session page
On the embedded device the functionality has been added to show the highscores and the session id page has been modified to have a more pleasing look. Also the use of sprites has been removed from these simple pages as they don't require constant updating of the screen so the more easy to work with drawString function is plenty.

The highscores page makes use of the actions/gethighscores endpoint and specified that it only wants to receive 10. The benefit of not using sprites in this case is that you can just call drawString many times and not have to create and manage a sprite for each highscore.
<div align="center">
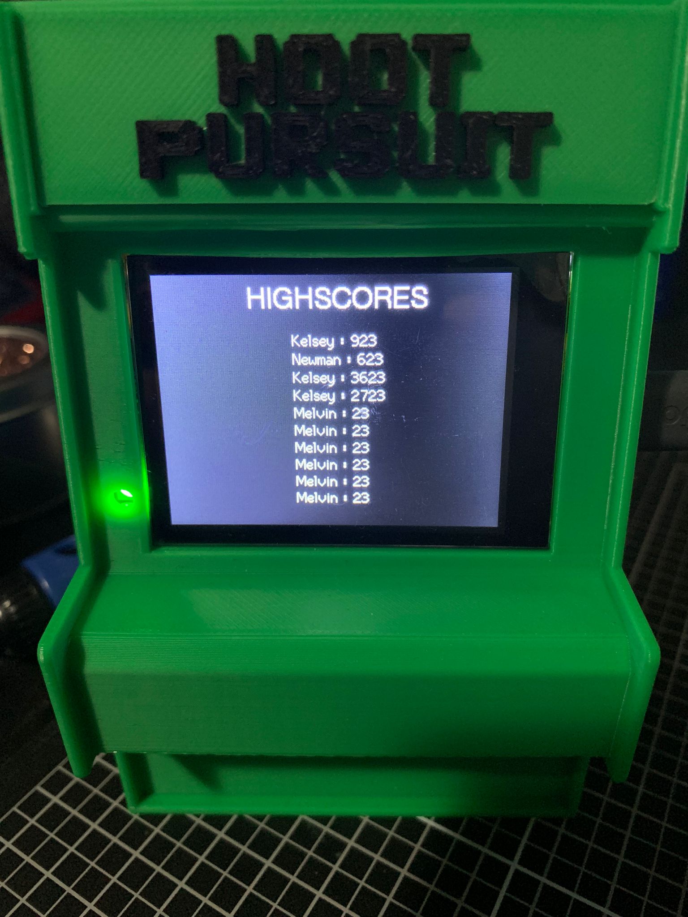
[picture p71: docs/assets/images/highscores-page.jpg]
highscores-page
  
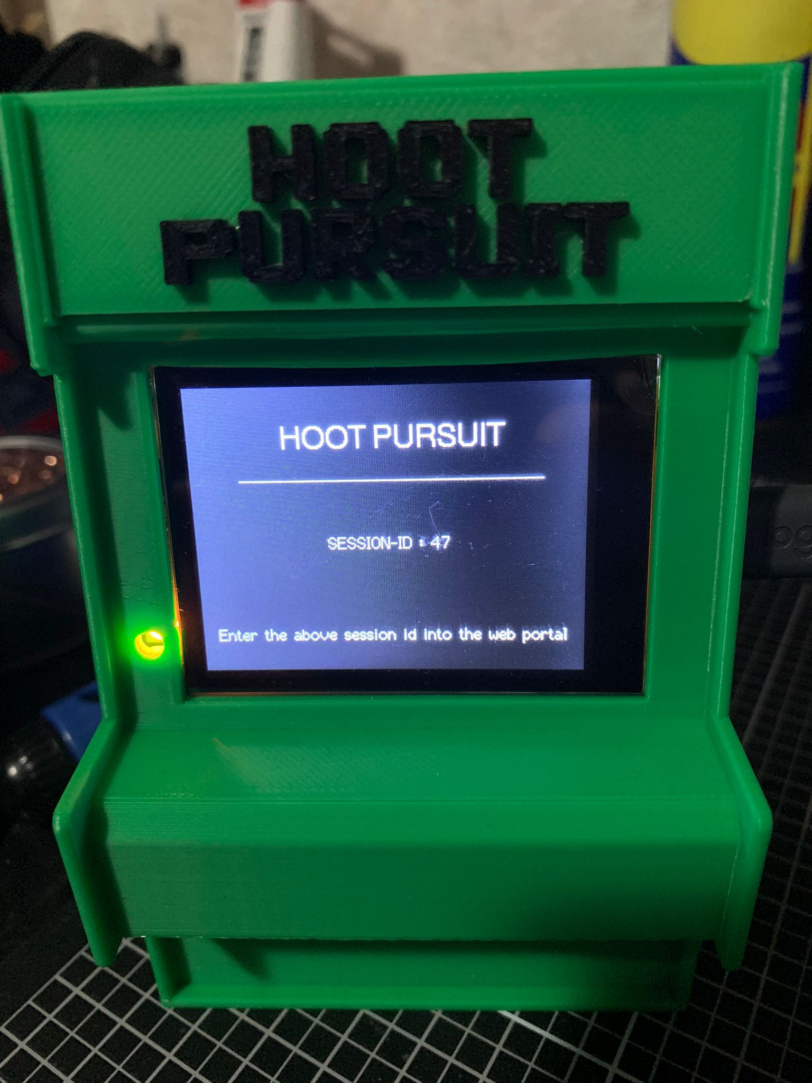
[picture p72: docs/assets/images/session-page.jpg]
session-page
  
</div>

### Display Retry/End session page
FInally in week 9 I worked on adding a screen to allow the user to end the session or choose to play another game.
<div align="center">
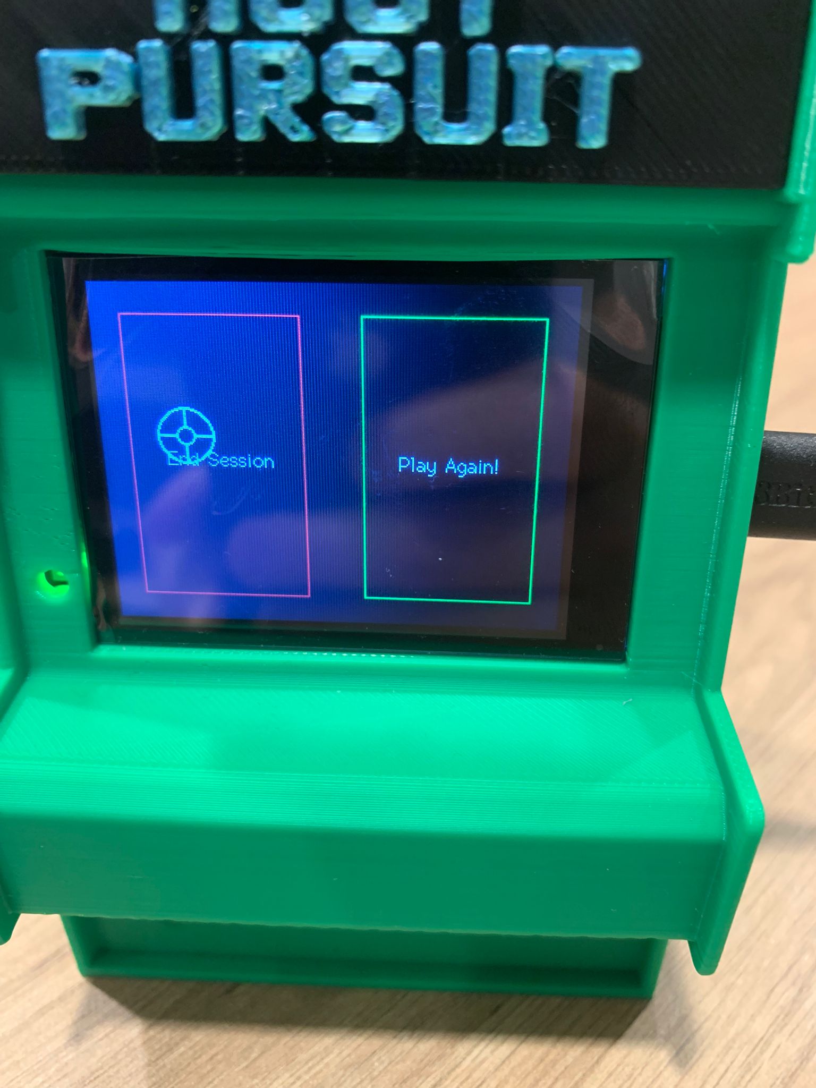
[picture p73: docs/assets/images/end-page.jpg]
end-page
  
</div>

## Week 10

### Implementing ESP-NOW 
I switched from UDP to ESP-NOW after experiencing delay which reduced the enjoyment of the gameplay. After having done multiple user tests where the main concern was the delay I focussed on this part. I researched Bluetooth, Udp and ESP-NOW and came to the conclusion through the most recent testing that ESP-NOW worked the best for my application.

### Finishing up all documentation
I worked hard on finishing on finishing all the documentation for both the embedded and web side. I also worked on the system architecture and finished up my research.

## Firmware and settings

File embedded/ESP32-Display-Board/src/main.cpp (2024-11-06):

/*
 * Author: Melvin Moes
 * Date: November 6, 2024
 * Description: The main entry point for the game console application. This file initializes the GameController instance. 
 * The setup function initializes the game controller. The loop function continuously calls the game controller's loop method, 
 * which handles the main game logic and rendering.
 * License: This project is licensed under the MIT License.
 */

#include "game_controller.h"

GameController game;

void setup() {
  game.init();
}

void loop() {
  game.loop();
}

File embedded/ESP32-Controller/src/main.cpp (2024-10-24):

/*
 * Author: Melvin Moes
 * Date: October 14, 2024
 * Description: The main program file for the motion controller project. It initializes the 
 * Serial communication and the MotionController instance. The loop function continuously runs the 
 * motion controller's main loop.
 * License: This project is licensed under the MIT License.
 */

#include "motion_controller.h"

MotionController controller;

void setup() 
{
  controller.init();
}

void loop() 
{
  controller.loop(); 
}

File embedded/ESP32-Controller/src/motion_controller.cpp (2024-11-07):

/*
 * Author: Melvin Moes
 * Date: November 6, 2024
 * Description: This class implements the MotionController header. It initializes the 
 * joystick and gyroscope, manages the ESP-NOW connection for sending data to the console and handles 
 * input from a button. The Init function sets up the necessary components, while 
 * the Run function processes joystick movements, button presses, and activates a vibration motor 
 * based on input. A separate task is created for handling gyroscope data.
 * License: This project is licensed under the MIT License.
 */

#include "motion_controller.h"

MotionController::MotionController()
{
    Serial.begin(BAUD_RATE);
}

void MotionController::init()
{
    Serial.println("\n------------[Initializing Game]------------");
    conn.init();
    conn.getMacAddress();
    joystick.init();
    gyro.init();
    pinMode(BUTTON_PIN, INPUT);
    pinMode(VIBRATION_MOTOR_PIN, OUTPUT);


    xTaskCreatePinnedToCore(
        gyroTask,
        GYRO_TASK_NAME,
        GYRO_TASK_STACK_SIZE,
        &gyro,
        GYRO_TASK_PRIORITY,
        &gyroTaskHandle,
        GYRO_TASK_CORE
    );

    xTaskCreatePinnedToCore(
        sendControllerDataTask,
        SEND_CONTROLLER_TASK_NAME,
        SEND_CONTROLLER_TASK_STACK_SIZE,
        this,
        SEND_CONTROLLER_TASK_PRIORITY,
        &sendControllerDataTaskHandle,
        SEND_CONTROLLER_TASK_CORE
    );
}

void MotionController::loop() 
{
    handleButtonPress();
    handleJoystickClick();
    vTaskDelay(SMALL_COOLDOWN / portTICK_PERIOD_MS);
}


void MotionController::sendControllerData()
{
    // Read joystick data
    joystick.readJoystickAxis();

    // Get data from gyroscope
    GyroData gData = gyro.getXY();
    JoystickData jData = joystick.getAxis();

    // Create a JSON document
    JsonDocument jsonDoc;
    jsonDoc["method"] = CONTROLLER_AXIS_DATA_METHOD;
    jsonDoc["data"]["gX"] = gData.x;
    jsonDoc["data"]["gY"] = gData.y;
    jsonDoc["data"]["jX"] = jData.x;
    jsonDoc["data"]["jY"] = jData.y;

    conn.sendData(jsonDoc);
}

void MotionController::sendTriggerInput()
{
    // Create a JSON document
    JsonDocument jsonDoc;
    jsonDoc["method"] = TRIGGER_METHOD;

    conn.sendData(jsonDoc);

}

void MotionController::sendJoystickClick()
{
    // Create a JSON document
    JsonDocument jsonDoc;
    jsonDoc["method"] = JOYSTICK_CLICK_METHOD;

    conn.sendData(jsonDoc);
}

void MotionController::handleButtonPress()
{
    unsigned long currentTime = millis();
    unsigned long elapsedTime = currentTime - lastButtonPressTime;

    bool currentButtonState = digitalRead(BUTTON_PIN);

    // Prevent holding down button
    if (currentButtonState && !previousButtonState)
    {
        if (elapsedTime > kButtonCooldown)
        {
            Serial.println("Button pressed");
            sendTriggerInput();
            lastButtonPressTime = currentTime;
            isVibrating = true;
            analogWrite(VIBRATION_MOTOR_PIN, VIBRATION_MOTOR_MAX);
        }
    }

    // Handle vibration duration
    if (isVibrating && (currentTime - lastButtonPressTime > kVibrationDuration))
    {
        // Stop vibrating
        analogWrite(VIBRATION_MOTOR_PIN, VIBRATION_MOTOR_MIN);
        isVibrating = false;
    }

    previousButtonState = currentButtonState; 
}

void MotionController::handleJoystickClick()
{
    unsigned long currentTime = millis();
    unsigned long elapsedTime = currentTime - lastJoystickClickTime;
    bool currentButtonState = joystick.readJoystickClick();

    // Prevent holding down button
    if (currentButtonState && !previousJoystickClickState)
    {
        if (elapsedTime > kJoystickClickCooldown)
        {
            Serial.println("Joystick Clicked!");
            sendJoystickClick();
            lastJoystickClickTime = currentTime;
        }
        
    }

    previousJoystickClickState = currentButtonState; 
}

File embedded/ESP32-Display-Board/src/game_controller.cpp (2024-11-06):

/*
 * Author: Melvin Moes
 * Date: November 6, 2024
 * Description: An implementation of the GameController class, which manages 
 * the game statemachine. It includes methods for initializing the game, handling the main game loop, 
 * and managing the game state. This class created a SpriteRenderer class for handling the display and sprites. 
 * It also integrates the Connections class for managing network connectivity 
 * and communications. A separate task is created to manage Wi-Fi connections 
 * concurrently. 
 * License: This project is licensed under the MIT License.
 */

#include "game_controller.h"

GameController::GameController() 
{
    Serial.begin(BAUD_RATE);
}
GameController::~GameController()
{
    // Delete the tasks on game exit to free up resources
    if (connTaskHandle != NULL) vTaskDelete(connTaskHandle);
}

void GameController::init()
{
    xTaskCreatePinnedToCore(
        connectionsTask,
        CONN_TASK_NAME,
        CONN_TASK_STACK_SIZE,
        &conn,
        CONN_TASK_PRIORITY,
        &connTaskHandle,
        CONN_TASK_CORE
    );
    vTaskDelay(TIMEOUT_DELAY / portTICK_PERIOD_MS);
    Serial.print("Init: Executing on core ");
    Serial.println(xPortGetCoreID());

    initLed();
    setLedRGB(blue);
    while(!conn.getConnection())
    {
        vTaskDelay(TIMEOUT_DELAY / portTICK_PERIOD_MS);
        Serial.print(".");
    }
    
    sRender.init(SCREEN_ROTATION, true, TFT_BLACK);
}

void GameController::loop()
{
    switch(state)
    {
        case Intro:
            // Intro screen
            showIntro();
            break;
        case Playing:
            // Gameplay
            play();
            break;
        case EndGame:
            // Fill in name
            end();
            break;
        case ShowingHighScores:
            // Show highscores from database
            showHighScores();
            break;
        default:
            Serial.println("State Error Unrecognized state: " + state);
            break;    
    }
    vTaskDelay(TIMEOUT_DELAY / portTICK_PERIOD_MS);
}

void GameController::showIntro()
{
    Serial.println("------Showing Intro Sequence------");
    

    // Create session and show its id on screen
    settings = {};
    while(settings.sessionId == 0) {
        settings.sessionId = conn.createSession();
        sRender.renderIntro(settings.sessionId);
        vTaskDelay(TIMEOUT_DELAY / portTICK_PERIOD_MS);
    }
    
    // Start polling until a player id is found
    Serial.print("Start polling.");
    JsonDocument response;
    int playerId = 0;
    setLedRGB(yellow);

    while(settings.playerId  == 0)
    {
        response = conn.getSessionById(settings.sessionId);
        if(response["player_id"]) {
            settings.playerId = response["player_id"];
            settings.difficultyId = response["difficulty_id"];
            settings.useGyro = response["use_gyro"];
            Serial.println("Player connected to session!");
            Serial.printf("Difficulty: %d\nPlayerId: %d\nUse gyro: %d\n" , settings.difficultyId, settings.playerId, settings.useGyro);
        }

        vTaskDelay(TIMEOUT_DELAY / portTICK_PERIOD_MS);
    }
    Serial.println();
    setLedRGB(green);
    state = Playing;
}

void GameController::play()
{
    Serial.println("------Start Gameplay------");

    settings.score = 0;
    // conn.setListenForPackets(true);
    sRender.gameLoop(settings);
    conn.createScore(settings.sessionId, settings.score);
    // conn.setListenForPackets(false);

    state = ShowingHighScores;
}

void GameController::showHighScores()
{
    Serial.println("------Showing Highscores------");
    
    // Delay to let highscores update
    vTaskDelay(TIMEOUT_DELAY / portTICK_PERIOD_MS);

    sRender.renderHighscores(conn.getHighscores());
    state = EndGame;
}

void GameController::end()
{
    Serial.println("------Ending Game------");

    // conn.setListenForPackets(true);
    bool keepPlaying = sRender.renderEndScreen(settings.useGyro);
    // conn.setListenForPackets(false);

    if(keepPlaying) {
        state = Playing;
    } else {
        conn.endSession(settings.sessionId);
        state = Intro;
    }

}

void GameController::initLed()
{
    // Initialize GPIO pins for RGB LED
    pinMode(LED_PIN_R, OUTPUT);
    pinMode(LED_PIN_G, OUTPUT);
    pinMode(LED_PIN_B, OUTPUT);

    // Initialize LED control channels
    ledcSetup(LED_R_CHANNEL, kFreq, kResolution);
    ledcSetup(LED_G_CHANNEL, kFreq, kResolution);
    ledcSetup(LED_B_CHANNEL, kFreq, kResolution);
    
    // Attach channels to pins
    ledcAttachPin(LED_PIN_R, LED_R_CHANNEL);
    ledcAttachPin(LED_PIN_G, LED_G_CHANNEL);
    ledcAttachPin(LED_PIN_B, LED_B_CHANNEL);
}

void GameController::setLedRGB(RGBColor color, float brightness)
{
    ledcWrite(LED_R_CHANNEL, 255 - color.r * brightness);
    ledcWrite(LED_G_CHANNEL, 255 - color.g * brightness);
    ledcWrite(LED_B_CHANNEL, 255 - color.b * brightness);
}

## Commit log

2024-09-12 Setup wifi manager for embedded device
2024-09-12 Setup a ESP32 project for testing
2024-09-12 Working api call from embedded device
2024-09-12 Able to fetch data from embedded device
2024-09-12 Able to fetch and create players from embedded device
2024-09-13 MPU arduino library and datasheet
2024-09-13 Added a calibrate function to gyroscope
2024-09-15 Added a wiring diagram for the MPU
    [MPU6050-diagram.fzz]
2024-09-17 Added a Bill of materials table
2024-09-18 Created a new ESP32 project (Discarding WeMos as controller)
2024-09-18 Updated journal (Bluetooth client & WeMos switch)
2024-09-19 Able to send Yaw&Pitch data to Display
2024-09-19 Able to send Yaw/Pitch data through BT
2024-09-19 Changed wiring diagram to ESP32-S3
    [MPU6050 (WEMOS - Deprecated)-diagram.fzz, MPU6050-diagram.fzz]
2024-09-19 Added a project wiring diagram
    [PROJECT-diagram.fzz]
2024-09-22 Added print files for controller
    [Controller-Bottom.3mf, Controller-Battery-Lid.3mf, Controller-Top.3mf]
2024-09-23 Added all fusion design files
    [9V.Battery v1.f3d, Joystick PCB v2.f3d, MPU_6050 v1.f3d]
2024-09-25 Added design files
    [Trigger-test.3mf, Trigger-test.f3d, Trigger.3mf]
2024-09-25 Working arduino ide code for the display
2024-09-25 Updated journal (Display board)
2024-09-25 Created a fusion model for the display
    [ESP32-2432S024 Display.f3d, Trigger-test.f3d]
2024-09-30 Added API to the display board project
2024-10-03 Able to send gyro data to move cursor (sort of)
2024-10-03 Improved gyro sending speed
2024-10-03 Small fix to gyroscope code
    [Gyroscope.cpp]
2024-10-07 Added BOM components
2024-10-07 Added some vibration motor test code
    [MotionController.cpp, utilities.h]
2024-10-08 Added new 3mf files and removed redundant ones
    [Controller-Bottom.3mf, Controller-Battery-Lid-V5.3mf, Controller-Battery-Lid.3mf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]
2024-10-09 Added new and updated component fusion files
    [ESP32-2432S024 Display v4.f3d, Joystick PCB v3.f3d, Simple-Embedded-Button v4.f3d]
2024-10-09 Updated main design file and added updated 3mf files
    [BatteryLid v34.3mf, Bottom v34.3mf, Controller-Battery-Lid-V5.3mf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]
2024-10-09 Updated journal (3d printing)
2024-10-10 Added 3mf files
    [BatteryLid v34.3mf, BatteryLid-v36.3mf, Bottom v34.3mf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]
2024-10-10 Updated journal (3d printing full controller)
2024-10-12 Updated motion controller design file and created a vibration motor component model
    [Vibration-Motor v1.f3d]
2024-10-12 Removed old versiopns and added dc-dc stepdown
    [DC-DC Stepdown (Unfinished) v2.f3d, ESP32-2432S024 Display.f3d, Joystick PCB v2.f3d]
2024-10-12 Updated all 3mf files
    [BatteryLid-v36.3mf, BatteryLid-v48.3mf, Bottom-v36.3mf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]
2024-10-13 Fixes for future prints
    [BatteryLid-v50.3mf, Bottom-v50.3mf, DC-DC Stepdown (Unfinished) v2.f3d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]
2024-10-13 Removed old 3mf files
    [BatteryLid-v48.3mf, Bottom-v48.3mf, Top-v48.3mf]
2024-10-13 Updated fusion and print files
    [BatteryLid-v50.3mf, BatteryLid-v53.3mf, Bottom-v50.3mf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]
2024-10-14 Prevents cursor from going offscreen when using a joystick
    [GameController.cpp]
2024-10-14 Display x and y now switches between gyro and joystick
2024-10-14 Updated MPU6050 diagram to include int pin
    [MPU6050-diagram.fzz]
2024-10-14 Material decision added
2024-10-14 Added author comments to all esp32-controller files
2024-10-14 Moved gyro and joystick dependencies out of udp by making a generic send json function
2024-10-17 Added collision detection and timed delays
    [SpriteRenderer.h]
2024-10-17 Updated BOM
2024-10-18 Added delay to trigger press and vibration motor now functions
    [Joystick.cpp, MotionController.cpp]
2024-10-20 Added RGB led control and made a session api call
2024-10-21 Added the option to use filters in queries
2024-10-21 api filters bug fix
2024-10-23 Can now add difficulty and control method into session
    Also after submitting the screen switches to a "playing" screen
2024-10-24 Added design files for display and enclosure
    [Console Enclosure Prototype v5.f3z, ESP32-2432S024 Display v5.f3d]
2024-10-24 Updated concept and design (moved out print info to create&test)
2024-10-24 Applied code conventions to display board project
2024-10-25 Added new design files and stl files for controller
    [Bottom-v55.3mf, DC-DC Stepdown v4.f3d, Top-v55.3mf]
2024-10-25 Added documentation for console banner
    [Banner-v11.3mf, BannerProject.gcode.3mf, Bottom-v55.3mf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]
2024-10-26 Added new design files with tolerance fixes
    [BannerProject.gcode.3mf, Console Enclosure Prototype v14.f3z, Console-Banner-v11.3mf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]
2024-10-26 Added a wiring diagram and remapped some pins
    [MPU6050 (WEMOS - Deprecated)-diagram.fzz, MPU6050-diagram.fzz, Motion Controller Electronics Diagram Project v3.f3z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]
2024-11-01 Added controller breadboard variant design files
    [Breadboard-Controller-Bottom-v5.3mf, Breadboard-Controller-Top-v5.3mf]
2024-11-01 Fixed pins and added new button logic
    [motion_controller.cpp, utilities.h]
2024-11-01 Added a highscore page and some bug fixes
    [Connections.cpp, game_controller.cpp, sprite_renderer.h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]
2024-11-01 Fixed gyro option from not working
    [Gyroscope.cpp, motion_controller.cpp]
2024-11-03 Fixed score retention through session bug
    [Connections.cpp, game_controller.cpp, sprite_renderer.h]
2024-11-03 Fixed button press and increased vibration duration
    [motion_controller.cpp]
2024-11-03 Removed axis debug text and fixed frontend bug
    [sprite_renderer.h, udp_connection.cpp]
2024-11-04 Applied kebab-case
2024-11-06 Established a esp-now connection replacement for UDP
    [Connections.cpp, connections.cpp, game_controller.cpp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]
2024-11-06 updated some comments and added wiring diagram explanation
